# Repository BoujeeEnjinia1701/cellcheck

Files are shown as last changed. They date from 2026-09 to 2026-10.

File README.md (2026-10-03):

# CellCheck

     

**Area:** Circular Materials · **TRL:** 3 of 9 (proof of concept on paper) · **Value-engineering target:** about $175 USD (a hypothetical control target, not a limit) · **Difficulty:** 3 of 5

A second-life battery cell grader: it measures capacity, internal resistance and self-discharge of salvaged lithium cells and sorts them into matched groups for rebuilt packs such as SwapCell.

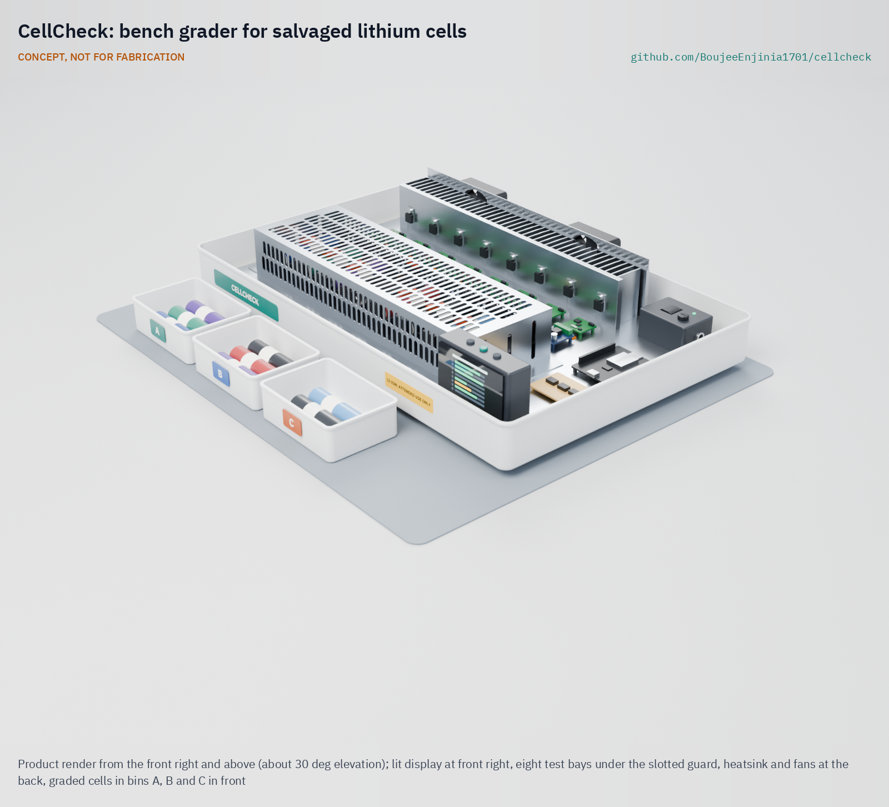
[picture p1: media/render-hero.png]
CellCheck: bench grader for salvaged lithium cells, product render


[Exploded render](media/render-exploded.png) · [Detail render](media/render-detail.png) · [Interactive 3D model](media/viewer.html) · [Concept blueprint (PDF)](media/concept-blueprint.pdf) · [General arrangement CCK-DWG-001 (PDF)](cad/drawings/CCK-DWG-001.pdf) · [Sizing note CCK-CAL-001](docs/04-calcs/01-sizing.md) · [Prototype build plan](docs/05-build-plan.md) · [Design decisions](docs/06-design-decisions.md) · [Review note](docs/REVIEW.md)

## Concept rationale

Most cells in a discarded laptop, power tool or e-bike pack still work, but nobody knows which ones. CellCheck measures the three things that decide whether a cell is worth reusing: how much charge it holds, how much its voltage sags under load (internal resistance) and whether it leaks charge at rest (self-discharge). It then groups good cells so that each parallel group in a rebuilt pack has nearly the same capacity. Eight independent channels, four-wire contacts and a passive 14-day rest rack keep the tool cheap while grading 12 typical cells in an attended 10 h working day (CCK-CAL-001, a paper estimate with no margin).

It is open and garage-buildable because the people who reuse cells are repair shops, makerspaces and small off-grid installers, not laboratories. It uses off-the-shelf charger and current-monitor modules, runs from a certified 12 V adapter so no one wires mains, and writes its thresholds and results to plain files that anyone can check. A published grading method also lets different workshops compare cells on the same terms.

## Burning platform

The world produced 62 million tonnes of e-waste in 2022, and only 22.3 % was documented as collected and recycled; in Africa the figure was below 1 % ([UNITAR, Global E-waste Monitor 2024](https://unitar.org/about/news-stories/press/global-e-waste-monitor-2024-electronic-waste-rising-five-times-faster-documented-e-waste-recycling)). Much of what is thrown away still has value: IBM Research India found that discarded 85 Wh laptop packs kept a median of 73 % of their design capacity ([Chandan et al., ACM DEV 2014](https://www.dgp.toronto.edu/~mjain/UrJar-DEV-2014.pdf)).

Discarded lithium batteries are also a fire hazard. The US EPA found 245 fires at 64 waste facilities from 2013 to 2020 caused, or likely caused, by lithium-ion batteries ([US EPA, 2021](https://www.epa.gov/system/files/documents/2021-08/lithium-ion-battery-report-update-7.01_508.pdf)), and the UK counted more than 1,200 battery fires in bin lorries and waste sites in the year to May 2024 ([National Fire Chiefs Council and Material Focus](https://nfcc.org.uk/over-1200-battery-fires-in-bin-lorries-and-waste-sites-across-the-uk-in-last-year/)). People who rebuild packs from untested cells face the same hazard on their own benches. Grading keeps usable cells in service and sends the rest to proper recycling instead of the bin.

## Where it could be used

### By industry

| Industry | Use |
| --- | --- |
| Electronics and e-bike repair | Sort cells from dead packs, reject bad ones and rebuild matched packs with a record per cell |
| Battery collection and recycling | Separate reusable cells from those that go to recycling at collection points and micro-factories (ReflowEconomy) |
| Off-grid energy | Low-cost graded cells for lights, small storage packs and solar home kits |
| Education and makerspaces | Teach battery health, safety and measurement with a documented, supervised tool |
| Research | Build data sets of second-life cell capacity and resistance with a published method |

### By country or region

| Country or region | Why it matters there |
| --- | --- |
| United Kingdom | More than 1,200 battery fires in bin lorries and waste sites in the year to May 2024, up from about 700 in 2022 ([NFCC and Material Focus](https://nfcc.org.uk/over-1200-battery-fires-in-bin-lorries-and-waste-sites-across-the-uk-in-last-year/)) |
| United States | 245 lithium-ion battery fires at 64 waste facilities from 2013 to 2020 ([US EPA](https://www.epa.gov/system/files/documents/2021-08/lithium-ion-battery-report-update-7.01_508.pdf)); many repair shops and makers already rebuild packs |
| European Union | Collection targets for portable batteries rise to 63 % by the end of 2027 and 73 % by the end of 2030 under the Batteries Regulation ([EPBA summary](https://www.epba.eu/policy/eu-directive/eu-batteries-regulation)), so more cells will reach sorting points |
| India | The Battery Waste Management Rules, 2022 require all waste batteries to be collected and sent for recycling or refurbishment ([Press Information Bureau](https://www.pib.gov.in/PressReleasePage.aspx?PRID=1854433)); refurbishers need a documented way to test cells |
| Kenya and East Africa | Second-life lithium storage lowered the cost of electricity in 97.2 % of modeled scenarios for Kenyan primary schools ([Hirmer et al., Scientific Reports, 2023](https://www.nature.com/articles/s41598-023-28377-7)); Africa formally recycles less than 1 % of its e-waste ([UNITAR](https://unitar.org/about/news-stories/press/global-e-waste-monitor-2024-electronic-waste-rising-five-times-faster-documented-e-waste-recycling)) |
| Colombia and Latin America | Researchers in Colombia measured cells from laptop packs ranging from 0.04 to 2.50 Ah and showed that grouping by measured values builds better packs ([Olivero-Ortiz et al., PLOS One, 2026](https://journals.plos.org/plosone/article?id=10.1371%2Fjournal.pone.0353394)) |

## What sparked the idea

The starting point was UrJar, a 2014 IBM Research India project in Bangalore that rebuilt cells from 32 discarded ThinkPad laptop packs into lighting units for street vendors ([Chandan et al., ACM DEV 2014](https://www.dgp.toronto.edu/~mjain/UrJar-DEV-2014.pdf)). The study showed that most of the packs still held useful capacity, yet after reading each pack's capacity through the laptop, the researchers selected individual cells by checking that their terminal voltage was above 3.7 V. A voltage check says little about a cell's capacity, internal resistance or self-discharge, which decide how long a rebuilt pack lasts and how safely it ages. CellCheck turns that hand check into a repeatable, multi-channel grading step that any repair bench could run.

## Problem

Salvaged lithium cells are cheap but unknown; building packs from untested cells causes early failure and fires. Cells from one pack can differ widely in capacity and resistance, and in a series string the weakest cell limits the pack and is stressed hardest. Single-cell hobby testers are too slow for pack-scale sorting, and closed multi-slot analyzers do not track self-discharge, build matched groups or keep open records.

Full problem statement: [docs/01-problem.md](docs/01-problem.md)

## Concept

A second-life battery cell grader: it measures capacity, internal resistance and self-discharge of salvaged lithium cells and sorts them into matched groups for rebuilt packs such as SwapCell.

Eight channels each charge a cell at 1 A, measure DC internal resistance with a 0.5 A then 2.0 A pulse in the IEC 61960 pattern, discharge at 1 A to measure capacity and recharge until the cell reads 4.10 V under current. Cells then rest 14 days in a printed rack and come back for a voltage check. Software grades each cell (A, B, C or reject) and builds groups for any series and parallel count, with each parallel group within ±1 % of the mean capacity. A hardware watchdog, per-channel undervoltage comparators and 3 A cell fuses cover single faults. The sizing note CCK-CAL-001 finds 6.33 h of channel time per typical cell, 12.0 cells per attended 10 h day, 33.6 W of peak heat with MOSFET cases at about 59 °C, 460 x 300 x 85 mm and 4.91 kg, and $172.40 in parts, $2.60 under the $175 budget.

SwapCell stays in the pitch. Its reference pack uses new high-current cells, which graded laptop cells cannot match, so a second-life variant is planned: the TRL 3 study finds a low-current storage pack for PowerBox (about 334 Wh, 165 W) feasible, and e-bike use is ruled out. Amish decided on 2026-09-25 to go with this recommendation, and on 2026-10-02 to send the study to the SwapCell and PowerBox projects as a proposal; it needs their agreement (see the decision records [CCK-DDR-001](docs/decisions/0001-trl2-review-decisions.md) and [CCK-DDR-002](docs/decisions/0002-recommendations-accepted.md)).

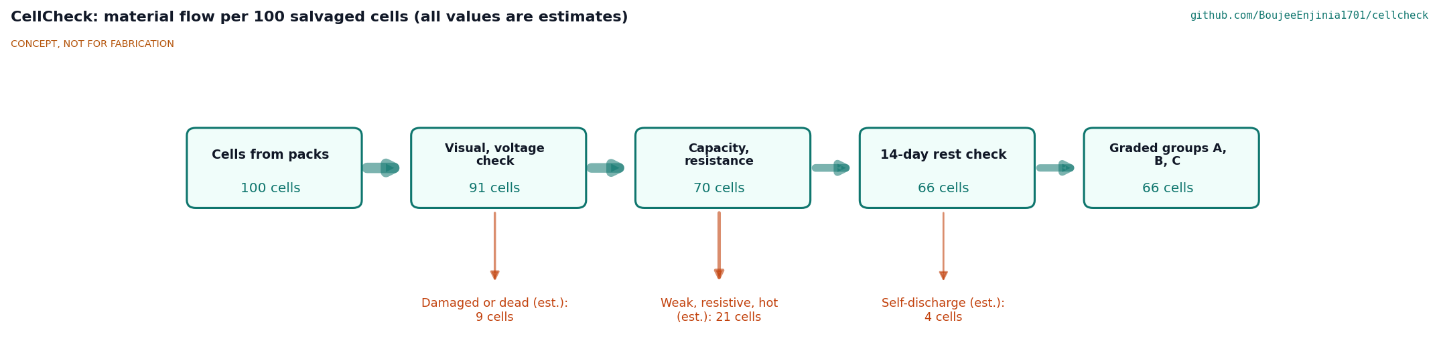
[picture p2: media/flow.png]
Material flow per 100 salvaged cells


Full design precis: [docs/02-concept.md](docs/02-concept.md) · Requirements: [docs/03-requirements.md](docs/03-requirements.md) · Calculations: [docs/04-calcs/01-sizing.md](docs/04-calcs/01-sizing.md)

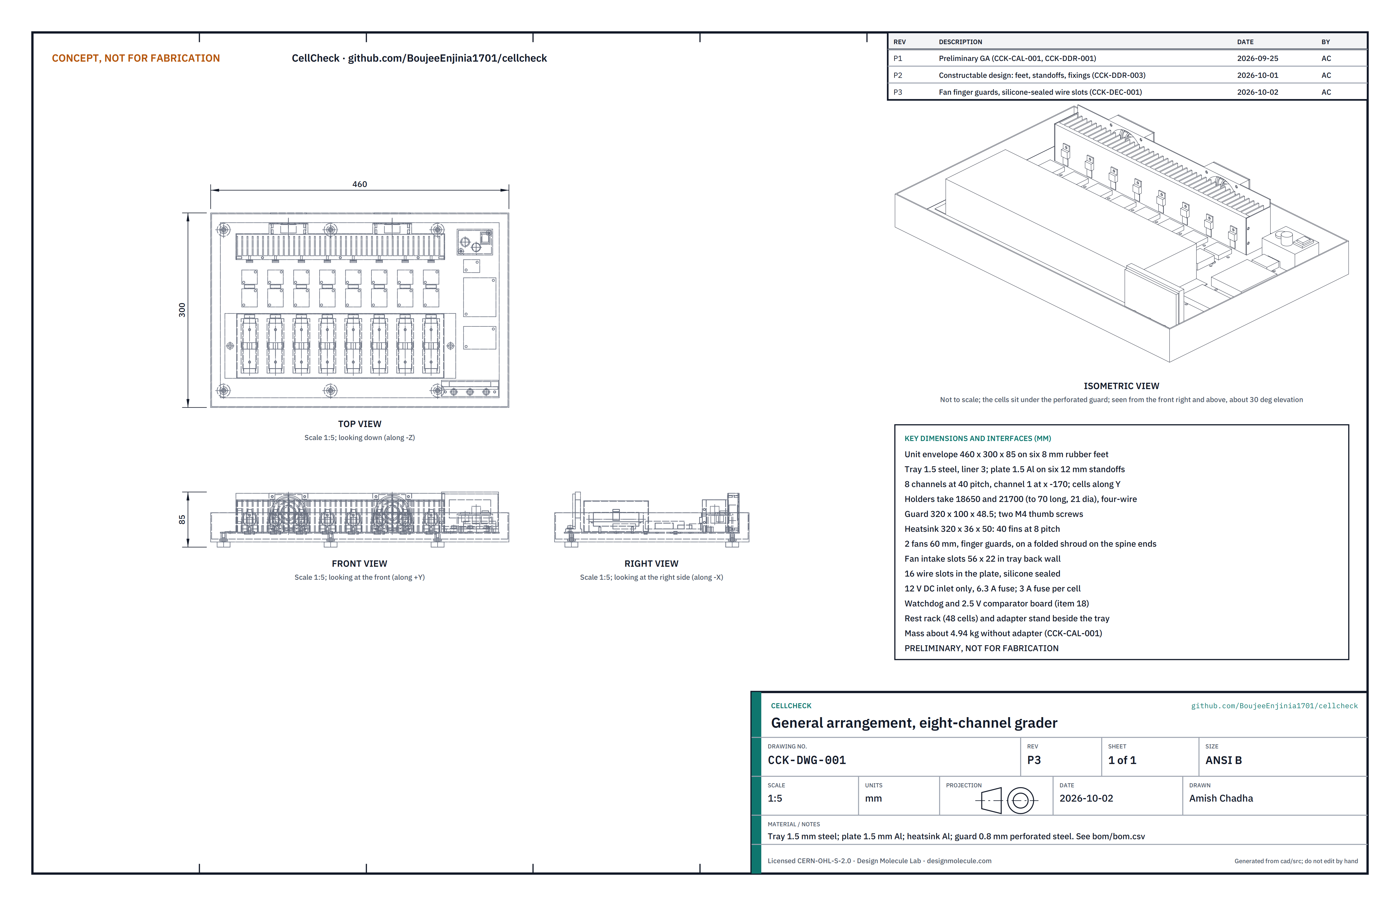
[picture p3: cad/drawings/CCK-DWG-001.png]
General arrangement CCK-DWG-001


On paper CellCheck meets 12 of its 17 requirements, is $2.60 over its value-engineering target (R12) and fails none outright. R5 (throughput), R6 (self-discharge reading) and R11 (mass, 4.94 kg against 5 kg) are at risk; R10 (containment of a venting cell) cannot be verified at TRL 3.

## Key components

- Eight cell holders for 18650 and 21700 cells with four-wire contacts
- Eight 1 A CC-CV charger modules (TP5100 class)
- Eight INA226-class current and voltage monitors with series charge switches
- Eight constant-current MOSFET loads on a fan-cooled heatsink with vertical fins
- Hardware watchdog and per-channel undervoltage comparators
- Temperature sensing per cell (NTC thermistors)
- ESP32-S3 class controller with display, microSD log and local web page, and grading software
- Steel tray with ceramic fibre liner and a perforated steel cell guard
- Certified 12 V 5 A adapter and a printed 48-cell rest rack

The priced bill of materials is in [bom/bom.csv](bom/bom.csv): Value-engineering target: USD 175. Estimated cost of the constructable design: USD 177.60 (USD 2.60 over the target). The fan finger guards and the silicone for the wire slots, both decided on 2026-10-02, account for the $5.20 added since the last estimate.

## Building the prototype

The [prototype build plan](docs/05-build-plan.md) (CCK-BLD-001) shows how to make and fit every component, in pictures generated from the model, in 12 assembly steps with safety stops before any cell or power goes near the unit. The grader is built in a bought steel tray on six rubber feet; an aluminium base plate on six standoffs carries the holders, modules, heatsink and fans, and a folded perforated guard lifts off after two thumb screws to change cells. The work is cutting, drilling, tapping and folding sheet metal, 3D printing four parts and wiring bought modules; no mains wiring and no custom circuit board are needed. The design was made buildable under decision record [CCK-DDR-003](docs/decisions/0003-design-for-construction.md); every design decision, made or open, is in the [design decisions register](docs/06-design-decisions.md).

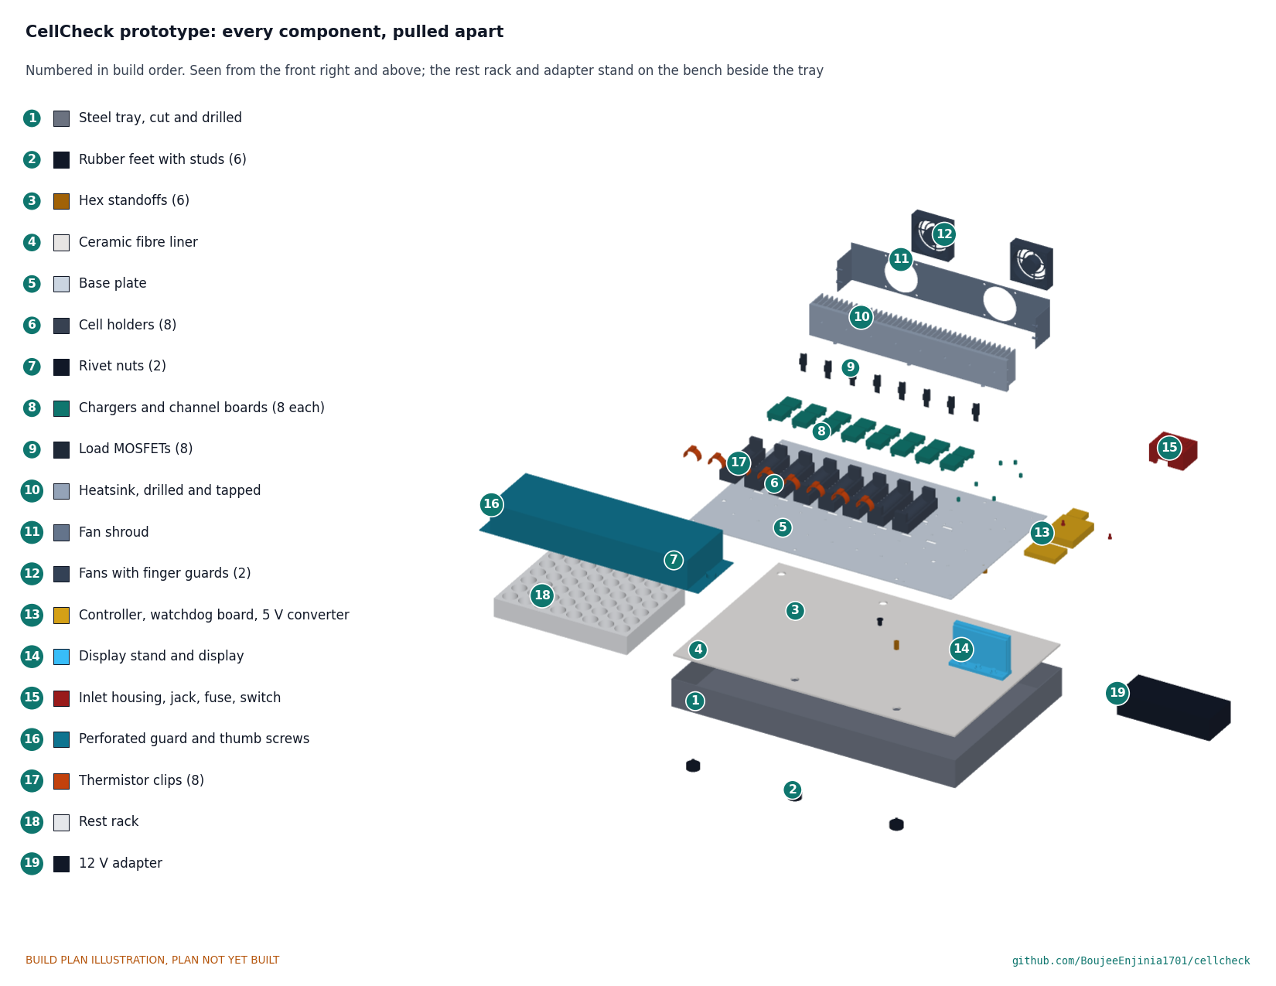
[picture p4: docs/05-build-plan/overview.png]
Every component of the prototype, pulled apart and numbered in build order


## Safety

> Lithium cells can overheat, vent and burn, and salvaged cells can hide damage. Reject damaged cells and any cell below 2.0 V. Grade on a non-flammable surface inside the steel tray, with a smoke alarm and an extinguisher or sand bucket within reach, and stay with the grader whenever a cell is charging or discharging; only cells resting with no current flowing may be left. Isolate any cell that heats or swells in a metal container of sand. Use only a certified 12 V adapter. CellCheck is a research and prototype tool; its grades do not certify any cell or pack as safe.

## Repository layout

| Folder | Contents |
| --- | --- |
| `docs/` | Problem, concept, requirements, calculations and design decisions |
| `cad/src/` | build123d Python source, the source of truth for all geometry |
| `cad/step/`, `cad/stl/` | Exported models for FreeCAD, other CAD tools and printing |
| `cad/drawings/` | General arrangement CCK-DWG-001 (Rev P2) and making sketches CCK-DWG-101 to 110 |
| `bom/` | Bill of materials |
| `electronics/` | KiCad schematics and PCB layouts |
| `firmware/` | Microcontroller code |
| `media/` | Renders, perspectives and photos |
| `build-log/` | Dated prototyping notes |

## Documentation

Controlled documents follow the portfolio [documentation standard](.kit/STANDARDS.md). Each carries a document ID (CCK-PRC-001 for the precis), a version and a revision history. Branded PDFs are built with `python .kit/render.py` and attached to GitHub Releases when a document is tagged, for example `CCK-PRC-001/v1.0`.

## Credits

Designed by Amish Chadha. See [CONTRIBUTORS.md](CONTRIBUTORS.md) for roles. To cite this design, use [CITATION.cff](CITATION.cff) (GitHub shows it as "Cite this repository").

AI assistance (Claude) was used to accelerate concept renders, prototype documentation and first-pass sizing calculations. Design direction and all decisions are Amish Chadha's, recorded in this repository's decision records (`docs/decisions/`).

## Licenses

- **Hardware** (CAD, drawings, BOM, electronics): [CERN-OHL-S v2](LICENSE)
- **Software** (firmware, scripts, notebooks): [MIT](LICENSE-SOFTWARE)

A project of the [Design Molecule](https://designmolecule.com) lab.

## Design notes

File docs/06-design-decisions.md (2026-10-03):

---
doc_id: CCK-DEC-001
title: CellCheck design decisions register
project: CellCheck
doc_type: Design decisions register
version: "0.6"
status: Draft
date: '2026-10-03'
author: Amish Chadha
license: CERN-OHL-S-2.0
revisions:
  - version: "0.1"
    date: '2026-10-01'
    author: Amish Chadha
    change: Register opened with the open decisions from the review note and decision records, the build plan work and every decision made so far
  - version: "0.2"
    date: '2026-10-01'
    author: Amish Chadha
    change: Budget treated as a value-engineering target
  - version: "0.3"
    date: '2026-10-02'
    author: Amish Chadha
    change: Amish approved the recommendations of open items 1 to 11 on 2026-10-02; all moved to decisions made; value-engineering savings line updated
  - version: "0.4"
    date: '2026-10-02'
    author: Amish Chadha
    change: "Design for construction (CCK-DDR-003, P1 to P12) accepted by Amish on 2026-10-02; the 2026-10-01 row no longer says open for review"
  - version: "0.5"
    date: '2026-10-02'
    author: Amish Chadha
    change: "Estimated cost updated to $177.60 ($2.60 over the target) after the fan finger guards and silicone were priced; open decision 1 added for the overshoot"
  - version: "0.6"
    date: '2026-10-03'
    author: Amish Chadha
    change: "Amish accepted the cost overrun against the value-engineering target on 2026-10-03; row added to decisions made; value engineering section updated"
---

# CellCheck design decisions register

Every design decision still to be made, and every decision made, in one place. Each decision is argued in full in its decision record under `docs/decisions/`; this register is the index Amish works from. The build plan (`docs/05-build-plan.md`) describes the design as it stands and does not list open decisions.

## Open decisions

None. Open decision 1 (the USD 2.60 overshoot) was decided on 2026-10-03.

## To confirm when parts are bought

*Table 2. Items to check against the parts before building.*

| # | What to confirm | Why it matters | Source |
| --- | --- | --- | --- |
| 1 | The steel tray is plain steel, about 460 x 300 x 45 mm with 1.5 mm walls, and its flat floor is at least 457 x 297 mm inside | The liner, plate and containment estimate assume it | CCK-DDR-003, P1 |
| 2 | The rubber feet have M4 studs about 8 mm long | The stud must pass the 1.5 mm floor and engage the standoff | CCK-DDR-003, P1 |
| 3 | The M4 rivet nuts grip 1.5 mm sheet and their heads are under 1 mm thick | The guard flange sits round the head | CCK-DDR-003, P4 |
| 4 | The cell holders have two M3 fixing holes in their base and take 18650 and 21700 cells up to 70 mm | Holder screws and the 84 mm holder length | CCK-DDR-003, P3 |
| 5 | The charger modules, current monitor breakouts, controller and converter have M3 mounting holes (or are fixed to a small perfboard that has them) | Each board stands on two nylon standoffs | CCK-DDR-003, P5 |
| 6 | The 2.8 in display module is about 86 x 50 mm with four corner holes | Display stand size | CCK-DDR-003, P6 |
| 7 | The heatsink spine is 6 mm thick, 50 mm tall, and has a fin gap at 20 mm from the left end and every 40 mm after it | MOSFET screws go between fins; plate and shroud screws are tapped into the spine | CCK-DDR-003, P7 |
| 8 | The fans have a 50 mm square screw pattern | Shroud holes | CCK-DDR-003, P8 |
| 9 | The DC jack, fuse holder and rocker switch cut-out sizes against the inlet housing (11.2 mm, 12 mm, 12 x 16 mm) | Inlet housing holes | CCK-DDR-003, P10 |
| 10 | A sourced figure for the heat released by one 21700 cell in thermal runaway, to replace the assumed 100 kJ | Containment estimate before any TRL 4 work | CCK-CAL-001 section 7 |

## Value engineering

Value-engineering target: USD 175.00 (a hypothetical control target, not a limit). Estimated cost of the constructable design: USD 177.60 (USD 2.60 over the target).

Amish accepted this overrun on 2026-10-03: the estimated cost of USD 177.60 against the USD 175 target (USD 2.60 over; open decision 1, option a). Amish: "Cost over target - i accept all the cost variations and overruns". It stays reported against the target as an accepted overrun, and the savings below remain worth trying.

Main cost drivers (CCK-CAL-001, section 11): the per-channel parts, which are bought eight times (cell holder with four-wire contacts, charger module, channel board, load MOSFET and op-amp loop, thermistor: about $66 for the eight channels), the mains adapter ($15), the steel tray with liner ($12) and the controller board ($10). The parts added for construction (lines 19 to 21) cost $8.40.

Savings worth trying, should indicative prices rise above the target:

- Leave the matched-group bins out of the BOM until TRL 4 purchasing (decided 2026-10-02). The fan finger guards (line 10, $1.20 for two) and the silicone for the wire slots (line 16, $4.00) decided on 2026-10-02 are now in the estimate; they are the reason it is over the target (accepted by Amish on 2026-10-03).
- Look for a cheaper cell holder or charger module, since each saving is multiplied by eight.

## Decisions made

*Table 3. Decisions made, with dates and records.*

| Date | Decision | Decided by | Record |
| --- | --- | --- | --- |
| 2026-09-25 | Keep SwapCell in the pitch and plan a second-life variant; charge and discharge attended only (rest stage may be left); hardware watchdog and undervoltage comparators; grading thresholds, 14-day rest and ±1 % group tolerance as starting values; TP5100, INA226 and ESP32-S3 class modules; eight channels with a linear load; LFP profile later; per-cell CSV mapped to the ReflowEconomy passport (items 1 to 3 and 5 to 9) | Amish: "i accept all your recommendations, go with them across all repos." | CCK-DDR-001, CCK-DDR-002 |
| 2026-09-25 | Budget raised from $160 to $175 (item 4) | Amish, same instruction | CCK-DDR-001, CCK-DDR-002 |
| 2026-09-25 | DC four-wire resistance and a 14-day rest (item 11); firmware and build rules: same-channel cohort self-discharge reading, temperature-gated resistance pulse, per-channel calibration, fan-fault stop, detached-thermistor check (item 13); raise the passport gaps with ReflowEconomy (item 15) | Amish, same instruction | CCK-DDR-001, CCK-DDR-002 |
| 2026-10-01 | Design for construction: feet and standoffs, 1.5 mm plate on six standoffs, holder fixings and wire slots, folded guard with thumb screws, board standoffs, larger display stand, heatsink and shroud fixings, thermistor C-clips, inlet housing, 5 V converter and channel boards (P1 to P12) | Made under Amish's 2026-09-30 instruction: "If you are realising that the design cannot be built as per concept - fix the design assumptions to match and be physically feasible as you draw the illustrations." The changes themselves were accepted on 2026-10-02 (below) | CCK-DDR-003 |
| 2026-10-02 | Open item 1: the guard is held down by the two knurled M4 thumb screws for the first prototype, and the TRL 4 containment test is run with the guard held exactly that way; latches are revisited only if the test or users show the screws being left loose | Amish: "i approve your recommendations for all 555 open decisions." | CCK-DDR-003, A1 |
| 2026-10-02 | Open item 2: each wire slot under the guard is filled round its leads with high-temperature silicone after wiring, closing the guard space again | Amish: "i approve your recommendations for all 555 open decisions." | CCK-DDR-003, A2 |
| 2026-10-02 | Open item 3: first trial partner, the first candidate to approach (not yet agreed), is a local Repair Café group that already passes laptop batteries to an e-waste or battery collection point, with that collection point as the source of trial cells | Amish: "i approve your recommendations for all 555 open decisions." | CCK-DDR-001, item 10 |
| 2026-10-02 | Open item 4: scheduling rule for the attended day: a charge or discharge starts only if it will finish the same day (12.0 cells per day); no overnight pause | Amish: "i approve your recommendations for all 555 open decisions." | CCK-DDR-001, item 12 |
| 2026-10-02 | Open item 5: R11, the 4.91 kg mass is accepted with the 1.5 mm tray kept, and the prototype is weighed at TRL 4; R5, throughput rests on the same-day rule of item 4, and more channels are left for a later version | Amish: "i approve your recommendations for all 555 open decisions." | CCK-DDR-001, item 14; CCK-CAL-001 section 8 |
| 2026-10-02 | Open item 6: 60 mΩ stays the grade A default; per-model limits are added only for the few cell models most common in the partner's intake, set from DC resistance measured on known-good cells of each model, not from data sheet impedance | Amish: "i approve your recommendations for all 555 open decisions." | CCK-DDR-001, item 16 |
| 2026-10-02 | Open item 7: 18650 cells accepted in the product renders; the model keeps the 21700 envelope for clearance checks | Amish: "i approve your recommendations for all 555 open decisions." | `docs/REVIEW.md`, 2026-09-26 |
| 2026-10-02 | Open item 8: the matched-group bins are render context only for now; a BOM line is decided at TRL 4 purchasing | Amish: "i approve your recommendations for all 555 open decisions." | `docs/REVIEW.md`, 2026-09-26 |
| 2026-10-02 | Open item 9: fan finger guards are added to BOM line 10 now, with an estimated price, rather than at TRL 4 | Amish: "i approve your recommendations for all 555 open decisions." | `docs/REVIEW.md`, 2026-09-26 |
| 2026-10-02 | Open item 10: the guard's slotted perforation and 1.0 mm sheet in the renders are accepted as appearance only; the BOM keeps round holes in 0.8 mm sheet | Amish: "i approve your recommendations for all 555 open decisions." | `docs/REVIEW.md`, 2026-09-26 |
| 2026-10-02 | Open item 11: the second-life pack study (about 334 Wh, 165 W) is sent to the SwapCell and PowerBox projects as a proposal; no further CellCheck action | Amish: "i approve your recommendations for all 555 open decisions." | CCK-DDR-001, item 1; CCK-CAL-001 section 10 |
| 2026-10-02 | Design for construction accepted: the changes P1 to P12 and their knock-on changes, as made | Amish: "APPROVED: Design-for-construction changes in 10 repos (CityTwin, CoolShade, PalletPilot, Heliolite, PotholeLog, EarthPress, ReadyKit, CellCheck, CargoMule and ThermaCart)" | [CCK-DDR-003](decisions/0003-design-for-construction.md), Tables 1 and 2 |
| 2026-10-03 | Cost overrun accepted: the estimated cost of USD 177.60 against the USD 175 target (USD 2.60 over; open decision 1, option a) | Amish: "Cost over target - i accept all the cost variations and overruns" | [REVIEW.md](REVIEW.md), session 2026-10-03 |

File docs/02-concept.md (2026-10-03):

---
doc_id: CCK-PRC-001
title: CellCheck design precis
project: CellCheck
doc_type: Design precis
version: "0.8"
status: Draft
date: '2026-10-02'
author: Amish Chadha
license: CERN-OHL-S-2.0
revisions:
- version: "0.1"
  date: '2026-09-25'
  author: Amish Chadha
  change: Initial scaffold
- version: "0.2"
  date: '2026-09-25'
  author: Amish Chadha
  change: Populate to TRL 2 (architecture, grading method, first-order numbers, safety, media)
- version: "0.3"
  date: '2026-09-25'
  author: Amish Chadha
  change: Apply CCK-DDR-001 (design choices adopted for TRL 3, open for Amish's review); numbers replaced by CCK-CAL-001; watchdog and undervoltage board added; heatsink fins turned in line with the airflow; general arrangement CCK-DWG-001
- version: "0.4"
  date: '2026-09-25'
  author: Amish Chadha
  change: Recommendations accepted by Amish (DDR-002). Budget $175; firmware rules for the resistance pulse, self-discharge reading, fan fault and thermistor plausibility; numbers from CCK-CAL-001 v0.2
- version: "0.5"
  date: '2026-10-01'
  author: Amish Chadha
  change: Design made constructable (CCK-DDR-003); component table, size, mass and cost from CCK-CAL-001 v0.3; build plan CCK-BLD-001
- version: "0.6"
  date: '2026-10-01'
  author: Amish Chadha
  change: Budget treated as a value-engineering target; cost wording only, no number changed
- version: "0.7"
  date: '2026-10-02'
  author: Amish Chadha
  change: 'Decisions of 2026-10-02 carried in (CCK-DEC-001 items 1, 2, 4 to 6, 9 and 11): scheduling rule, grade A limit, containment hold-down and slot sealing, fan finger guards, pack study; open questions closed'
- version: "0.8"
  date: '2026-10-02'
  author: Amish Chadha
  change: "Size, mass and cost figures updated for the fan finger guards and silicone (4.94 kg; $177.60, $2.60 over the value-engineering target; CCK-CAL-001 v0.6)"
---

# CellCheck design precis

## Summary

CellCheck is an eight-channel bench grader for salvaged 18650 and 21700 lithium-ion cells. Each channel charges one cell, measures its DC internal resistance with a two-step current pulse, discharges it at a constant 1 A to measure capacity, and recharges it for a 14-day self-discharge rest. Software then sorts the passing cells into grades and builds matched groups for a pack of a chosen series and parallel count, with a record for every cell. The calculation note CCK-CAL-001 finds 6.33 h of channel time per typical cell, 12.0 cells per attended 10 h day, MOSFET cases at 58.7 °C at full load and $172.40 in parts, $2.60 under the $175 value-engineering target that Amish accepted on 2026-09-25 to cover the single-fault protection added for TRL 3. Every figure is a paper estimate; nothing has been built or measured.

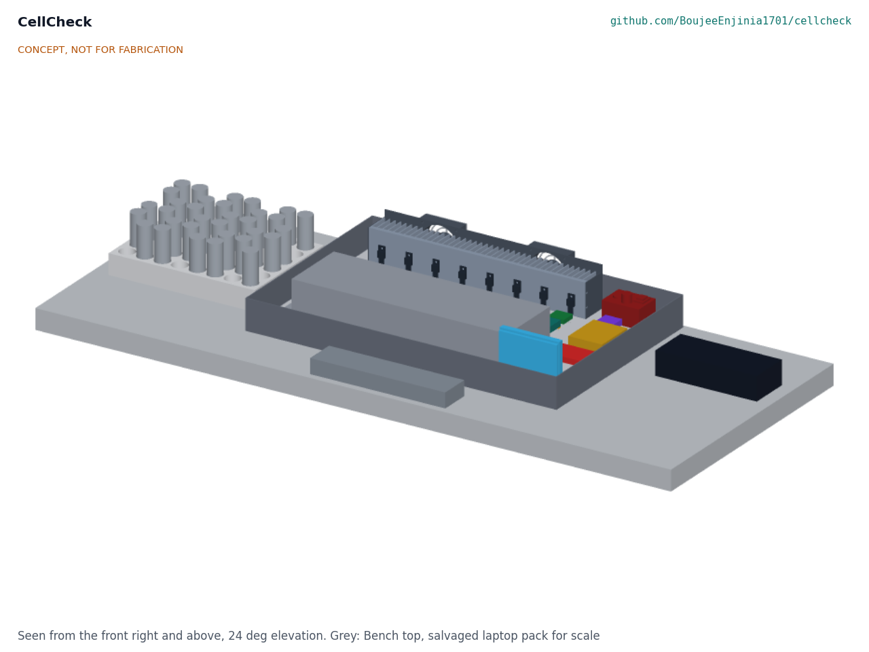
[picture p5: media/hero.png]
CellCheck on a bench with its rest rack and a salvaged laptop pack


*Figure 1. Massing model on a bench: steel tray with eight cell channels (center), rest rack for the self-discharge check (left), 12 V adapter (right) and a salvaged laptop pack (front) for scale.*

## How it works

1. **Intake (by hand).** The operator removes cells from a pack, rejects any with dents, torn wraps, leaks or corrosion, measures open-circuit voltage and rejects cells below 2.0 V. Each cell gets an ID label. Cells below 2.0 V are not revived: deep discharge can grow copper dendrites that cause internal shorts when the cell is charged again.
2. **Charge.** The cell goes into a channel. A 1 A CC-CV charger module brings it to 4.20 V and stops at 0.1 A (about 1.8 h for a 1.8 Ah cell). A thermistor clipped to the cell stops the channel if the cell passes 45 °C or rises more than 8 K above the bench. If a cell's reading does not rise at all during charge or discharge, the firmware treats the clip as detached and stops the channel.
3. **Rest and resistance.** After a 30 min rest, and only once the cell is within 1 K of the bench reading (a firmware rule, CCK-DDR-001 item 13), the channel runs a DC resistance test in the pattern of IEC 61960: 0.5 A for 10 s, then 2.0 A for 1 s, with resistance taken as the change in voltage over the change in current ([test pattern summarized by Arbin Instruments](https://www.arbin.com/how-to-perform-internal-resistance-measurement-accroding-to-iec-61960-with-arbin.html)). IEC 61960 uses 0.2C and 1C; CellCheck uses fixed currents so results are comparable within a batch, not with data sheet values.
4. **Capacity.** A linear constant-current load discharges the cell at 1.0 A to 2.80 V while a current monitor integrates ampere-hours and watt-hours. Cell temperature is logged throughout; a cell that heats abnormally is flagged.
5. **Recharge for rest.** The charger runs at 1 A until the cell's terminal voltage reads 4.10 V under current, at about 80 % state of charge, and the firmware then opens the charge switch. The operator moves the cell to the printed rest rack, which holds 48 cells.
6. **Self-discharge check.** After 14 days the operator puts the cell back into a channel for a 10 s open-circuit reading. Each cell goes back into the channel it was graded in, which keeps the reading within ±2.3 mV (CCK-CAL-001 v0.2), and its drop is compared with the median drop of the cells charged the same day. A drop of more than 50 mV beyond that median marks the cell as rejected (CCK-DDR-001 item 13, decided by Amish, 2026-09-25).
7. **Grade and match.** Software assigns a grade from capacity, resistance, heating and self-discharge (Table 2), then builds groups for the pack the user wants (for example 4S6P): it picks the cells of one grade with the narrowest capacity window, distributes them with a serpentine sort and swaps cells between groups until each parallel group's total capacity is within ±1 % of the mean. On synthetic data the groups come out within 0.006 % (CCK-CAL-001 section 9). Serpentine sorting of retired 18650 cells has been studied as a grouping method ([Xi et al., Batteries, 2026](https://www.mdpi.com/2313-0105/12/9/368)), and clustering by measured capacity and resistance produced a markedly better second-life pack than random selection in a recent study ([Olivero-Ortiz et al., PLOS One, 2026](https://journals.plos.org/plosone/article?id=10.1371%2Fjournal.pone.0353394)).
8. **Record.** Every cell gets a CSV row: ID, source pack, cell model if known, arrival voltage, capacity, resistance, temperature rise, self-discharge, grade, group and dates. Each matched group and each lot of rejected cells also gets a ReflowEconomy material passport record (CCK-CAL-001 section 13). Rejected cells go to a battery collection point for recycling.

Material flow per 100 salvaged cells

*Figure 2. Material flow per 100 cells taken from salvaged packs (all values are estimates). The first loss draws on the 4.3 % of cells with surface damage found by [Salinas et al. (2019)](https://www.sciencedirect.com/science/article/abs/pii/S2352152X18308399) plus an assumed 5 % below 2.0 V; the other losses are assumptions to be checked with real cells.*

## Main components

Table 1. Main components, numbered as in the exploded view (Figure 3), `bom/bom.csv` and the general arrangement CCK-DWG-001.

| # | Component | Choice | Notes |
| --- | --- | --- | --- |
| 1 | Steel tray with liner | 460 x 300 x 45 mm steel tray, 1.5 mm, 3 mm ceramic fibre sheet on the floor, two fan intake slots in the back wall | Contains ejecta from a venting cell; the whole unit sits in it |
| 2 | Base plate | 1.5 mm aluminium, 430 x 270 mm, on six standoffs screwed to the tray through rubber feet (line 19) | Carries all modules |
| 3 | Cell holders | Eight holders for 18650 and 21700 at a 40 mm pitch with spring contacts, separate force and sense contacts at each end (four-wire) | Kelvin sensing keeps contact resistance out of the reading |
| 4 | Temperature sensing | 10 kΩ NTC thermistor in a printed C-clip on each cell | Read by the controller's ADC, ±1.0 K at 45 °C |
| 5 | Cell guard | Folded perforated steel cover over the cells, held by two thumb screws | Stops loose ejecta; cells stay visible; lifts off to change cells |
| 6 | Chargers | 1 A CC-CV buck charger module per channel, 4.20 V, fed from 12 V (TP5100 class) | Module sets its own voltage limit, independent of firmware |
| 7 | Channel boards | INA226-class current and voltage monitor with a 25 mΩ shunt on a perfboard with the series charge switch, the op-amp of the load loop and the 3 A channel fuse, per channel | 16-bit readings over I2C at addresses 0x40 to 0x47; calibrated per channel at build |
| 8 | Load MOSFETs | Logic-level MOSFET in TO-220 with an op-amp loop per channel, constant current 0.5 to 2.0 A | Linear load; energy ends up as heat |
| 9 | Heatsink | Aluminium spine 320 x 6 x 50 mm with 40 vertical fins 30 mm deep at 8 mm pitch | 0.58 K/W with the fans (CCK-CAL-001) |
| 10 | Fans | Two 60 mm 12 V fans with tachometers on a shroud behind the fins, pushing air forward into the fin channels | Air leaves through the open fin tops |
| 11 | Controller | ESP32-S3 class board | Runs the test sequence, logs to microSD, serves a local web page |
| 12 | Display and buttons | 2.8 in display with three buttons on a printed stand | Channel status without a laptop |
| 13 | Power inlet | DC jack, 6.3 A main fuse, switch in a printed housing | Only 12 V DC enters the unit |
| 14 | Power supply | Certified 12 V 5 A mains adapter | No mains wiring inside CellCheck |
| 15 | Rest rack | 3D-printed rack for 48 cells, numbered slots | Holds cells for the 14-day check |
| 18 | Watchdog and undervoltage board | Hardware watchdog gating all charge and load enables; eight 2.5 V comparators removing load gate drive | Added for R9 (CCK-DDR-001 item 3) |
| 21 | 5 V converter | 12 V to 5 V 3 A buck converter | Feeds the controller, display and channel boards (CCK-DDR-003) |

Lines 16 (wiring and 3 A channel fuses) and 17 (labels and insulator rings) are in the BOM but not modelled; line 19 (rubber feet) is drawn with the tray and line 20 (fixings) with the parts they hold. The general arrangement drawing is CCK-DWG-001 Rev P2 (`cad/drawings/CCK-DWG-001.pdf`), generated from `cad/src/model.py`.

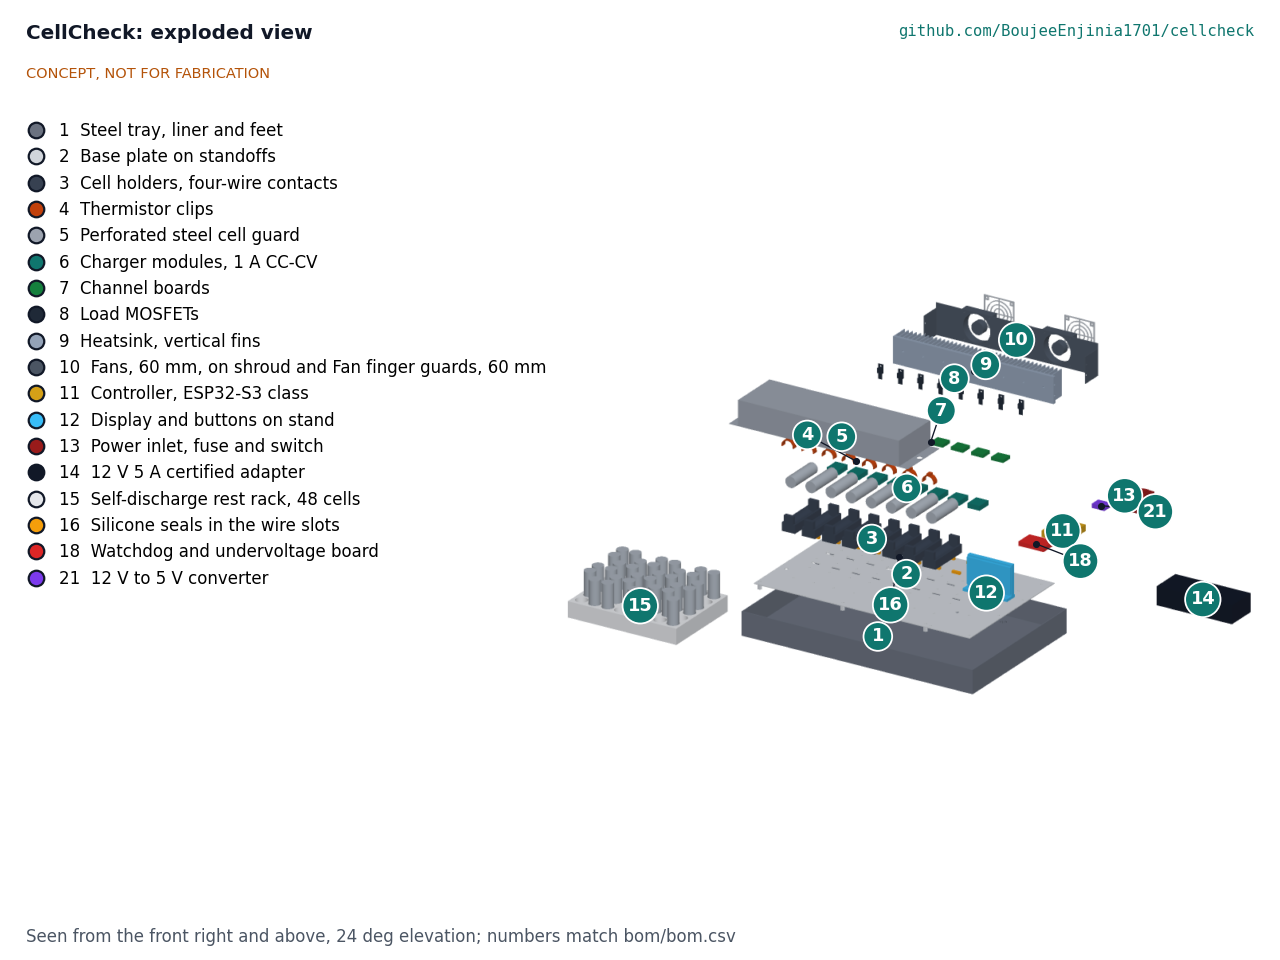
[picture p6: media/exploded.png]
Exploded view with BOM numbers


*Figure 3. Exploded view. Numbers match Table 1 and `bom/bom.csv`. Grey cells are not supplied.*

## Grading rules

Table 2. Grades. The thresholds are starting values decided by Amish on 2026-09-25 (CCK-DDR-001 item 5), to be tuned with the first 100 real cells at TRL 4, which is on hold. All live in a plain configuration file.

| Grade | Capacity, share of rated | DC resistance (18650 default) | Other conditions | Suggested use |
| --- | --- | --- | --- | --- |
| A | 80 % or more | 60 mΩ or less | Temperature rise 8 K or less at 1 A; self-discharge 50 mV or less in 14 days | Storage packs at 0.5C or less |
| B | 65 % or more | 100 mΩ or less | As A | Storage and lighting packs at 0.3C or less |
| C | 50 % or more | 150 mΩ or less | As A | Low-drain uses only: lights, small sensor nodes |
| Reject | Below 50 % | Above 150 mΩ | Or any failed condition, arrival voltage below 2.0 V, or visible damage | Battery recycling |

Rated capacity comes from the cell model printed on the wrap, looked up in a cell table; if the model is unknown, the grade uses measured capacity only and the record says so. The 60 mΩ default for grade A is an assumption for a typical laptop 18650 in good health; Amish decided on 2026-10-02 (CCK-DEC-001, item 6) to keep it as the default and to add per-model limits only for the few cell models most common in the trial partner's intake, set from DC resistance measured on known-good cells of each model. Data sheet impedance is not used, because it is normally a 1 kHz AC value and reads lower than CellCheck's DC pulse. At 1 A a 60 mΩ cell warms by about 1.4 K and the worst 418 mΩ cell reported by Olivero-Ortiz et al. by about 10 K, so the 8 K limit separates them.

## Key numbers

All values come from CCK-CAL-001 and are paper estimates.

Table 3. Key numbers.

| Quantity | Value | Requirement |
| --- | --- | --- |
| Channel time per cell | 6.33 h for 1.8 Ah; 8.30 h for 2.5 Ah; 13.93 h for a 4.5 Ah 21700 | |
| Throughput | 12.0 cells per attended 10 h day: a current stage starts only if it finishes the same day (decided 2026-10-02; the overnight pause, 12.8, is not used) | R5 at risk |
| Cells for one 4S6P pack | about 36 candidates, about 3 attended days plus the 14-day rest | |
| Capacity error | ±1.1 % without calibration, ±0.4 % with | R2 met |
| Voltage error | ±12.4 mV without calibration, ±4.8 mV after per-channel calibration | R3 met with calibration |
| Resistance | 0.83 mΩ per count; repeatability ±2.09 mΩ worst case at 60 mΩ with the pulse gated within 1 K | R4 met |
| Self-discharge reading | ±2.3 mV in the same channel, against the same-day cohort median; relaxation spread not bounded | R6 at risk |
| Heat at full discharge load | 29.2 W average, 33.6 W peak | |
| Heatsink | 0.58 K/W with fans (1.07 K/W needed); MOSFET cases 58.7 °C at 35 °C room; about 99 °C if the fans stop | R8 met |
| Adapter load, all channels charging | 42.5 W of 60 W; 3.54 A at 12 V | R13 met |
| Energy per cell from the mains | 16.8 Wh, well under $0.01 at $0.15/kWh | |
| Size and mass | 460 x 300 x 85 mm; 4.94 kg without adapter | R11 at risk |
| Parts cost | $177.60 estimated against the $175 value-engineering target | R12 over the value-engineering target ($2.60 over) |

## Key design choices

These were decided by Amish on 2026-09-25 (CCK-DDR-001 and CCK-DDR-002: go with recommendation).

- **Linear load, eight channels (item 7).** Discharge energy (6.6 Wh per typical cell) is burned in MOSFETs on one heatsink. A bidirectional converter per channel would recover it but costs more than the value-engineering target allows. Sixteen channels and regenerative discharge are later variants.
- **Modules (item 6).** TP5100-class charger, INA226-class monitor with a 25 mΩ shunt, ESP32-S3 class controller.
- **Single-fault protection (item 3).** A hardware watchdog removes all charge enables and load gate drive when the controller stops; a per-channel comparator removes load gate drive below 2.5 V; each cell has a 3 A fuse and a series charge switch.
- **Attended operation (item 2).** Charge, pulse and discharge run only with a person present; the rest stage may be left.
- **Four-wire DC resistance and a 14-day rest (item 11).** DC pulses (no signal generator; closer to behaviour under load) and 14 days (7 days catches only the worst cells).
- **Firmware and build rules (item 13).** The resistance pulse starts only within 1 K of the bench; self-discharge is read in the same channel and against the same-day cohort median; each channel gets a two-point voltage calibration at build; discharges stop on a fan or heatsink fault; a thermistor that shows no rise during current flow is treated as detached. These are rules for the firmware sketch; writing, calibrating and testing them is TRL 4 work and on hold.
- **Value-engineering target (item 4).** $175 in parts, a hypothetical control target, not a limit, raised from $160 to cover the single-fault protection with margin.
- **12 V DC input only.** A certified adapter keeps mains out of the unit, so builders never wire mains.
- **Local-first data (item 9).** Records stay on the microSD card and the local web page; no cloud account is needed. Groups and reject lots map to ReflowEconomy's material passport v0.2.
- **Lithium-ion first, LFP later (item 8).** The first release covers LCO, NMC and NCA cells at 4.20 V. An LFP profile (3.65 V charge, 2.5 V discharge limit) follows once the lithium-ion profile is proven.
- **Heatsink orientation.** The TRL 2 model had fins across the fan airflow. The fins are now vertical plates normal to the heatsink length, so the fans push air along the channels and out of the top.

## Relation to other lab projects

- **SwapCell.** The pitch keeps SwapCell (CCK-DDR-001 item 1, decided by Amish, 2026-09-25). SwapCell's reference pack uses new 5 Ah 21700 cells carrying 10 A continuous each, which graded laptop cells cannot match. The TRL 3 study (CCK-CAL-001 section 10) finds a 13S4P second-life pack of grade A cells feasible as a low-current storage pack for PowerBox, about 334 Wh and 165 W, with PowerBox's AC output limited to about 150 W; e-bike use is ruled out. The variant needs the SwapCell project's agreement and its own pack design. Decided by Amish, 2026-10-02 (CCK-DEC-001, item 11): the study is sent to the SwapCell and PowerBox projects as a proposal, and CellCheck takes no further action on it.
- **CellGuard.** Packs rebuilt from graded LFP cells would use CellGuard; lithium-ion packs depend on CellGuard's NMC profile, which was decided for CellGuard on 2026-09-25 (hardware for both, LFP firmware first).
- **ReflowEconomy.** CellCheck is the grading step for the battery stream in ReflowEconomy's micro-factory, where cells that cannot be reused are exported for industrial recycling. Two passport schema gaps are raised with that project (CCK-DDR-001 item 15).

## Safety

> **Safety:** Salvaged lithium-ion cells can have hidden damage and can overheat, vent flammable and toxic gas, and burn. Work on a non-flammable surface, with a smoke alarm and a Class D or large dry-powder extinguisher or a sand bucket within reach. Stay with the grader whenever a cell is charging or discharging; only cells resting with no current flowing may be left.

- **Pack disassembly.** Removing spot-welded nickel strip can short cells or tear wraps. Use insulated tools, cut one strip at a time, wear eye protection and gloves, and tape exposed terminals.
- **Damaged and deeply discharged cells.** Reject cells with any visible damage and cells below 2.0 V. Do not try to revive them.
- **Charging.** Each charger module limits voltage to 4.20 V by itself; the firmware adds voltage, current, temperature and time limits and opens the series charge switch. A cell that passes 45 °C or rises 8 K above the bench is disconnected and flagged; the operator moves it to a metal container of sand once it is cool.
- **Single faults.** The watchdog, undervoltage comparators and 3 A channel fuses cover the faults in R9 on paper (CCK-CAL-001 Table 3). A thermistor clip that falls off is caught only by the plausibility check, which is untested, so it remains a residual risk. None of this is tested.
- **Heat.** MOSFET cases reach about 59 °C with the fans running and could approach 99 °C if both fans stopped, so the firmware stops discharges on a fan or heatsink fault. Keep hands off the heatsink during discharge.
- **Containment.** The steel tray, ceramic fibre liner and steel guard are meant to hold ejecta from one venting cell. This cannot be verified on paper and must not be relied on. The fan intake slots are an opening in the tray wall. The guard is held by two thumb screws, and the TRL 4 containment test is to be run with it held that way; the wire slots under the guard are sealed round their leads with high-temperature silicone after wiring (CCK-DEC-001, items 1 and 2, decided 2026-10-02).
- **Fans.** The two fans carry finger guards (CCK-DEC-001, item 9).
- **Transport and storage.** Store graded cells at about 3.7 V in a non-flammable container with terminals covered. Rejected cells go to a battery collection point, never to household waste.
- **Scope.** CellCheck is a research and prototype tool. Its grades do not certify any cell or pack as safe.

## Open questions

- [x] First trial partner (item 10). Decided 2026-10-02: a local Repair Café group that passes laptop batteries to a collection point is the first candidate to approach, with that collection point as the source of trial cells.
- [x] Scheduling rule for the attended day (item 12). Decided 2026-10-02: a current stage starts only if it finishes the same day.
- [x] Responses to R11 and R5 (item 14). Decided 2026-10-02: accept the mass (4.91 kg then, 4.94 kg with the finger guards and silicone) with the 1.5 mm tray and weigh at TRL 4; throughput by the same-day rule, more channels later.
- [x] Grade A resistance limit per cell model (item 16). Decided 2026-10-02: 60 mΩ default; per-model limits from measured DC resistance for the commonest models only.
- [ ] ReflowEconomy passport gaps: decided to raise with that project (item 15); cross-repo action.

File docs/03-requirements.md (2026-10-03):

---
doc_id: CCK-REQ-001
title: CellCheck requirements
project: CellCheck
doc_type: Requirements
version: "0.8"
status: Draft
date: '2026-10-02'
author: Amish Chadha
license: CERN-OHL-S-2.0
revisions:
- version: "0.1"
  date: '2026-09-25'
  author: Amish Chadha
  change: Initial scaffold
- version: "0.2"
  date: '2026-09-25'
  author: Amish Chadha
  change: First measurable requirements for TRL 2
- version: "0.3"
  date: '2026-09-25'
  author: Amish Chadha
  change: Apply CCK-DDR-001 (R14 redefined, R9 protection adopted, R3 calibration, R12 against both budgets); status table from CCK-CAL-001
- version: "0.4"
  date: '2026-09-25'
  author: Amish Chadha
  change: Recommendations accepted by Amish (DDR-002). R12 target $175 and met; R4 met with the temperature-gated pulse; R6 read in the same channel; status table from CCK-CAL-001 v0.2
- version: "0.5"
  date: '2026-10-01'
  author: Amish Chadha
  change: R11 and R12 values for the constructable design (CCK-DDR-003, CCK-CAL-001 v0.3); no status changed
- version: "0.6"
  date: '2026-10-01'
  author: Amish Chadha
  change: Budget treated as a value-engineering target; cost wording only, no number changed
- version: "0.7"
  date: '2026-10-02'
  author: Amish Chadha
  change: R5 and R11 status notes record the 2026-10-02 decisions (CCK-DEC-001, items 4 and 5); no status changed
- version: "0.8"
  date: '2026-10-02'
  author: Amish Chadha
  change: "R12 status changed from within to over the value-engineering target ($177.60, $2.60 over $175) and R11 mass 4.94 kg, after the fan finger guards and silicone were added to the BOM (CCK-CAL-001 v0.6)"
---

# CellCheck requirements

These are first-pass requirements for the concept. Targets are proposals for review, not user-validated needs, and will be revised with the first trial partner. Status in Table 2 comes from the calculation note CCK-CAL-001 v0.3. No requirement is failed outright; three are at risk (R5, R6 and R11), and R10 cannot be verified at TRL 3. R14 was redefined in v0.3 under CCK-DDR-001 item 2, and R12 was restated in v0.4 for the $175 value-engineering target; both follow decisions Amish accepted on 2026-09-25 (CCK-DDR-002).

Table 1. Requirements.

| ID | Requirement | Target | Verification (TRL 3 or later) |
| --- | --- | --- | --- |
| R1 | Test the common salvaged cell sizes | 18650 and 21700 cylindrical lithium-ion cells (LCO, NMC, NCA), one cell per channel, 8 channels or more | Design review of holders and profiles |
| R2 | Measure capacity accurately | ±2 % of reading at a constant 1.0 A discharge from 4.20 V to 2.80 V | Error budget; later comparison with a calibrated reference |
| R3 | Measure cell voltage accurately | ±10 mV from 2.0 to 4.3 V, after a one-time per-channel calibration at build | Data sheet error budget; later comparison with a calibrated meter |
| R4 | Measure DC internal resistance repeatably | Resolution 1 mΩ or better; repeatability ±3 mΩ or ±5 % of reading, whichever is larger, over 5 reinsertions of one cell | Error budget; later repeat test |
| R5 | Grade enough cells | 12 cells or more per attended 10 h day on typical 1.8 Ah cells | Cycle-time calculation |
| R6 | Detect self-discharge | Open-circuit voltage change over a 14-day rest measured to ±3 mV, with both readings in the same channel; cells dropping more than 50 mV (default) beyond the median of the same-day cohort flagged | Calculation; later repeat readings |
| R7 | Monitor cell temperature | Each cell measured at least once per second to ±2 K; channel stops above 45 °C or at a rise of more than 8 K above the bench | Design review; later bench test |
| R8 | Keep the unit cool at full load | Load MOSFET cases at 75 °C or less with all channels discharging at 1 A in a 35 °C room | Thermal calculation |
| R9 | Stay safe after a single fault | No single failure (controller crash, stuck-on load MOSFET, open thermistor, failed charger) lets a cell be charged above 4.25 V, heated past 60 °C, or discharged below 2.5 V | Failure mode and effects analysis |
| R10 | Contain a single cell failure | Tray, liner and guard hold ejecta and flame from one venting 21700 cell without spread beyond the tray | Analysis at TRL 3; physical test only at TRL 4 or later |
| R11 | Fit on a bench | 500 x 320 x 120 mm or smaller, 5 kg or less without the adapter | Massing model; later weighing |
| R12 | Stay within the value-engineering target | $175 or less in parts at quantity one, excluding cells (`project.yaml`, a hypothetical control target, not a limit). Restated in v0.4 from $160 (CCK-DDR-001 item 4, decided by Amish, 2026-09-25) | Priced BOM |
| R13 | Run from a safe supply | Certified 12 V DC adapter; nothing inside the unit above 13 V; no user mains wiring | Design review |
| R14 | Limit unattended operation to safe stages | The self-discharge rest (no current flowing) can run without a person present; charge, resistance pulse and discharge run only with a person present. Redefined in v0.3 from "grading can run overnight without a person present" (CCK-DDR-001 item 2) | Design review; safety review by Amish |
| R15 | Grade and match automatically | Grades per a configurable rule table; groups for any SxP pack with each parallel group's capacity within ±1 % of the mean | Run on sample data |
| R16 | Keep a record for every cell | CSV row per cell with ID, source, measurements, grade, group and dates; export over USB or local Wi-Fi with no cloud account | Design review of the file format |
| R17 | Be buildable and open | Off-the-shelf modules, no fine-pitch assembly; hardware CERN-OHL-S-2.0, software MIT | Design review of the parts list |

Table 2. Status at TRL 3 (CCK-CAL-001 v0.3, paper estimates; at risk first, no requirement failed outright).

| ID | Status | Basis |
| --- | --- | --- |
| R5 | **At risk** | 12.0 cells per attended day under the same-day rule decided on 2026-10-02 (CCK-DEC-001, item 4; the overnight pause, 12.8, is not used); 8.0 for 2.5 Ah cells; more channels left for a later version |
| R6 | **At risk** | ±2.3 mV in the same channel (±10.6 mV across channels, no longer allowed); cohort median cancels common relaxation, but the spread between cells is not bounded |
| R11 | **At risk** | 460 x 300 x 85 mm; 4.94 kg against 5 kg (constructable design, CCK-DDR-003, with the fan finger guards and silicone of 2026-10-02). Accepted for the prototype on 2026-10-02 with the 1.5 mm tray kept; weighed at TRL 4 (CCK-DEC-001, item 5) |
| R10 | Not verifiable at TRL 3 | Containment cannot be analysed credibly on paper; mean tray rise about 84 K for an assumed 100 kJ event |
| R1 | Met (design review) | Eight holders for 18650 and 21700 cells |
| R2 | Met | ±1.1 % without calibration, ±0.4 % with |
| R3 | Met (with per-channel calibration) | ±12.4 mV without calibration; ±4.8 mV after it |
| R4 | Met | 0.83 mΩ per count; repeatability ±2.09 mΩ worst case against ±3.0 mΩ at 60 mΩ, with the pulse started only within 1 K of the bench (was ±2.99 mΩ, at risk) |
| R7 | Met (accuracy) | ±1.0 K at 45 °C, 1 Hz sampling; clip response time not verifiable at TRL 3 |
| R8 | Met | MOSFET cases 58.7 °C with fans; about 99 °C if the fans stop, so the firmware stops discharges on a fan fault |
| R9 | Met (analysis) | Watchdog, undervoltage comparators, 3 A channel fuses and a series charge switch (CCK-CAL-001 Table 3); a detached thermistor is narrowed by a plausibility check but remains a residual risk |
| R12 | **Over the value-engineering target** | $177.60 estimated in parts, $2.60 over $175 (lines 19 to 21 added for construction, CCK-DDR-003; fan finger guards on line 10 and silicone on line 16 added on 2026-10-02, CCK-DEC-001 items 9 and 2) |
| R13 | Met (design review) | Certified 12 V adapter; 12.6 V highest inside; 42.5 W of 60 W |
| R14 | Met (design review) | As redefined in v0.3 |
| R15 | Met (synthetic data) | 0.006 % group deviation for a 4S6P pack from synthetic cells |
| R16 | Met (design review) | CSV per cell; lots map to the ReflowEconomy passport v0.2 with two schema gaps |
| R17 | Met (design review) | Module-based build; open licences |

## Assumptions

- A typical salvaged 18650 holds about 1.8 Ah as found and arrives at about 30 % charge.
- A 14-day rest after a recharge that stops at 4.10 V under current separates cells with a harmful self-discharge from healthy ones; the 50 mV threshold is a starting value to be tuned with real cells.
- Operators remove cells from packs by hand before grading; disassembly is outside the scope of this design.

> **Safety:** CellCheck charges and discharges salvaged lithium-ion cells, which can overheat, vent and burn. Charge and discharge run only with a person present. Meeting these requirements on paper does not make a unit safe, and grades do not certify any cell or pack.

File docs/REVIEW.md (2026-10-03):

# Review note: CellCheck

## Session 2026-09-25: /populate to a strong TRL 2

### What was done

- `docs/01-problem.md` (CCK-PRB-001 v0.2): problem with cited reuse potential, cell spread, e-waste and fire figures; prior work (single-cell open testers, closed analyzers, lab cyclers); users and context; constraints; out of scope; open questions.
- `docs/03-requirements.md` (CCK-REQ-001 v0.2): 17 measurable requirements (R1 to R17), a status table and assumptions.
- `docs/02-concept.md` (CCK-PRC-001 v0.2): eight-step test sequence, 15 numbered components, grading rules, first-order numbers with assumptions, design choices, relation to SwapCell, CellGuard and ReflowEconomy, safety, open questions.
- `cad/src/concept_media.py`: massing model of the eight-channel grader in its steel tray, with a 48-cell rest rack and a 12 V adapter, and a bench top and salvaged laptop pack as grey context for scale.
- `media/`: `hero.png`, `concept-blueprint.png`, `.pdf` and `.svg`, `exploded.png` with callouts 1 to 15, `flow.png` (material flow per 100 salvaged cells, estimates), `model.glb` and `viewer.html`. No cutaway: the unit is open-topped, so the hero and exploded views already show every internal part.
- `bom/bom.csv`: 17 lines with indicative prices, lines 1 to 15 matching the exploded view; `bom/bom-notes.md` updated.
- `README.md`: hero image and links line; concept rationale, burning platform, industry and region tables and origin expanded with cited sources; problem, concept, key components and safety brought in line with the precis.
- `docs/pdf/`: branded PDFs of the three controlled documents.

### Key results (estimates, to be checked at TRL 3)

| Quantity | Estimate | Requirement |
| --- | --- | --- |
| Channels and cells | 8 channels, 18650 and 21700 lithium-ion | R1 met |
| Time per cell | about 6.5 h (6 to 8 h) | |
| Throughput | about 12 cells per attended 10 h day; about 28 per 24 h if run overnight | R5 met, thin margin |
| Capacity accuracy | about ±1 % calibrated, ±2 % uncalibrated | R2 met on estimate |
| Resistance resolution | about 0.8 mΩ per count, ±3 mΩ repeatability expected | R4 met on estimate |
| Heat at full discharge load | about 29 W average, 34 W peak | R8 met on estimate |
| Yield of graded cells | about 66 per 100 salvaged cells (assumption) | |
| Size and mass | 460 x 300 x 90 mm, about 3.5 kg without adapter | R11 met |
| Parts cost | about $159 against $160 | R12 met, about $1 margin |

Requirements not met or at risk:

- **R9 (single-fault safety) not met:** charger modules limit voltage on their own, but a stuck-on load MOSFET can drain a cell below 2.5 V, and temperature cutoffs rely on firmware.
- **R14 (unattended operation) not met:** the concept requires a person present while cells charge or discharge.
- **R3 at risk:** voltage accuracy before calibration is about ±10 mV from typical data sheet figures, unchecked.
- **R10 at risk:** tray, liner and guard containment of a venting cell is a concept only.
- **R13 at risk:** depends on the builder using a certified adapter.

### Proposed, awaiting Amish

Status update: items 1 to 9 are Decided by Amish, 2026-09-25: go with recommendation (CCK-DDR-002); item 10 has no recommendation and stays Proposed, awaiting Amish.

1. **SwapCell link (affects the pitch).** SwapCell's precis and BOM specify new, matched 5 Ah 21700 cells at 10 A each, which typical laptop cells cannot meet. Options: (a) keep the pitch and plan a second-life SwapCell variant (graded power tool cells, or a low-current storage pack for PowerBox), agreed with the SwapCell project; (b) reword the pitch to "rebuilt packs for lights and small storage" and drop the SwapCell example; (c) leave both unchanged. Recommendation: (a), with the variant studied at TRL 3. The README notes that SwapCell use is not yet settled; `project.yaml` pitch and problem were not changed.
2. **Unattended overnight operation (safety trade-off).** Options: never; allowed only inside a fire-rated metal cabinet with a remote smoke alarm; allowed only for the rest-rack stage (no current flowing). Recommendation: attended only for charge and discharge; rest rack may be left.
3. **Single-fault protection.** Add a hardware watchdog that removes load gate drive when the controller stops, plus a per-channel undervoltage comparator, about $5 in total, to meet R9. This would take the BOM to about $164. Recommendation: add, with a budget change to $175 (see item 4).
4. **Budget.** `budget_usd` is unchanged at $160 and the BOM is at about $159. Options: (a) raise to $175 for the watchdog and margin; (b) keep $160 and add the watchdog by dropping the display (web page only). Recommendation: (a).
5. **Grading thresholds** (Table 2 of the precis), the 14-day rest at 4.10 V with a 50 mV limit, and the ±1 % group tolerance. Recommendation: adopt as starting values and tune with the first 100 real cells.
6. **Module choices:** TP5100-class charger, INA226-class monitor with a 25 mΩ shunt, ESP32-S3 class controller. Recommendation: as listed.
7. **Eight channels with a linear load** rather than 16 channels or regenerative discharge. Recommendation: eight, linear.
8. **LFP profile** in the first release or later. Recommendation: later, after the lithium-ion profile is proven.
9. **Record format:** map the CSV to ReflowEconomy's material passport at TRL 3. Recommendation: yes.
10. **First trial partner:** a repair café, an e-bike repair shop or a battery collection point.

### Safety concerns

- Salvaged cells can hide internal damage; charging them can lead to venting and fire. The documents require rejection of damaged and deeply discharged cells, per-cell temperature cutoffs, a steel tray and guard, and attended operation.
- Pack disassembly (cutting nickel strip) can short cells; covered as a safety note, not designed here.
- No independent second layer against load faults yet (R9).
- Heatsink surfaces up to about 70 °C.
- Grades must not be presented as a safety certification of any cell or pack.

### Recommended next step

Review this note and the media, and decide items 1 to 4. If approved, run `/advance-trl3` to check the thermal budget, measurement error budgets and cycle time by calculation, write the failure mode analysis for R9, and produce the parametric model and drawing sheet.

## Session 2026-09-25: TRL 3

Amish asked for this batch to be taken through the usual process with the instruction "you know the drill, nothing gets past TRL 3". He has not reviewed the CellCheck TRL 2 items one by one, so each item with a recommendation is adopted as recommended for TRL 3 under Amish's 2026-09-25 instruction, open for his review. TRL 4 is on hold by Amish's instruction.

### What was done

- `docs/decisions/0001-trl2-review-decisions.md` (CCK-DDR-001 v0.1, status proposed): items 1 to 3 and 5 to 9 adopted for TRL 3 pending Amish's review; items 4 and 10 to 16 stay open.
- `docs/04-calcs/01-sizing.md` (CCK-CAL-001 v0.1) with `docs/04-calcs/sizing.py` and `results.csv`: cycle time and a day-by-day throughput simulation, power and energy, heatsink and MOSFET temperatures, error budgets for capacity, voltage, resistance, self-discharge and temperature, the R9 failure mode analysis, a containment estimate, size and mass, grading and matching on synthetic cells, a second-life SwapCell study, cost, and the mapping to ReflowEconomy's material passport.
- `cad/src/model.py`: parametric build123d model (tray with intake slots, base plate, eight four-wire holders, guard, module rows, heatsink with 40 vertical fins, fan shroud, controller, watchdog board, display, inlet, adapter, rest rack). Exports `cad/step/` and `cad/stl/` for the assembly, tray, heatsink, holders and rest rack; prints volumes and a clash check (no clashes).
- `cad/src/sheets.py` and `cad/drawings/CCK-DWG-001.svg`, `.pdf` and `.png`: general arrangement at Rev P1, "PRELIMINARY, NOT FOR FABRICATION". The concept sheet keeps CCK-DWG-010, so DWG-001 was the first free number.
- `bom/bom.csv`: 18 lines, all priced with supplier types; new line 18 (watchdog and undervoltage board, $5.00). `bom/bom-notes.md` updated.
- `cad/src/concept_media.py` now builds from `model.py`; `media/` refreshed (hero, blueprint, exploded with callout 18, flow, GLB and viewer). No cutaway, as at TRL 2: the unit is open-topped, so the kit's cutaway is not used. The flow diagram losses now sit under the stage that removes them. Temporary `media/_views*` folders deleted.
- Docs bumped to v0.3 with revision rows: CCK-PRB-001, CCK-PRC-001 (numbers from CAL-001, adopted choices, heatsink orientation, component 18), CCK-REQ-001 (R14 redefined, R3 calibration, R12 against both budgets, status table from CAL-001).
- `README.md`: TRL 3 badge, links to the drawing and CAL-001, numbers from CAL-001, SwapCell wording aligned with DDR item 1; the required sections are unchanged in order.
- `project.yaml`: `trl: 3`, `trl_target: 3`, evidence list. Pitch, problem and `budget_usd` unchanged.

### Requirements (CCK-CAL-001)

Met on paper: 11 of 17. Not met and at risk first:

| ID | Status | Value |
| --- | --- | --- |
| R12 | **Not met** | $164.00 against $160; $11.00 under the recommended $175 |
| R4 | At risk | ±2.99 mΩ worst case against ±3.0 mΩ; cell temperature dominates |
| R5 | At risk | 12.0 cells per attended day on the stage-boundary rule; 12.8 with an overnight pause; 8.0 for 2.5 Ah cells |
| R6 | At risk | ±10.6 mV across channels, ±2.3 mV in the same channel; relaxation after charge not bounded |
| R11 | At risk | 4.97 kg against 5 kg; 460 x 300 x 75 mm |
| R10 | Not verifiable at TRL 3 | Containment of a venting cell cannot be analysed credibly on paper |
| R1, R2, R3, R7, R8, R9, R13 to R17 | Met (R3 with per-channel calibration; R9 on analysis; R15 on synthetic data) | See CCK-CAL-001 Table 4 |

Key numbers: 6.33 h per 1.8 Ah cell; 42.5 W adapter load; 16.8 Wh per cell from the mains; 33.6 W peak heat, 0.58 K/W heatsink, MOSFET cases 58.7 °C (about 99 °C if both fans stop); capacity ±1.1 % uncalibrated; voltage ±12.4 mV uncalibrated and ±4.8 mV calibrated.

Corrections to TRL 2 figures: time per cell 6.5 to 6.33 h; voltage error ±10 to ±12.4 mV before calibration; capacity error ±2 to ±1.1 %; height 90 to 75 mm; mass 3.5 to 4.97 kg (the tray alone is 2.43 kg); cost $159 to $164. The TRL 2 massing model had heatsink fins across the fan airflow; they are now in line with it.

### Decisions recorded (CCK-DDR-001)

Status update: all of these are now Decided by Amish, 2026-09-25: go with recommendation (CCK-DDR-002). Originally adopted as recommended for TRL 3 under Amish's 2026-09-25 instruction, open for his review: (1) keep the pitch and plan a second-life SwapCell variant, studied in CAL-001 section 10 (low-current PowerBox storage pack, about 334 Wh and 165 W; e-bike use ruled out); (2) charge and discharge attended only, rest stage may be left, so R14 is redefined; (3) hardware watchdog and per-channel undervoltage comparators; (5) grading thresholds, 14-day rest with 50 mV limit and ±1 % group tolerance as starting values; (6) TP5100, INA226 and ESP32-S3 class modules; (7) eight channels with a linear load; (8) LFP profile later; (9) record mapped to ReflowEconomy's passport v0.2. No pitch or problem rewording was recommended, so both are unchanged.

### Items still awaiting Amish

- Budget: $175 recommended (item 4). Now Decided by Amish, 2026-09-25: go with recommendation; `budget_usd` is $175.
- First trial partner: repair café, e-bike repair shop or collection point; no preference stated (item 10).
- DC four-wire resistance and the 14-day rest (in the precis, not separate TRL 2 review items) (item 11). Now Decided by Amish, 2026-09-25: go with recommendation.
- Scheduling rule for the attended day: finish current stages the same day, or pause overnight with the unit off (item 12).
- Engineering proposals from CAL-001: same-channel and same-day cohort self-discharge reading, temperature-gated resistance pulse, per-channel calibration, fan-fault stop, detached-thermistor plausibility check (item 13). Now Decided by Amish, 2026-09-25: go with recommendation.
- Responses to R12, R11 (a 1.2 mm tray saves 0.49 kg but thins the containment) and R5 (item 14). R12 is resolved by item 4; R11 and R5 stay open.
- Grade A resistance limits per cell model need named data sheets (item 16).

### Cross-repo notes (not edited in the other repos)

- **ReflowEconomy:** the material passport v0.2 has no `product_form` for graded cells and no electrical test in `identification.method`. Raised here for the ReflowEconomy project (item 15).
- **SwapCell and PowerBox:** a second-life pack would limit discharge to about 3.5 A and charge to 0.5C, below PowerBox's 5.0 A charge and 300 W inverter; PowerBox would need a lower host charge limit and AC limit for that pack. Needs the SwapCell project's agreement.
- **CellGuard:** consistent. CellCheck assumes CellGuard's NMC-capable hardware with LFP firmware first, as adopted in CGD-DDR-001 item 7. No other shared component (FieldNode, MotionCore, ThermaCart, TwinKit, CalRig) is used.

### Safety concerns

- Salvaged cells can hide damage; charge and discharge now require a person present. The failure mode analysis covers the R9 faults on paper, but a detached thermistor clip goes undetected.
- If both fans stop, the MOSFET cases could approach 99 °C; the firmware must stop discharges on a fan or heatsink fault.
- Containment is unverified, and the new fan intake slots are an opening in the tray wall. The 100 kJ runaway figure in CAL-001 section 7 is an assumption with no source yet and must be replaced by a cited value.
- Grades must not be presented as a safety certification of any cell or pack.

### Citations and other checks

- No unchecked citations were listed in this note, so no WebFetch was needed. The INA226-class and ESP32-class figures in CAL-001 are typical data sheet values used as assumptions, not verified against a data sheet in this session.
- No TRL 4 material exists in the repo (`build-log/` holds only its README and `.gitkeep`; `firmware/` and `electronics/` are empty).

### Recommended next step

Amish to review CCK-DDR-001, decide the budget (item 4) and the trial partner (item 10), and confirm or change the adopted items and engineering proposals. TRL 4 is on hold by Amish's instruction. For reference only, TRL 4 would need: a built unit; bench test reports (TST, `environment: lab`) for capacity, voltage, resistance repeatability and self-discharge against a calibrated reference; a fault-injection test of the watchdog, comparators and fuses; a fan-failure thermal test; a containment test with a sourced cell failure method in a suitable facility; and dated build-log entries.

## Session 2026-09-25: recommendations accepted

On 2026-09-25 Amish wrote: "i accept all your recommendations, go with them across all repos." Every item above with a recommendation is now **Decided by Amish, 2026-09-25: go with recommendation**; where several options were offered, the recommended option is the decision. Items without a recommendation stay Proposed, awaiting Amish. The record is `docs/decisions/0002-recommendations-accepted.md` (CCK-DDR-002 v0.1); CCK-DDR-001 is updated to v0.2.

### Decisions applied and what changed

| DDR-001 item | Decision | Change (before to after) |
| --- | --- | --- |
| 4 | Budget raised (option a) | `budget_usd` $160 to $175; R12 target $160 to $175; R12 Not met ($4.00 over) to Met ($11.00 under) |
| 13 | Firmware and build rules from CCK-CAL-001 | Resistance pulse starts only within 1 K of the bench: R4 worst case ±2.99 to ±2.09 mΩ (RSS ±2.02 to ±1.28 mΩ), At risk to Met. Self-discharge read in the same channel against the same-day cohort median: R6 reading ±10.6 to ±2.3 mV, still at risk (relaxation spread not bounded). Fan-fault stop, per-channel calibration and a detached-thermistor plausibility check written into the precis |
| 11 | DC four-wire resistance and 14-day rest | Proposed to decided; no numbers change |
| 1 | Keep SwapCell in the pitch; plan a second-life variant (option a) | Wording only; pitch and problem unchanged; cross-repo action below |
| 2, 3, 5, 6, 7, 8, 9 | Attended charge and discharge; watchdog and comparators; grading thresholds; modules; eight linear channels; LFP later; passport mapping | Wording only; already implemented at TRL 3 |
| 15 | Raise passport gaps with ReflowEconomy | Listed under cross-repo actions |

Documents bumped with a revision row "Recommendations accepted by Amish (DDR-002)": CCK-PRB-001 v0.4, CCK-PRC-001 v0.4, CCK-REQ-001 v0.4, CCK-CAL-001 v0.2 (with `sizing.py` and `results.csv`), CCK-DDR-001 v0.2. `project.yaml` (budget, evidence list), `README.md` and `bom/bom-notes.md` updated. No part was added or resized, so `model.py`, STEP, STL and CCK-DWG-001 (Rev P1) are unchanged in geometry and notes; they, the concept media and all PDFs were regenerated. The README "What sparked the idea" section now traces the idea to IBM Research India's 2014 UrJar project.

### Requirement status (CCK-CAL-001 v0.2)

Met on paper: 13 of 17 (was 11). None is failed outright.

| ID | Status | Value |
| --- | --- | --- |
| R5 | At risk | 12.0 cells per attended day (stage-boundary rule); 12.8 with an overnight pause; 8.0 for 2.5 Ah cells |
| R6 | At risk | ±2.3 mV in the same channel against ±3 mV; spread of relaxation between cells not bounded |
| R11 | At risk | 4.97 kg against 5 kg; 460 x 300 x 75 mm |
| R10 | Not verifiable at TRL 3 | Containment of a venting cell cannot be analysed credibly on paper |
| R4 | Met | ±2.09 mΩ worst case against ±3.0 mΩ (was at risk) |
| R12 | Met | $164.00 against $175 (was not met against $160) |
| R1, R2, R3, R7, R8, R9, R13 to R17 | Met | Unchanged; see CCK-CAL-001 Table 4 |

### Items still awaiting Amish (no recommendation was made)

- First trial partner: repair café, e-bike repair shop or collection point (item 10).
- Scheduling rule for the attended day (item 12).
- Responses to R11 and R5 (item 14).
- Grade A resistance limit per cell model; needs named data sheets (item 16).

### Cross-repo actions (no other repo edited)

- **SwapCell and PowerBox:** agree the second-life low-current storage pack (about 334 Wh, 3.5 A discharge, 0.5C charge); PowerBox would need a lower host charge limit and an AC limit of about 150 W for that pack (item 1).
- **ReflowEconomy:** add a `product_form` for graded cells and an electrical test in `identification.method` to the material passport schema (item 15).
- **CellGuard:** none; consistent with CGD-DDR-001 item 7.

### Decided but on hold (TRL 4)

Tuning the grading thresholds on the first 100 real cells (item 5), buying modules (item 6), writing and testing the firmware rules and doing the per-channel calibration (item 13), and every test listed in the previous session. TRL 4 remains on hold by Amish's instruction; `trl` and `trl_target` stay at 3.

### Safety concerns

Unchanged from the TRL 3 session. The detached-thermistor plausibility check narrows but does not remove that residual risk, and the 100 kJ runaway figure in CCK-CAL-001 section 7 still needs a sourced value before any TRL 4 work.

## Session 2026-09-26: product appearance model and photoreal renders

Amish chose this repo for the first batch of product renders on 2026-09-26. This session added an appearance model for photoreal product shots; it changes no design parameter.

### What was done

- `cad/src/product_model.py` (new): `product_parts()` returns 91 coloured, material-tagged parts (shell 16, internal 46, accessory 14, context 15) with BOM numbers and explode offsets, plus `TITLE` and `RENDER_VIEWS` (hero, exploded, detail). All dimensions come from `PARAMS`, `channel_x()` and `heatsink_extent()` in `cad/src/model.py`, which is unchanged.
- `README.md`: the hero image now points to `media/render-hero.png`, and the links line starts with the exploded render. Both files are produced later by the render pipeline.

What the appearance model adds:

- Steel tray with rounded corners, a rolled rim, rounded intake slots, a teal nameplate and a lithium warning label; ceramic fibre liner shown separately.
- Aluminium base plate with hex standoffs, fixing screws and printed channel numbers 1 to 8.
- Filleted cell holders with two nickel contacts at each end (force and sense) and solder tabs; 18650 cells with ID labels and insulator rings in six of the eight bays; saddle-shaped thermistor clips, with the two spare clips parked on the empty holders.
- Slotted perforated guard with foot flanges and screws.
- Populated charger modules, sense boards with lit status LEDs, TO-220 MOSFETs with clamp screws, the finned heatsink, fan shroud and two fans with blades, hubs and finger guards.
- Controller board, watchdog perfboard with DIP packages, a charcoal display stand with dark glass, lit channel rows and three buttons, and a power inlet with rocker switch, fuse holder, DC jack and power LED.
- Accessories: the rest rack with column numbers and resting cells, and the 12 V adapter with its rating label and cable to the inlet.
- Context: a silicone bench mat and three bins labelled A, B and C holding matched cells.

### Differences from model.py (Proposed, awaiting Amish)

- **18650 cells in the bays.** `model.py` draws 21700 cells (the largest accepted) in all eight bays; the render shows 18650 cells, the common salvaged size, in six bays with two bays empty so the contacts are visible. The thermistor clips sit lower to match. Recommendation: accept for the renders; the model keeps the 21700 envelope for clearance checks.
- **Matched group bins A, B and C.** These are not in `bom/bom.csv`. They show where graded cells go after matching. Options: (a) keep them as render context only, (b) add a BOM line for three printed or bought bins, costed against the $175 budget. Recommendation: (a) for now, and decide (b) with the rest of the TRL 4 purchasing.
- **Fan finger guards.** Not in the BOM; they sit 1 mm behind the fans and change no clearance. Recommendation: add them to BOM line 10 at TRL 4 and cost them then.
- **Perforation pattern.** The guard is drawn with slots at about 50 % open area instead of round holes, and the sheet is shown 1.0 mm thick instead of 0.8 mm. Recommendation: accept as an appearance choice; the BOM specification stays as written.
- **Channel status LEDs, labels and screws** are appearance details placed on existing BOM items (lines 2, 5, 7, 8 and 17).

### Status

This is an appearance model only: no tolerances, PCB layouts or fabrication detail. `trl` and `trl_target` stay at 3, and TRL 4 remains on hold.

## Session 2026-09-27: kit 1.5.0 and image quality

- Kit 1.5.0 synced: STANDARDS v1.5 (sections 12 to 15: product renders, storefront images and image quality, public release, authorship and signing), `.kit/cards.py`, `.kit/image_qc.py`, `.kit/release_gate.py`, issue templates, and the `/render-product` and `/release` commands. `CLAUDE.md` now matches `.kit/CLAUDE.md`.
- Every `media/render-*.png` recaptioned from its original render with the new layout: the title, concept label and repository sit in a band above the render and the view note in a band below it, each line wrapped to the image width, so no text overlaps other text or the render or runs off the image. `media/card.png` and `media/social-preview.png` regenerated with the same rules.
- `python .kit/image_qc.py` and `python .kit/release_gate.py` pass. trl stays 3.

## Session 2026-10-01: design made constructable and prototype build plan (kit 1.7.0)

Amish approved the build plan format on 2026-09-30 and asked for it across all repos, with outstanding decisions kept out of the build plan in a separate design decisions register. Kit 1.7.0 is installed (`.kit/`, `.claude/commands/`, root `CLAUDE.md`).

### What was done

- Constructability review with build123d of every part: what touches what, what holds it, and whether it can be made as described. `cad/src/model.py` now builds every component with its fixings and runs 129 constructability checks (`python cad/src/model.py --check`); all pass.
- `docs/decisions/0003-design-for-construction.md` (CCK-DDR-003 v0.1, Draft): every change, with the reason, made under Amish's 2026-09-30 instruction to make the design physically buildable; open for his review.
- `docs/05-build-plan.md` (CCK-BLD-001 v0.1): the illustrated build plan, with no open decisions in it.
- `docs/06-design-decisions.md` (CCK-DEC-001 v0.1): 11 open decisions, 10 items to confirm when parts are bought, and the decisions made.
- `cad/src/build_plan_media.py`: overview, 10 making sketches (`cad/drawings/CCK-DWG-101` to `110`), a plate hole layout, 7 joint close-ups, 11 step pictures and the block wiring diagram (the picture for step 9), all in `docs/05-build-plan/`.
- `bom/bom.csv`: lines 19 (rubber feet), 20 (fixings) and 21 (5 V converter) added; lines 1 to 5, 7 to 10, 12, 13 and 16 respecified. $172.40 estimated, $2.60 under the $175 value-engineering target.
- Recalculated: CCK-CAL-001 v0.3 (size, mass, cost), with `sizing.py` and `results.csv`; CCK-PRC-001 v0.5 and CCK-REQ-001 v0.5 updated to match.
- Regenerated: STEP and STL, the general arrangement CCK-DWG-001 at Rev P2, and the concept media (`hero.png`, `exploded.png`, `flow.png`, `concept-blueprint`, `model.glb`, `viewer.html`).
- `project.yaml`: `design_state: constructable`; the build plan, register and CCK-DDR-003 added to `trl_evidence`. `README.md`: links line and a "Building the prototype" section with the overview picture.

### Design changes made for construction (CCK-DDR-003)

1. Six rubber feet with M4 studs through the tray floor into six 12 mm hex standoffs on the bare steel; the plate screws onto them (the concept's four standoffs rested loose on the liner).
2. Base plate 1.5 mm on six standoffs instead of 2 mm on four; every screw reachable from above (two concept screws sat under the display and the inlet).
3. Two M3 screws per cell holder; two 16 x 5 mm wire slots per channel through the plate, leads run underneath.
4. Guard folded from one perforated steel blank with end flanges, held by two M4 thumb screws into rivet nuts in the plate; lifts off to change cells.
5. Every board on two 5 mm nylon standoffs; controller and watchdog board moved 10 mm right to clear the thumb screw.
6. Display stand enlarged to 88 x 62 mm to take a 2.8 in display module (the concept's 60 mm stand was too small); buttons in its foot.
7. Heatsink screwed to the plate from below; each MOSFET clamped with an insulated M3 screw.
8. Fan shroud folded with side flanges screwed to the spine ends; fans screwed from inside; the unfoldable top lip dropped.
9. Thermistor clip made a printed C-clip, in 21700 and 18650 sizes.
10. Inlet housing printed open-bottomed with the jack, fuse holder and switch on top (the concept's jack faced the tray wall 23 mm away).
11. Added the 5 V converter; the channel board now carries the charge switch, the load loop's op-amp and the 3 A fuse clips.
12. Cells rest in their holder grooves and touch both contacts.

### Key results

- Size 460 x 300 x 85 mm (was 75 mm high); mass 4.91 kg (was 4.97 kg); parts $172.40 (was $164.00).
- No requirement changed status: none not met; R5, R6 and R11 at risk (R11 margin now 0.09 kg); R10 not verifiable at TRL 3; 13 met on paper.

### Proposed, awaiting Amish

- Guard hold-down (thumb screws as modelled, toggle latches or a hinge); it is part of the containment arrangement (CCK-DDR-003 A1). Recommendation: thumb screws for the prototype.
- Seal the wire slots under the guard with high-temperature silicone after wiring (CCK-DDR-003 A2). Recommendation: seal.
- The earlier open items stay open and are listed in CCK-DEC-001.

### Stale media (made on Amish's Mac; not regenerated here)

The design changed visibly (feet, guard, display stand, inlet, shroud), so `cad/src/product_model.py`, `media/render-hero.png`, `media/render-exploded.png`, `media/render-detail.png`, `media/card.png` and `media/social-preview.png` are stale and should be regenerated on the Mac.

### Safety concerns

Unchanged in substance. The guard now lifts off by hand, which is what a cell change needs but makes its hold-down part of the containment question (A1). The wire slots open the guard space to the underside of the plate inside the tray (A2). The build plan sets safety stops S1 to S7 before cells, power, first charge, first discharge and any unattended period.

### Recommended next step

Amish to review CCK-DDR-003 and decide A1 and A2 in the register. TRL 4 (building to this plan) remains on hold by Amish's instruction.

## Session 2026-10-02: open decisions decided

On 2026-10-02 Amish approved every recommendation written for the open decisions: "i approve your recommendations for all 555 open decisions." trl stays 3; nothing was built or tested.

### Decisions recorded

11 decisions recorded in the design decisions register (CCK-DEC-001 v0.3, Decisions made, dated 2026-10-02): guard hold-down (1), wire slot sealing (2), first trial partner (3), scheduling rule (4), responses to R11 and R5 (5), grade A limit per cell model (6), 18650 cells in the renders (7), bins as render context (8), fan finger guards in BOM line 10 (9), guard perforation as appearance (10) and the second-life pack study sent to SwapCell and PowerBox (11). The partner in item 3 is the first candidate to approach, not an agreed partner.

### Documents changed

- `docs/06-design-decisions.md` (CCK-DEC-001 v0.3): all 11 open items moved to Decisions made; Open decisions now reads "None"; the value-engineering savings line updated for items 8 and 9.
- `docs/decisions/0003-design-for-construction.md` (CCK-DDR-003 v0.3): status line and Table 3 record A1 and A2 as accepted; consequence added; status stays Draft; Tables 1 and 2 still open for Amish's review at that point (see Points found in the review).
- `docs/decisions/0001-trl2-review-decisions.md` (CCK-DDR-001 v0.3): items 10, 12, 14 and 16 recorded as decided.
- `docs/decisions/0002-recommendations-accepted.md` (CCK-DDR-002 v0.2): the same four items recorded as decided in Table 3.
- `docs/01-problem.md` (CCK-PRB-001 v0.6): first trial partner named as the first candidate to approach.
- `docs/02-concept.md` (CCK-PRC-001 v0.7): throughput rule, grade A limit, containment hold-down and slot sealing, fan finger guards, pack study; open questions closed.
- `docs/03-requirements.md` (CCK-REQ-001 v0.7): R5 and R11 status notes; no status changed.
- `docs/04-calcs/01-sizing.md` (CCK-CAL-001 v0.5): R5 row of Table 4 names the decided rule, and section 8 the tray decision; no number changed.
- `docs/05-build-plan.md` (CCK-BLD-001 v0.2): step 9 seals the wire slots with high-temperature silicone; silicone and fan finger guards in the bought components.
- `bom/bom-notes.md`: the decided part and material choices noted; the line 10 and 16 changes are follow-ups.
- `README.md`: the register sentence and the SwapCell paragraph.
- PDFs re-rendered with `python .kit/render.py`; superseded versions removed.

No CAD model, BOM quantity or price, or picture was changed. Requirement status is unchanged: R5, R6 and R11 at risk, R10 not verifiable at TRL 3, 13 met on paper.

### Follow-up actions to carry approved decisions into the design

1. Decision 2 (bom): Add high-temperature silicone sealant to the specification of BOM line 16 (price unchanged or re-estimated).
2. Decision 2 (pictures): Show the sealed wire slots in the step 9 picture and the plate figures of the build plan (`cad/src/build_plan_media.py`).
3. Decision 9 (bom): Add two 60 mm fan finger guards to BOM line 10 with an estimated price.
4. Decision 9 (calcs): Update the cost in CCK-CAL-001 section 11 (`sizing.py`, `results.csv`), R12 in CCK-REQ-001 and the value-engineering figure in CCK-DEC-001, README and `bom/bom-notes.md` once lines 10 and 16 are repriced.
5. Decision 9 (model): Add the finger guards to the fans in `cad/src/model.py` and the exploded view so the model matches BOM line 10.
6. Decision 11 (docs): Send the second-life pack study (CCK-CAL-001 section 10) to the SwapCell and PowerBox repositories as a proposal.
7. Decision 7 (pictures): Regenerate the appearance model and photoreal renders on Amish's Mac to the constructable design (guard, display stand, inlet, feet), keeping 18650 cells and the slotted guard as accepted appearance.

### Points found in the review

- The register had no open row asking Amish to accept CCK-DDR-003 (P1 to P12), although the decisions-made table said it was open for his review; the recommendation was "accept". Amish accepted it later on 2026-10-02 (see the next session).
- Items 4 and 5 overlap: the throughput half of item 5 is the scheduling rule of item 4.
- The 60 mΩ grade A default should not be replaced with data sheet impedance figures, which are normally 1 kHz AC values and not comparable with the DC pulse measurement.
- The appearance model and renders still show the concept guard, display, inlet and no feet.

### Safety

The guard's two thumb screws and the silicone-sealed wire slots are now part of the containment arrangement, which is still not verifiable on paper. The TRL 4 containment test must be run with the guard held by the thumb screws exactly as in the build plan. The fan finger guards are decided but not yet in the BOM.

### Recommended next step

Carry out the follow-up actions above (Amish accepted CCK-DDR-003 Tables 1 and 2 later on 2026-10-02; see the next session). TRL 4 remains on hold by Amish's instruction.

## Session 2026-10-02: design-for-construction changes accepted

Amish, 2026-10-02: "APPROVED: Design-for-construction changes in 10 repos (CityTwin, CoolShade, PalletPilot, Heliolite, PotholeLog, EarthPress, ReadyKit, CellCheck, CargoMule and ThermaCart)". This accepts the design-for-construction changes P1 to P12 in Table 1 of CCK-DDR-003, with their knock-on changes in Table 2, which were left open for his review when the open decisions were decided earlier the same day. No other item is decided by it. trl stays 3; no build or test work was done, and the model, BOM, calculations and pictures are unchanged.

### Documents changed

- `docs/decisions/0003-design-for-construction.md` (CCK-DDR-003 v0.4, status Draft): status line now "accepted" with Amish's words.
- `docs/06-design-decisions.md` (CCK-DEC-001 v0.4): Decisions made row added, dated 2026-10-02; the 2026-10-01 row no longer calls the changes open for review.
- `docs/05-build-plan.md` (CCK-BLD-001 v0.3): section 2 says CCK-DDR-003 is accepted.
- PDFs regenerated.

### Recommended next step

No change: the follow-up actions of the previous session stand. TRL 4 remains on hold by Amish's instruction.

## Session 2026-10-02: approved follow-ups carried out

Amish approved on 2026-10-02 that every follow-up action from the open-decision sign-off be carried out. trl stays 3; nothing was built or tested.

### Follow-ups

1. Decision 2, BOM: done. High-temperature silicone sealant added to line 16 ($8.00 to $12.00; a 30 g tube, estimated at $4.00 for a small tube rated to about 260 C).
2. Decision 2, pictures: done. New step 9 picture (`docs/05-build-plan/step-09.png`) showing the 16 sealed slots; plate hole figure shades the slots as sealed; joint 6 shows a seal; the seals are in the model (16 plugs, BOM 16).
3. Decision 9, BOM: done. Line 10 now "Fan with shroud and finger guard", $2.60 each for two (guard $0.60, a typical marketplace price for a 60 mm wire grill); line 20 counts eight small screws for the guards at no price change.
4. Decision 9, calculations: done. `sizing.py` and `results.csv` rerun; CCK-CAL-001 sections 8 and 11, CCK-REQ-001, CCK-PRC-001, CCK-DEC-001, README and BOM notes brought into line. Mass 4.94 kg (4.91 kg before); cost $177.60.
5. Decision 9, model: done. Finger guards (and their screws) and silicone seals added to `cad/src/model.py`, the exploded view and the build plan pictures; 139 constructability checks pass (129 before); STEP and STL regenerated.
6. Decision 11, send the second-life pack study to SwapCell and PowerBox: not done here, it lives in other repos (see Cross-repo actions).
7. Decision 7, appearance and renders: appearance model updated and render scenes exported (hero, exploded, detail); photoreal renders, `media/card.png` and `media/social-preview.png` are made on Amish's Mac.

### Requirement status changes

- R12: from "within the value-engineering target" to "over the value-engineering target". Value-engineering target: USD 175.00. Estimated cost of the constructable design: USD 177.60 (USD 2.60 over the target). `budget_usd` is unchanged.
- R11: still at risk; 4.94 kg against 5 kg (0.06 kg of margin, was 0.09 kg).
- On paper 12 of 17 are met (was 13); none is failed outright.

### Proposed, awaiting Amish

- The $2.60 overshoot of the value-engineering target: accept it as a control target, not a limit (recommended for the paper design), look for $2.60 of savings, or raise the target. Recorded as open decision 1 in CCK-DEC-001.
- Appearance deviations in the appearance model: guard drawn slotted and 1.0 mm (accepted 2026-10-02), 18650 cells shown, rubber feet drawn as plain cylinders.

### Pictures regenerated

General arrangement CCK-DWG-001 Rev P3; making sketches CCK-DWG-101 to 110 (101 to 110 re-issued, notes added to 103 and 105); concept media (`media/hero.png`, exploded, flow, blueprint, viewer); build plan overview, plate hole figure, joints 1 to 7 (joint 4 redrawn from behind to show the guard), steps 1 to 12 (new step 9), wiring.

### Appearance model and render scenes

`cad/src/product_model.py` now has six feet and six standoffs, plate slots with silicone seals, the end-flanged guard with two thumb screws, boards lifted 5 mm, finger guards, and the unit lifted onto its feet, all dimensions from `cad/src/model.py`. Scenes exported to `/home/claude/renders/cellcheck`: hero, exploded and detail (one .npz and .json each, plus `cellcheck__jobs.json`).

### Cross-repo actions

- SwapCell and PowerBox: send the second-life pack study (CCK-CAL-001 section 10: 13S4P of grade A laptop cells, about 334 Wh, 165 W, low-current storage variant) as a proposal.

### Documents changed

CCK-CAL-001 v0.6, CCK-REQ-001 v0.8, CCK-PRC-001 v0.8, CCK-DEC-001 v0.5, CCK-DDR-003 v0.5, CCK-BLD-001 v0.4, CCK-DWG-001 Rev P3, `bom/bom.csv`, `bom/bom-notes.md`, README. PDFs re-rendered.

### Recommended next step

Decide the cost overshoot, render the photoreal images on the Mac, then ask Amish before any TRL 4 work.

## 2026-10-02: photoreal renders redone on the constructable design

Rendered with Blender Cycles on Amish's Mac from the updated appearance model; captioned with `.kit/photo_caption.py`; `media/card.png` and `media/social-preview.png` regenerated with `.kit/cards.py`. Views: hero, exploded, detail. image_qc passes. Appearance deviations are those logged above as proposed, awaiting Amish.

## 2026-10-03: decisions recorded

Amish decided on 2026-10-03: "Cost over target - i accept all the cost variations and overruns". Recorded for this repo: the estimated cost of USD 177.60 against the USD 175 target (USD 2.60 over; open decision 1, option a).

- `docs/06-design-decisions.md`: row added to decisions made; value engineering section says the overrun was accepted by Amish on 2026-10-03.

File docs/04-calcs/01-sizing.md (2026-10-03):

---
doc_id: CCK-CAL-001
title: CellCheck sizing calculations
project: CellCheck
doc_type: Calculation note
version: "0.6"
status: Draft
date: '2026-10-02'
author: Amish Chadha
license: CERN-OHL-S-2.0
revisions:
- version: "0.1"
  date: '2026-09-25'
  author: Amish Chadha
  change: First TRL 3 sizing note (cycle time and throughput, power, heatsink, measurement error budgets, single-fault analysis, containment, mass, grading on synthetic data, second-life SwapCell study, cost)
- version: "0.2"
  date: '2026-09-25'
  author: Amish Chadha
  change: Recommendations accepted by Amish (DDR-002). Budget $175 (R12 met); temperature-gated resistance pulse (R4 met); same-channel, cohort-median self-discharge reading (R6)
- version: "0.3"
  date: '2026-10-01'
  author: Amish Chadha
  change: Design made constructable (CCK-DDR-003). Size and mass (section 8) and cost (section 11) rerun for the 1.5 mm base plate on six standoffs, rubber feet, folded guard and shroud, fixings and the 5 V converter
- version: "0.4"
  date: '2026-10-01'
  author: Amish Chadha
  change: Budget treated as a value-engineering target; cost wording only, no number changed
- version: "0.5"
  date: '2026-10-02'
  author: Amish Chadha
  change: R5 row of Table 4 names the same-day scheduling rule and section 8 the tray decision of 2026-10-02 (CCK-DEC-001, items 4 and 5); no number changed
- version: "0.6"
  date: '2026-10-02'
  author: Amish Chadha
  change: "Fan finger guards (line 10) and silicone sealant (line 16) added to the mass and cost: 4.94 kg (R11 still at risk) and $177.60, $2.60 over the value-engineering target (R12 status changed from within to over); sizing.py and results.csv rerun; CCK-DEC-001 items 9 and 2"
---

# CellCheck sizing calculations

On paper, CellCheck meets 12 of its 17 requirements, is over its value-engineering target on one (R12, by $2.60) and fails none outright. Version 0.2 applies the decisions Amish accepted on 2026-09-25 (CCK-DDR-002): the value-engineering target in `project.yaml` is now $175 (a hypothetical control target, not a limit), so the estimated parts cost is within the target for **R12** (it was $4 over the former $160 target), and the resistance pulse now starts only within 1 K of the bench reading, so **R4** is met at ±2.09 mΩ against ±3.0 mΩ (it was ±2.99 mΩ, at risk). Three requirements remain **at risk**: R5 (throughput is exactly 12 cells per attended day), R6 (self-discharge reading) and R11 (mass is 4.91 kg against 5 kg). R10 (containment) cannot be verified at TRL 3. The TRL 2 figures change in several places: time per cell falls from about 6.5 to 6.33 h, capacity error without calibration is ±1.1 % rather than ±2 %, voltage error without calibration is ±12.4 mV rather than ±10 mV, and the unit is 85 mm high and 4.91 kg rather than 90 mm and 3.5 kg. The heatsink fins in the TRL 2 massing model ran across the fan airflow; they are now vertical plates in line with it. Version 0.3 reruns size, mass and cost for the constructable design of CCK-DDR-003 (feet, a thinner base plate on six standoffs, fixings and a 5 V converter): 85 mm high, 4.91 kg and $172.40, so R11 stays at risk and R12 stays met with $2.60 of margin. Version 0.6 adds the fan finger guards and the silicone for the wire slots that Amish decided on 2026-10-02 (CCK-DEC-001, items 9 and 2): 4.94 kg and $177.60, so R11 stays at risk with 0.06 kg of margin and R12 is now $2.60 over the $175 value-engineering target. No other result changes.

Every number here is printed by `docs/04-calcs/sizing.py` (run from the repo root: `python docs/04-calcs/sizing.py`), which also writes `docs/04-calcs/results.csv`. The script reads the geometry from `cad/src/model.py` and the costs from `bom/bom.csv`. All values are first-principles estimates; nothing is measured.

## 1. Assumptions

*Table 1. Inputs. All are assumptions for a paper design.*

| Input | Value | Basis |
| --- | --- | --- |
| Typical cell | 18650, 1.8 Ah as found, arriving at 30 % state of charge; also 2.5 Ah (healthy laptop cell) and 4.5 Ah (salvaged 21700) | Near the 1.62 Ah mean in Olivero-Ortiz et al. (2026), cited in CCK-PRB-001 |
| Charge | 1.0 A CC to 80 % state of charge, then CV at 4.20 V with an exponential decay to 0.1 A | Typical at about 0.5C |
| Recharge for the rest | 1.0 A CC until the terminal reads 4.10 V under current, about 80 % state of charge | Charger modules are fixed at 4.20 V, so the firmware stops them |
| Discharge | 1.0 A to 2.80 V; delivered capacity equals the as-found capacity | |
| Rests, pulse, handling | 0.5 h and 0.25 h rests; 11 s resistance pulse; 0.5 h channel idle per cell for handling and 0.02 h for the day-14 reading | Handling allowance is conservative |
| Attended day | 10 h; charge, pulse, discharge and handling need a person present; rests do not | CCK-DDR-001 item 2 |
| Mean cell voltage | 3.90 V on charge, 3.65 V on discharge, 4.20 V worst case at the start of discharge | |
| Efficiencies | Charger module 85 %; adapter 88 %; controller, display and fans 3 W | |
| Monitor (INA226 class) | Shunt offset 10 µV; gain error 0.1 %; bus offset 7.5 mV; bus gain error 0.1 %; bus resolution 1.25 mV | Typical data sheet maximums; to be confirmed against the chosen part |
| Shunt | 25 mΩ, 0.5 %, 100 ppm/K over a 20 K swing | |
| Calibration | Two-point voltage calibration per channel against a meter of 0.05 % + 2 counts (1 mV); current gain calibrated to 0.1 % | One-time, at build |
| Cell behaviour | Near the 2.80 V cut-off, 1 % of capacity per 50 mV; resistance changes 1.5 %/K; open-circuit voltage changes 0.2 mV/K | Assumptions for a generic lithium-ion cell |
| Resistance pulse start | Only when the cell reads within 1 K of the bench thermistor, so reinsertions differ by 1 K at most | Firmware rule, CCK-DDR-002 item 13 |
| Temperature sensing | 10 kΩ NTC, B 3950, 1 %, 10 kΩ divider from 3.3 V; ADC error 20 mV after factory calibration; 0.3 K for part tolerance | ESP32-class ADC; assumption |
| Heatsink | 40 aluminium fins, 1.6 x 30 x 50 mm at 8 mm pitch on a 320 x 6 x 50 mm spine; case to sink 1.0 K/W through an insulating pad; junction to case 1.0 K/W | `cad/src/model.py` |
| Fans | 60 mm, 8 L/s free air each, half of that through the fins; Nusselt number 10 in the fin channels; 5 W/(m² K) effective with the fans stopped | Assumptions |
| Materials | Steel 7,850 kg/m³; aluminium 2,700 kg/m³; ceramic fibre sheet 128 kg/m³ | |
| Bought parts | Masses in `sizing.py` section 8 (holders 35 g each, modules 8 to 12 g, wiring 200 g) | Assumptions |

## 2. Cycle time and throughput (R5)

A typical 1.8 Ah cell occupies a channel for **6.33 h**: charge 0.90 h CC plus 0.92 h CV, rest 0.5 h, pulse, discharge 1.80 h, rest 0.25 h, recharge 1.44 h and 0.52 h of handling. A 2.5 Ah cell takes 8.30 h and a 4.5 Ah 21700 takes 13.93 h. The TRL 2 figure of about 6.5 h underestimated the CV phase and overestimated the recharge.

Because charge and discharge must be attended (CCK-DDR-001 item 2), throughput depends on the scheduling rule. A day-by-day simulation of the eight channels gives:

*Table 2. Cells finished per day, steady state, eight channels.*

| Rule | 1.8 Ah | 2.5 Ah | 4.5 Ah |
| --- | --- | --- | --- |
| A stage with current starts only if it finishes within the 10 h day | 12.0 | 8.0 | 4.8 |
| Current stages pause overnight with the unit switched off, and resume | 12.8 | 9.6 | 5.6 |
| Reference only: running 24 h, handling in attended hours (not allowed) | 16.0 | 16.0 | 8.0 |

On the first rule the grader finishes exactly 12 typical cells a day, so **R5 is at risk** with no margin, and it is not met on healthier 2.5 Ah cells. The pause rule gains 0.8 cells a day, but a discharge interrupted overnight lets the cell recover and adds a small capacity error that is not quantified here. One 4S6P pack needs about 36.4 candidates at the 66 % yield assumed in the flow diagram, so about 3.0 attended days plus the 14-day rest.

## 3. Power and energy (R13)

With all eight channels charging at 4.2 V and 1 A, the adapter supplies **42.5 W** (71 % of 60 W), or 3.54 A at 12 V; the 6.3 A main fuse is 1.78 times that. With the adapter at +5 % the highest voltage inside the unit is **12.6 V**, under the 13 V of R13.

Each typical cell takes 4.91 Wh on its first charge and 5.62 Wh on its recharge, plus 2.38 Wh of overhead, for **16.8 Wh** from the mains (about $0.0025 at $0.15/kWh). The load burns 6.57 Wh per cell as heat.

## 4. Heatsink and MOSFET temperature (R8)

At full discharge load the eight MOSFETs dissipate **29.2 W** on average and **33.6 W** at the start (4.2 V x 1 A x 8). To keep the MOSFET cases at 75 °C in a 35 °C room, the heatsink must reach **1.07 K/W** or better.

The fans push air into the back of the fin channels through a shroud, and the air leaves through the open tops. With 8.0 L/s through 39 channels the air speed is 0.64 m/s, the heat transfer coefficient is 20.3 W/(m² K) on 0.120 m² of fin area, and the fin efficiency is 0.964. Adding half of the 3.6 K air temperature rise and 0.10 K/W of spreading in the spine gives **0.58 K/W**. The MOSFET cases then reach **58.7 °C** and the junctions 62.9 °C, so **R8 is met**. If both fans stop, the heatsink falls to about 1.78 K/W and the cases would settle near **99 °C**, so the firmware must stop all discharges when the fan tachometer or a heatsink thermistor reports a fault. The 2.0 A resistance pulse adds 8.4 W to one MOSFET for 1 s, which is small against its thermal mass.

Cell heating at 1 A is small: 0.06 W and about 1.4 K for a 60 mΩ cell, 3.6 K at the 150 mΩ grade C limit and 10.0 K for the worst 418 mΩ cell reported by Olivero-Ortiz et al. (2026). The 8 K rise limit therefore flags high-resistance cells without tripping on healthy ones.

## 5. Measurement error budgets (R2, R3, R4, R6, R7)

**Capacity (R2).** Without calibration the worst case is the sum of the shunt tolerance (0.5 %), monitor gain (0.1 %), current offset (0.04 % at 1 A), shunt temperature drift (0.2 %) and the cut-off voltage error (12.4 mV, worth 0.25 % of capacity): **±1.09 %**. After calibration it is **±0.44 %**. R2 (±2 %) is met.

**Voltage (R3).** Without calibration the worst case is 7.5 mV offset, 4.3 mV gain error at 4.3 V and half a count: **±12.4 mV**, which does not meet ±10 mV. After a two-point calibration of each channel against a 0.05 % meter it is **±4.8 mV**. R3 is met only with the per-channel calibration, which is now part of the design.

**DC resistance (R4).** A 1.25 mV count over the 1.5 A current step gives **0.83 mΩ per count**. For a 60 mΩ cell, the repeatability over reinsertions sums to **±2.09 mΩ** worst case (0.83 mΩ quantization, 0.36 mΩ gain, 0.90 mΩ from a 1 K cell temperature difference) and ±1.28 mΩ RSS, against a limit of ±3.0 mΩ. Offsets cancel in the difference, and the four-wire contacts keep contact resistance out. The firmware starts the pulse only when the cell is within 1 K of the bench reading (CCK-DDR-002 item 13); version 0.1 allowed 2 K and found ±2.99 mΩ, at risk. **R4 is met** on the error budget. The 30 min rest before the pulse is normally enough for a cell that warmed by about 1.4 K on charge; a warmer cell waits longer, which this note does not add to the cycle time.

**Self-discharge (R6).** If the day-14 reading is taken in a different channel from the day-0 reading, the two calibrated readings and a 5 K room change give **±10.6 mV** worst case (±6.8 mV RSS) against ±3 mV. In the same channel, offset and gain cancel and the error falls to **±2.3 mV**. In addition, a cell whose charge stops under current relaxes by an amount this note cannot bound. Under CCK-DDR-002 item 13 each cell now returns to the channel it was graded in, so the reading error is **±2.3 mV**, inside ±3 mV, and its drop is judged against the median drop of the cells charged on the same day, which cancels the common part of relaxation and room temperature. The spread of relaxation between cells is still not bounded on paper, so **R6 remains at risk**.

**Temperature (R7).** The divider gives 27.2 mV/K at 45 °C; a 20 mV ADC error plus 0.3 K of part tolerance is **±1.04 K**, inside ±2 K. Sampling at 1 Hz is a firmware setting. The thermal lag of the clip is not analysed and is not verifiable at TRL 3.

## 6. Single-fault analysis (R9)

This is the failure mode and effects analysis called for at TRL 2, with the hardware watchdog and undervoltage comparators adopted in CCK-DDR-001 item 3. The watchdog removes every charge enable and every load gate drive when the controller stops refreshing it. Each channel's comparator removes that channel's load gate drive below 2.5 V. Each cell has a 3 A fast fuse in its positive lead, and the charge switch is in series between the charger and the cell.

*Table 3. Single faults against the R9 limits (above 4.25 V, above 60 °C, below 2.5 V).*

| Single fault | Effect without protection | What stops it | Result |
| --- | --- | --- | --- |
| Controller crash or firmware hang | Charger and load stay as last set; temperature limits lost | Watchdog opens all charge switches and removes all load gate drive | Safe |
| Load MOSFET fails short | Cell discharges through the channel | Short current is 31.3 A for a 60 mΩ cell and at least 5.9 A for a 418 mΩ cell at 2.8 V, 2.0 times the 3 A fuse or more; the fuse opens | Safe; cell rejected |
| Op-amp or gate drive stuck on | Load runs past the cut-off | Undervoltage comparator removes the gate drive at 2.5 V | Safe |
| Charger output regulates high (failed feedback) | Cell charged above 4.20 V | Firmware reads the monitor and opens the series charge switch at 4.25 V; current above 1.2 A also opens it | Safe |
| Charge switch fails short | Charger stays connected | Charger module limits the cell to 4.242 V (4.20 V + 1 %) | Safe |
| Thermistor open or shorted | Temperature reads out of range | Firmware treats a reading outside -20 to 80 °C as a fault and stops the channel | Safe |
| Thermistor clip detached | Reads the air, not the cell | Not detected; charger voltage limit still holds | **Residual risk** |
| Fan stops | MOSFETs could reach about 99 °C | Firmware stops discharges on a tachometer or heatsink fault | Safe (firmware) |
| Adapter output high | Bus voltage rises | Certified adapter; charger modules regulate their own output | Safe for R9; R13 depends on the adapter |

**R9 is met on analysis** for the faults it lists. The detached thermistor is a residual risk that R9 does not name; a plausibility check (cell temperature must rise slightly during discharge) narrows it and is now part of the firmware rules (CCK-DDR-002 item 13), but it is not verified at TRL 3. The fuses and comparators are not verified by test at TRL 3.

## 7. Containment (R10)

The 1.5 mm steel tray has 0.206 m² of sheet and weighs **2.43 kg**. If a 21700 cell in thermal runaway released 100 kJ in total, including burning vent gas (an assumption that must be replaced by a sourced figure before TRL 4), the mean tray temperature would rise about **84 K** if the tray absorbed all of it. Mean temperature says little about jets, hot spots on the bench under the tray, or flame through the perforated guard, and none of these can be analysed credibly on paper. **R10 is not verifiable at TRL 3.** The fan intake slots in the back wall (56 x 22 mm each) are a new path out of the tray and are noted for the containment review.

## 8. Size and mass (R11)

The model envelope is **460 x 300 x 85 mm** (the display stand and the 8 mm rubber feet set the height), inside 500 x 320 x 120 mm. The mass without the adapter is **4.94 kg**: tray 2.43 kg, base plate 0.47 kg, heatsink 0.52 kg, guard 0.24 kg, shroud 0.06 kg, liner 0.05 kg, and 1.17 kg of bought parts, fixings and wiring, which now include two fan finger guards (about 12 g) and the silicone used on the wire slots (about 10 g). **R11 is at risk** with 0.06 kg of margin (0.09 kg in version 0.5, before those two additions). In version 0.2 the unit was 75 mm and 4.97 kg; the constructable design (CCK-DDR-003) adds feet, fixings, guard flanges and a 5 V converter (about 0.12 kg) and takes 0.16 kg off by making the base plate 1.5 mm thick on six standoffs instead of 2 mm on four. With six supports the plate spans at most 165 mm between standoffs, so it stays stiff. A 1.2 mm tray would save about 0.49 kg, but the tray is also the containment, so Amish decided on 2026-10-02 to keep the 1.5 mm tray and accept the mass (4.91 kg when decided, 4.94 kg with the finger guards and silicone), with the prototype weighed at TRL 4 (CCK-DEC-001, item 5).

## 9. Grading and matching on synthetic data (R15)

The grading rules (CCK-PRC-001 Table 2) and the matching method were run on 150 synthetic cells drawn from a seeded random generator: capacity normal with mean 1.62 Ah and standard deviation 0.53 Ah (clipped to 0.04 to 2.50 Ah, the figures reported by Olivero-Ortiz et al., 2026), resistance log-normal with a 75 mΩ median (an assumption), and 2.2 Ah rated capacity. They produce 15 grade A, 47 grade B, 55 grade C and 33 rejected cells. For a 4S6P pack from grade B, the method picks the 24 cells with the narrowest capacity window, distributes them with a serpentine sort and then swaps cells between groups while that reduces the spread. The four parallel groups come out at 9.677 to 9.678 Ah, a **0.006 %** maximum deviation from the mean. R15 is met on synthetic data; real cells will be less tidy.

## 10. Second-life SwapCell variant (study)

CCK-DDR-001 item 1 keeps SwapCell in the pitch and asks for a second-life variant to be studied. A 13S4P pack of grade A laptop cells at 80 % of 2.2 Ah holds **7.04 Ah and about 334 Wh**, and at the 0.5C limit for grade A it can deliver **3.52 A**, about **165 W**. That covers PowerBox's reference evening of 224.8 Wh from the pack 1.34 times (PBX-CAL-001), but not its 300 W inverter, which draws about 8.7 A at 39 V. An assumed 330 x 84 x 74 mm cell space inside the SwapCell body holds up to 80 cells of 18650 size, so 52 cells fit before the BMS and wiring are placed. The study therefore supports a low-current storage variant for PowerBox with the AC output limited to about 150 W, or a DC-only PowerBox, and rules out e-bike use. Any variant needs the SwapCell project's agreement and its own pack design; it is not a CellCheck deliverable.

## 11. Cost (R12)

Value-engineering target: USD 175.00. Estimated cost of the constructable design: USD 177.60 (USD 2.60 over the target). The target is in `project.yaml`, a hypothetical control target, not a limit; `budget_usd` is unchanged. Amish accepted the $175 target on 2026-09-25 (CCK-DDR-002 item 4). The 21 BOM lines total **$177.60**, so **R12 is over the value-engineering target by $2.60**. The increase over TRL 2 is line 18 (watchdog and comparators, $5.00); the increase over version 0.2 ($164.00) is lines 19 to 21, added for construction (rubber feet $2.40, fixings $4.00, 5 V converter $2.00); the increase over version 0.5 ($172.40) is $5.20, the two fan finger guards on line 10 ($0.60 each, $1.20 for two, a typical online marketplace price for a 60 mm wire fan grill) and a small tube of high-temperature silicone on line 16 ($4.00, a 30 g tube rated to about 260 °C). All prices are estimates, not quotes.
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

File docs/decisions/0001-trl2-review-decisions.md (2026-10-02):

---
doc_id: CCK-DDR-001
title: CellCheck TRL 2 review decisions
project: CellCheck
doc_type: Design decision record
version: "0.3"
status: Draft
date: '2026-10-02'
author: Amish Chadha
license: CERN-OHL-S-2.0
revisions:
- version: "0.1"
  date: '2026-09-25'
  author: Amish Chadha
  change: Record the TRL 2 review items adopted for TRL 3 under Amish's 2026-09-25 instruction, open for his review, and the items that stay open
- version: "0.2"
  date: '2026-09-25'
  author: Amish Chadha
  change: Recommendations accepted by Amish (DDR-002)
- version: "0.3"
  date: '2026-10-02'
  author: Amish Chadha
  change: Items 10, 12, 14 and 16 decided by Amish on 2026-10-02 as recommended in CCK-DEC-001
---

# 0001: TRL 2 review decisions

- **Date:** 2026-09-25
- **Status:** decided for items with a recommendation. On 2026-09-25 Amish accepted all recommendations (CCK-DDR-002): items 1 to 9, 11, 13 and 15 are Decided by Amish, 2026-09-25: go with recommendation. Items 10, 12, 14 and 16, which had no recommendation here, were given recommendations in the design decisions register (CCK-DEC-001, open items 3 to 6) and accepted by Amish on 2026-10-02: "i approve your recommendations for all 555 open decisions."
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

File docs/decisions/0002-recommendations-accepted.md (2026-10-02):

---
doc_id: CCK-DDR-002
title: CellCheck recommendations accepted
project: CellCheck
doc_type: Design decision record
version: "0.2"
status: Draft
date: '2026-10-02'
author: Amish Chadha
license: CERN-OHL-S-2.0
revisions:
- version: "0.1"
  date: '2026-09-25'
  author: Amish Chadha
  change: Record Amish's acceptance of all recommendations and what changed in the repo
- version: "0.2"
  date: '2026-10-02'
  author: Amish Chadha
  change: Items 10, 12, 14 and 16 decided by Amish on 2026-10-02 as recommended in CCK-DEC-001
---
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

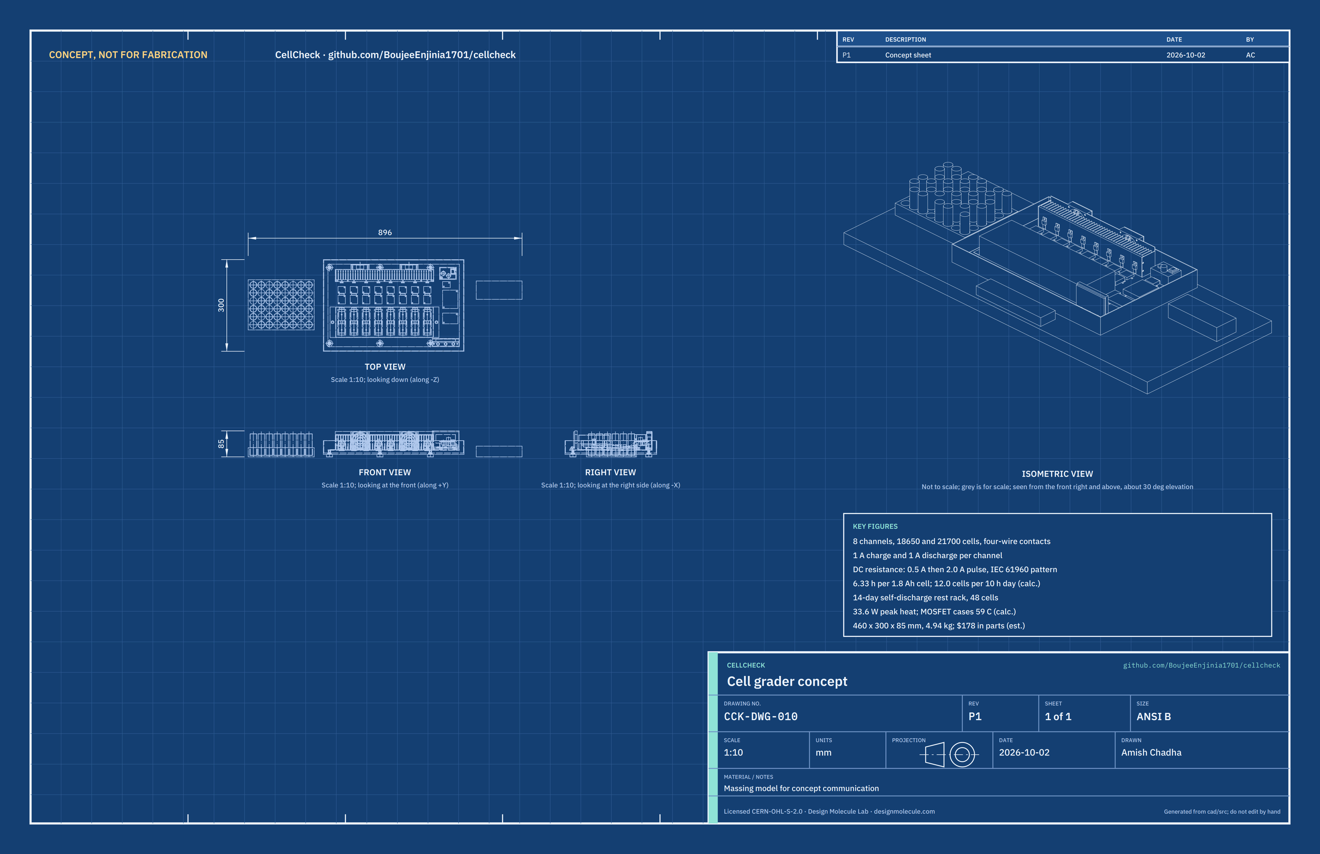
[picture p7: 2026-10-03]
media/concept-blueprint.png

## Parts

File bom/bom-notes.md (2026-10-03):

# BOM notes

- Prices are indicative US dollar prices for single units from general electronics distributors, online marketplaces and hardware stores in 2026. They are estimates, not quotes.
- Line numbers 1 to 15, 18 and 21 match the callouts in `media/exploded.png`, the parts in `cad/src/model.py` and the general arrangement CCK-DWG-001. Line 19 (rubber feet) is drawn with the tray and line 20 (fixings) with the parts it holds. The finger guards of line 10 and the silicone seals of line 16 are modelled; the wiring, fuses and labels of lines 16 and 17 are not.
- Total at quantity one: **$177.60** (checked by `docs/04-calcs/sizing.py`, CCK-CAL-001 section 11). Cells are not included.
- Against the `project.yaml` value-engineering target of $175 (a hypothetical control target, not a limit) the estimated cost is $2.60 over, so R12 is over the target. The target is not a limit and `budget_usd` is unchanged; the overshoot is raised as an open decision in CCK-DEC-001. Amish raised the target from $160 to $175 on 2026-09-25 (CCK-DDR-001 item 4, CCK-DDR-002); against $160 the BOM was $4.00 over.
- Line 18 (hardware watchdog and undervoltage comparators, $5.00) is new at TRL 3 and closes R9 on paper (CCK-DDR-001 item 3). Line 16 includes the 3 A per-cell fuses that the single-fault analysis relies on.
- Module choices (charger, current monitor, controller) were decided by Amish on 2026-09-25 (CCK-DDR-001 item 6). Purchasing is TRL 4 work and on hold.
- Buy only a certified mains adapter (line 14). CellCheck has no mains wiring of its own.
- Lines 19 (rubber feet with M4 studs), 20 (fixings) and 21 (12 V to 5 V converter) and the respecified lines 1 to 5, 7 to 10, 12, 13 and 16 come from the design for construction (CCK-DDR-003, 2026-10-01); the making sketches are CCK-DWG-101 to 110 and the build plan is CCK-BLD-001.
- Decided by Amish on 2026-10-02 (CCK-DEC-001): fan finger guards go into line 10 with an estimated price (item 9); high-temperature silicone for sealing the wire slots goes into line 16 (item 2); the matched-group bins stay out of the BOM until TRL 4 purchasing (item 8); the guard stays round-hole perforated 0.8 mm steel (item 10); the tray stays 1.5 mm steel (item 5). Both changes are now in the lines and the total: line 10 is $2.60 each for two (fan $2.00, steel wire finger guard $0.60, a typical online marketplace price for a 60 mm wire fan grill), and line 16 is $12.00 (wiring and fuses $8.00 plus a 30 g tube of 260 °C rated silicone sealant, $4.00, of which about 10 g is used). Line 20 now also counts eight small self-tapping screws for the guards, at no change in price. All three are estimates, not quotes.

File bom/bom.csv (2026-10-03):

item | qty | spec | supplier | unit_cost_usd | make_buy | notes
1 Steel tray with ceramic fibre liner | 1 | Steel tray 460 x 300 x 45 mm, 1.5 mm wall; two 56 x 22 mm fan intake slots in the back wall and six 4.5 mm stud holes in the floor; 3 mm ceramic fibre sheet on the floor, cut round the standoffs | Hardware or kitchen supply store; ceramic fibre from a kiln or stove supplier | 12.00 | buy | Indicative price; slots and holes cut by the builder (CCK-DWG-101, 102)
2 Base plate on standoffs | 1 | 1.5 mm aluminium sheet 430 x 270 mm, drilled and slotted; six M4 x 12 mm hex standoffs | Local sheet metal supplier | 8.00 | make | Indicative price; was 2 mm on four 10 mm standoffs (CCK-DDR-003, CCK-DWG-103)
3 Cell holder with four-wire contacts | 8 | Adjustable 18650 and 21700 holder, spring contacts with separate force and sense leads, two M3 fixing holes in the base | Electronics distributor or online marketplace | 2.50 | buy | Indicative price
4 NTC thermistor in a printed clip | 8 | 10 kOhm 1 % NTC, B 3950, in a printed PETG C-clip; one set of clips for 18650 and one for 21700 | Electronics distributor | 0.50 | buy | Indicative price; clips printed by the builder (CCK-DWG-109)
5 Perforated steel cell guard | 1 | 0.8 mm perforated steel, about 50 % open, folded to 320 x 100 x 49 mm with two 18 mm end flanges | Hardware store | 6.00 | make | Material cost only (CCK-DWG-108)
6 Charger module | 8 | 1 A CC-CV lithium-ion buck charger, 4.20 V +/-1 %, 12 V input (TP5100 class) | Online marketplace or electronics distributor | 1.50 | buy | Indicative price; adopted for TRL 3 (CCK-DDR-001 item 6)
7 Channel board | 8 | INA226-class current and voltage monitor breakout, 25 mOhm 0.5 % shunt, on a perfboard carrier with the series charge switch MOSFET, the op-amp of the load loop and fuse clips for the 3 A channel fuse | Electronics distributor | 2.75 | buy | Indicative price; stock breakouts need the shunt changed
8 Load MOSFET and op-amp loop | 8 | Logic-level MOSFET in TO-220, 0.5 to 2.0 A constant current set by the op-amp on the channel board; insulating pad and shoulder washer | Electronics distributor | 1.00 | buy | Indicative price
9 Heatsink | 1 | Aluminium spine 320 x 6 x 50 mm with 40 vertical fins 1.6 x 30 x 50 mm at 8 mm pitch (extrusion or bonded fins); drilled and tapped M3 for the MOSFETs, plate screws and shroud screws | Electronics distributor or aluminium extrusion stockist | 8.00 | buy | Indicative price; see CCK-CAL-001 section 4 and CCK-DWG-104
10 Fan with shroud and finger guard | 2 | 60 mm 12 V DC fan with tachometer and a 60 mm steel wire finger guard fixed with four small self-tapping screws; folded 1 mm aluminium shroud with two side flanges, screwed to the heatsink ends (shared) | Electronics distributor | 2.60 | buy | Indicative price: fan 2.00 and finger guard 0.60 (typical online marketplace price for a 60 mm wire fan grill; CCK-DEC-001 item 9); shroud from 1 mm sheet (CCK-DWG-105)
11 Controller board | 1 | ESP32-S3 class with microSD slot and Wi-Fi | Electronics distributor | 10.00 | buy | Indicative price; adopted for TRL 3 (CCK-DDR-001 item 6)
12 Display and buttons | 1 | 2.8 in SPI display module (about 86 x 50 mm board), three push buttons, printed stand | Electronics distributor or online marketplace | 8.00 | buy | Indicative price; stand printed by the builder (CCK-DWG-106)
13 Power inlet with fuse and switch | 1 | Panel-mount DC jack, 6.3 A fuse and panel fuse holder, rocker switch, in a printed housing | Electronics distributor | 5.00 | buy | Indicative price; housing printed by the builder (CCK-DWG-107)
14 Mains adapter | 1 | Certified 12 V 5 A (60 W) DC adapter with safety marks for the country of use | Electronics distributor | 15.00 | buy | Indicative price; certified unit only
15 Self-discharge rest rack | 1 | 3D-printed rack for 48 cells in numbered slots, 216 x 164 x 30 mm | Self (3D printer) | 6.00 | make | Material cost only (CCK-DWG-110)
16 Wiring and channel fuses | 1 | Silicone wire, per-channel 3 A fast fuses (in clips on the channel boards), connectors, heat-shrink, edge grommet strip for the plate slots, one 30 g tube of high-temperature silicone sealant (about 10 g used to seal the 16 wire slots) | Electronics distributor | 12.00 | buy | Indicative price: wiring and fuses 8.00 plus sealant 4.00 (small tube of 260 C rated RTV silicone; CCK-DEC-001 item 2); seals modelled, wiring not
17 Cell ID labels and insulator rings | 1 | Printed labels, replacement insulator rings and wraps | Online retailer | 3.00 | buy | Indicative price; not modelled
18 Watchdog and undervoltage board | 1 | Hardware watchdog timer gating all charge and load enables, eight 2.5 V undervoltage comparators, small perfboard | Electronics distributor | 5.00 | buy | Indicative price; adopted for TRL 3 (CCK-DDR-001 item 3)
19 Rubber feet with M4 stud | 6 | Rubber bumper foot about 20 mm diameter x 8 mm with M4 x 8 mm steel stud | Hardware store or online marketplace | 0.40 | buy | Indicative price; added for construction (CCK-DDR-003)
20 Fixings | 1 | Stainless M3 and M4 screws and nuts, 5 mm nylon standoffs, two M4 blind rivet nuts for 0.5 to 3 mm sheet, two M4 knurled thumb screws with 14 mm heads, eight small self-tapping screws for the fan finger guards | Hardware store or electronics distributor | 4.00 | buy | Indicative price; added for construction (CCK-DDR-003)
21 12 V to 5 V converter | 1 | Buck converter module, 12 V in, 5 V 3 A out, two mounting holes | Electronics distributor or online marketplace | 2.00 | buy | Indicative price; feeds the controller, display and channel boards (CCK-DDR-003)

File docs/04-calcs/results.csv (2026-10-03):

id | value | target | status
R12 | $177.60; $2.60 over the $175 target | $175 or less (project.yaml) | Over the value-engineering target
R5 | 12.0 cells/day if current stages finish the same day; 12.8 with an overnight pause; 8.0 for 2.5 Ah cells | 12 cells/day on 1.8 Ah cells | At risk
R6 | +/-2.3 mV in the same channel (+/-10.6 across channels, not allowed); judged against the same-day cohort median; spread of relaxation between cells not bounded | +/-3 mV; flag above 50 mV | At risk
R11 | 460 x 300 x 85 mm; 4.94 kg | 500 x 320 x 120 mm; 5 kg | At risk
R10 | Mean tray rise 84 K for an assumed 100 kJ event; jets, hot spots and flame not analysable on paper | Hold one venting 21700 within the tray | Not verifiable at TRL 3
R1 | 8 channels; holders for 18650 and 21700 (cell to 70 mm long, 21.0 mm diameter) | 18650 and 21700, 8 channels or more | Met (design review)
R2 | +/-1.1 % uncalibrated, +/-0.4 % calibrated (worst case) | +/-2 % | Met
R3 | +/-12.4 mV uncalibrated; +/-4.8 mV after per-channel calibration | +/-10 mV | Met (with per-channel calibration)
R4 | 0.83 mOhm per count; +/-2.09 mOhm worst case, +/-1.28 RSS at 60 mOhm | 1 mOhm; +/-3 mOhm or 5 % | Met
R7 | +/-1.0 K at 45 C, 1 Hz sampling; clip response time not analysed | 1 Hz, +/-2 K; stop at 45 C or +8 K | Met (accuracy); response not verifiable at TRL 3
R8 | 59 C case (0.58 K/W with fans); 99 C if the fans stop | 75 C or less at 35 C room | Met
R9 | Met on FMEA with watchdog, UV comparators and 3 A channel fuses (short gives at least 5.9 A); detached thermistor is a residual risk | No single fault: >4.25 V, >60 C or <2.5 V | Met (analysis)
R13 | 12 V certified adapter, bus at most 12.6 V, 43 W of 60 W | Certified 12 V; 13 V or less inside; no mains wiring | Met (design review)
R14 | Rest stage unattended (no current); charge and discharge attended (DDR item 2) | Rest stage unattended; current stages attended (redefined v0.3) | Met (design review)
R15 | 4S6P from 47 grade B synthetic cells: max group deviation 0.01 % | Configurable grades; groups within +/-1 % | Met (synthetic data)
R16 | CSV per cell; group and reject lots map to the ReflowEconomy passport v0.2 (two schema gaps) | CSV per cell; local export; no cloud | Met (design review)
R17 | Modules and through-hole parts; CERN-OHL-S-2.0 and MIT | Off-the-shelf; open licences | Met (design review)

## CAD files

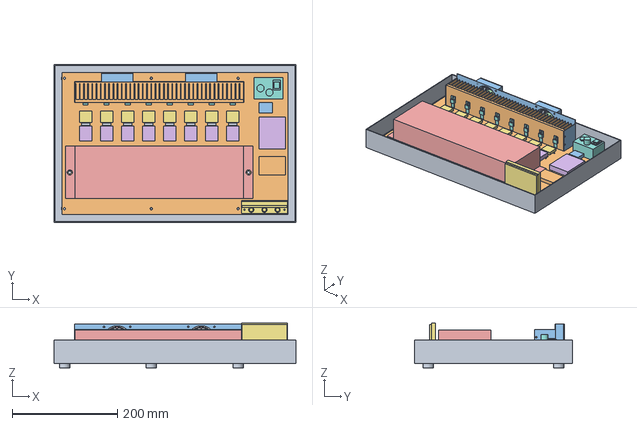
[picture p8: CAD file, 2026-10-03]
cad/step/cellcheck-assembly.step
460.0 x 300.0 x 85.0 mm

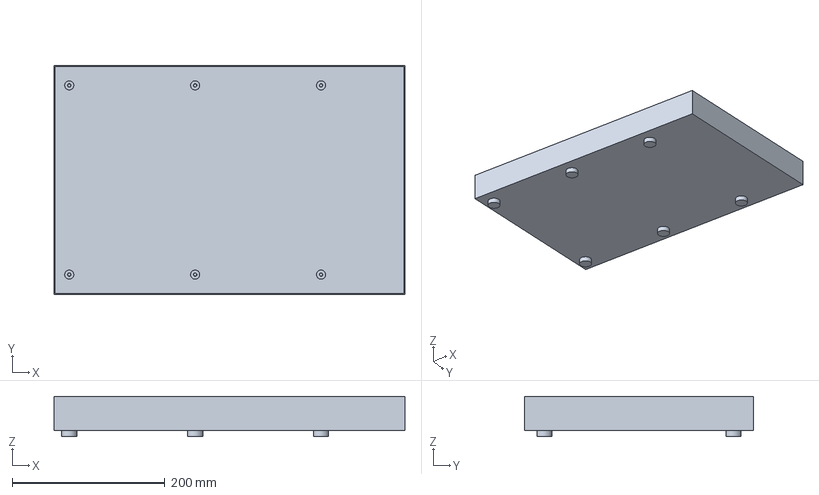
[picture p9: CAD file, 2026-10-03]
cad/step/cellcheck-tray.step
460.0 x 300.0 x 53.0 mm

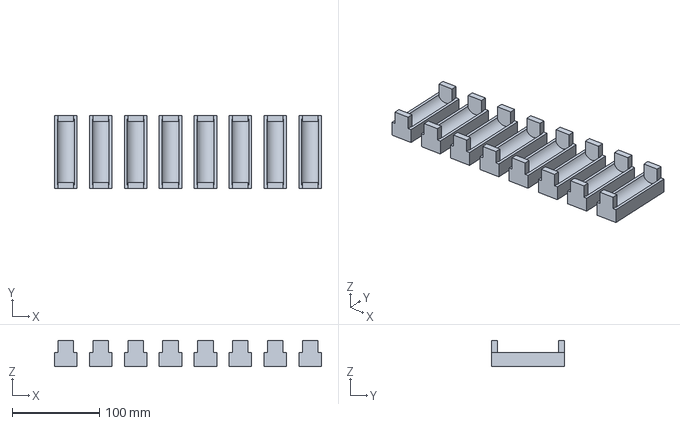
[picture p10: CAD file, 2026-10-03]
cad/step/cellcheck-cell-holders.step
306.0 x 84.0 x 30.0 mm

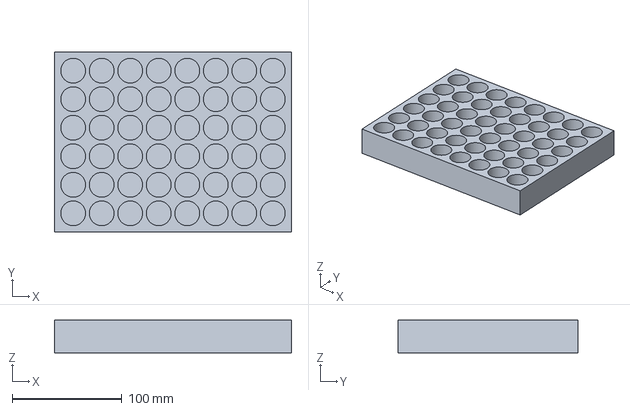
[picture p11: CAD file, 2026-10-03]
cad/step/cellcheck-rest-rack.step
216.0 x 164.0 x 30.0 mm

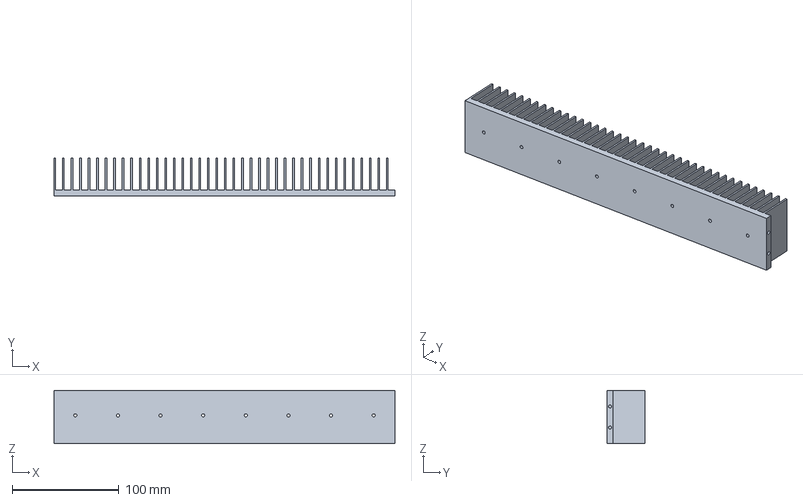
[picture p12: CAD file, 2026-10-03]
cad/step/cellcheck-heatsink.step
320.0 x 36.0 x 50.0 mm

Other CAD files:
cad/stl/cellcheck-assembly.stl
cad/stl/cellcheck-cell-holders.stl
cad/stl/cellcheck-heatsink.stl
cad/stl/cellcheck-rest-rack.stl
cad/stl/cellcheck-tray.stl

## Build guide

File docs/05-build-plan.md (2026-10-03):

---
doc_id: CCK-BLD-001
title: CellCheck prototype build plan
project: CellCheck
doc_type: Build plan
version: "0.4"
status: Draft
date: '2026-10-02'
author: Amish Chadha
license: CERN-OHL-S-2.0
revisions:
  - version: "0.1"
    date: '2026-10-01'
    author: Amish Chadha
    change: First build plan, with pictures by component and step; design made constructable (CCK-DDR-003)
  - version: "0.2"
    date: '2026-10-02'
    author: Amish Chadha
    change: 'Decided items of 2026-10-02 carried in: wire slots sealed with high-temperature silicone after wiring (step 9), fan finger guards (CCK-DEC-001, items 2 and 9)'
  - version: "0.3"
    date: '2026-10-02'
    author: Amish Chadha
    change: "Section 2: the changes recorded in CCK-DDR-003 accepted by Amish on 2026-10-02"
  - version: "0.4"
    date: '2026-10-02'
    author: Amish Chadha
    change: "Pictures and text updated for the fan finger guards and the silicone-sealed wire slots: new step 9 picture, plate hole figure, joint 4 and joint 6, fan shroud sketch; figures of mass and cost; model checks 139; general arrangement Rev P3"
---

# CellCheck prototype build plan

**Plan, not yet built.** How to build the first proof-of-concept prototype, component by component. Building and testing to it is TRL 4 work. Decisions still to be made are kept in the design decisions register ([docs/06-design-decisions.md](06-design-decisions.md)), not here.

## 1. What you are building

Figure 1. Every component, pulled apart and numbered in build order

*Figure 1. Every component pulled apart and numbered in build order. The rest rack (18) and the adapter (19) stand on the bench beside the tray.*

The prototype is an eight-channel cell grader built into a steel tray that stands on six rubber feet. Inside the tray a ceramic fibre liner covers the floor, and an aluminium base plate on six standoffs carries everything else: eight cell holders under a lift-off perforated steel guard, a charger module and a channel board for each channel, eight load transistors on a finned heatsink with two fans behind it, and a controller, watchdog board, 5 V converter, display and power inlet on the right. A printed rack beside the tray holds 48 cells during their 14-day rest, and a certified 12 V adapter powers the unit. Figure 1 shows the 19 components in the order you make or fit them. Ten are made or worked in a small workshop: the tray (cut and drilled), the liner, the base plate, the heatsink (drilled and tapped), the fan shroud, the guard, and four printed parts (display stand, inlet housing, thermistor clips and rest rack). Everything else is bought and fitted. The work is cutting, drilling, tapping and folding aluminium and steel sheet, cutting ceramic fibre, 3D printing, and wiring bought modules with soldered and crimped joints. The parts cost about $178 from the bill of materials.

> **Safety:** CellCheck charges and discharges salvaged lithium-ion cells, which can overheat, vent flammable and toxic gas, and burn. Keep every cell out of the workshop until stop S1 in section 6, out of the holders until stop S5, and never leave a cell charging or discharging unattended. Ceramic fibre dust irritates the lungs and skin: cut it with a dust mask, gloves and long sleeves. Cut steel and aluminium edges are sharp: deburr everything and wear cut-resistant gloves for sheet work. The unit uses only 12 V from a certified adapter; never wire mains into it.

## 2. What changed to make it buildable

The concept showed what the grader does; most of its parts had no fixing, two had no room for what goes in them, and three parts the electronics need were missing. Each change below keeps what the grader does, and all of them are recorded in decision record CCK-DDR-003, accepted by Amish on 2026-10-02.

*Table 1. Changes from the concept.*

| Component | The concept had | The buildable design has | Why |
| --- | --- | --- | --- |
| Tray, standoffs and feet | Four standoffs resting loose on the soft liner | Six rubber feet whose studs pass up through the tray floor into six standoffs on the bare steel (Figure 3) | The plate is fixed to the tray, and the standoffs bear on steel |
| Base plate | 2 mm sheet on four standoffs, two screws hidden under the display and inlet | 1.5 mm sheet on six standoffs, every screw reachable from above (Figure 6) | Keeps the unit under its 5 kg limit after the added fixings |
| Cell holders and leads | No fixing; no way for the leads out of the guard | Two screws from below per holder; two wire slots per channel through the plate, leads run underneath (Figures 6 and 18) | The guard stays closed on every side |
| Guard | A frame of bars with no fixing | A folded perforated steel box with end flanges, held by two thumb screws into rivet nuts (Figure 16) | It lifts off for a cell change without tools |
| Boards | Sitting on the aluminium plate | Each on two 5 mm nylon standoffs (Figure 7) | Solder joints cannot short to the plate |
| Display stand | 60 mm wide, too small for a 2.8 in display module | 88 mm wide printed stand with the buttons in its foot (Figure 12) | The bought display fits |
| Heatsink and shroud | No fixings; the shroud's top lip could not be folded | Screws into the spine from below and at each end; MOSFETs clamped with insulated screws; shroud folded with side flanges (Figures 9 and 11) | Every part is fixed and can be made from one sheet |
| Thermistor clip | A block resting on the cell | A printed C-clip that springs over the cell (Figure 18) | It holds itself and the thermistor touches the cell |
| Power inlet | Jack facing the tray wall 23 mm away | Jack, fuse holder and switch on top of a printed housing (Figure 14) | Room for the plug; no new hole in the tray |
| Electronics | No 5 V supply; no home for the load loop's op-amp, the charge switch or the channel fuse | A 5 V converter; each channel's current monitor on a small perfboard with the charge switch, op-amp and fuse clips (Figure 20) | Everything the protection relies on exists and the fuses can be reached |

## 3. Making the components

Make and check each component before the assembly step that needs it. Sizes are in millimetres. "Left" and "right" are as seen standing in front of the grader, where the cells are; "front" is the side nearest you. Workshop tolerance is 0.5 mm unless a step says otherwise; drawings do not carry tolerances before TRL 4.

### 3.1 Steel tray

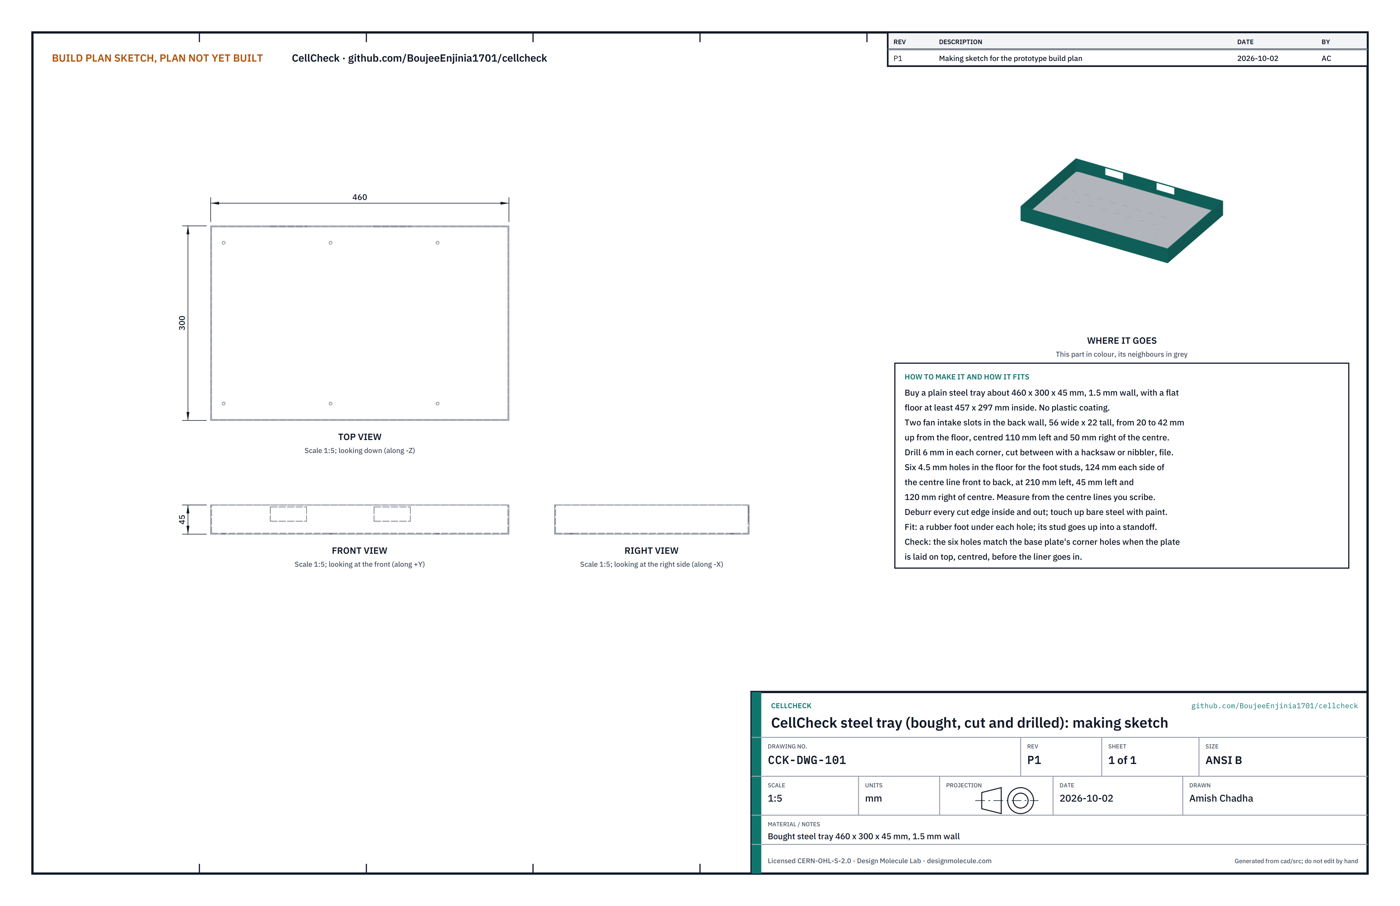
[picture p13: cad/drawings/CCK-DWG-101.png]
Figure 2. Making sketch of the steel tray


*Figure 2. Steel tray making sketch (CCK-DWG-101).*

**What it is and what it is made from.** The open steel tray that everything sits in, and the first line of containment if a cell vents. A bought plain steel tray, about 460 x 300 x 45 mm with 1.5 mm walls and a flat floor at least 457 x 297 mm inside, with no plastic coating.

**How to make it.**

1. Scribe a centre line across the floor from left to right and another from front to back, inside and outside.
2. Mark two fan intake slots on the back wall, each 56 wide and 22 tall, running from 20 to 42 up from the floor, centred 110 left and 50 right of the centre line.
3. Drill a 6 mm hole in each corner of each slot, cut between the holes with a hacksaw or nibbler, and file the edges straight.
4. Mark six stud holes in the floor, 124 each side of the left-to-right centre line, at 210 left, 45 left and 120 right of the front-to-back centre line. Centre punch and drill 4.5 mm.
5. Deburr every cut inside and out and touch up bare steel with paint so it does not rust.

**How it fits the parts next to it.**

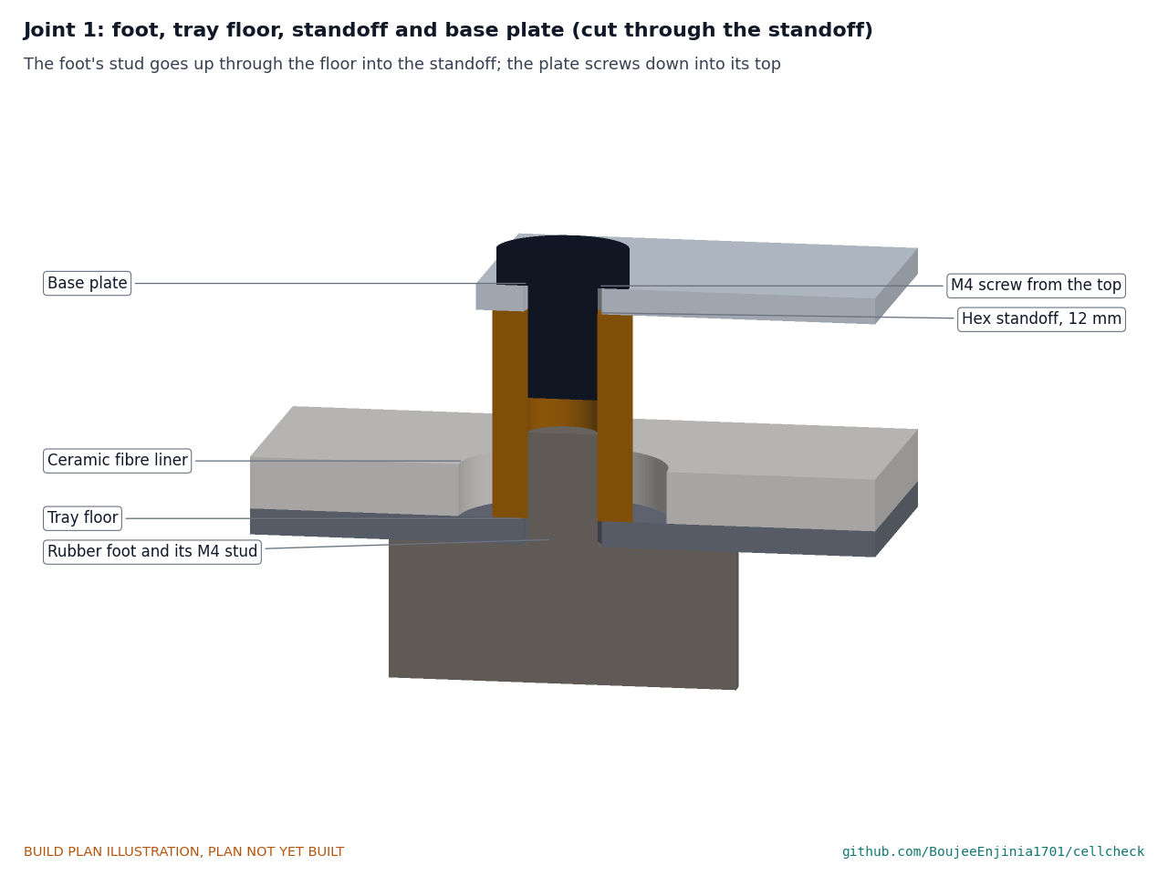
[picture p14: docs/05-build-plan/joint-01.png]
Figure 3. Joint 1: foot, tray floor, standoff and base plate


*Figure 3. A rubber foot under the floor; its stud goes up through the floor into a hex standoff, and the base plate screws down onto the standoff's top.*

Each rubber foot sits under a stud hole; its M4 stud passes through the 1.5 mm floor and screws into the bottom of a 12 mm hex standoff, which stands on the bare steel through a hole in the liner. The tray stands 8 mm off the bench on the six feet.

**Check before moving on.** Lay the base plate on top of the tray, centred, and look down through its six standoff holes: each must line up with a stud hole in the floor.

### 3.2 Ceramic fibre liner

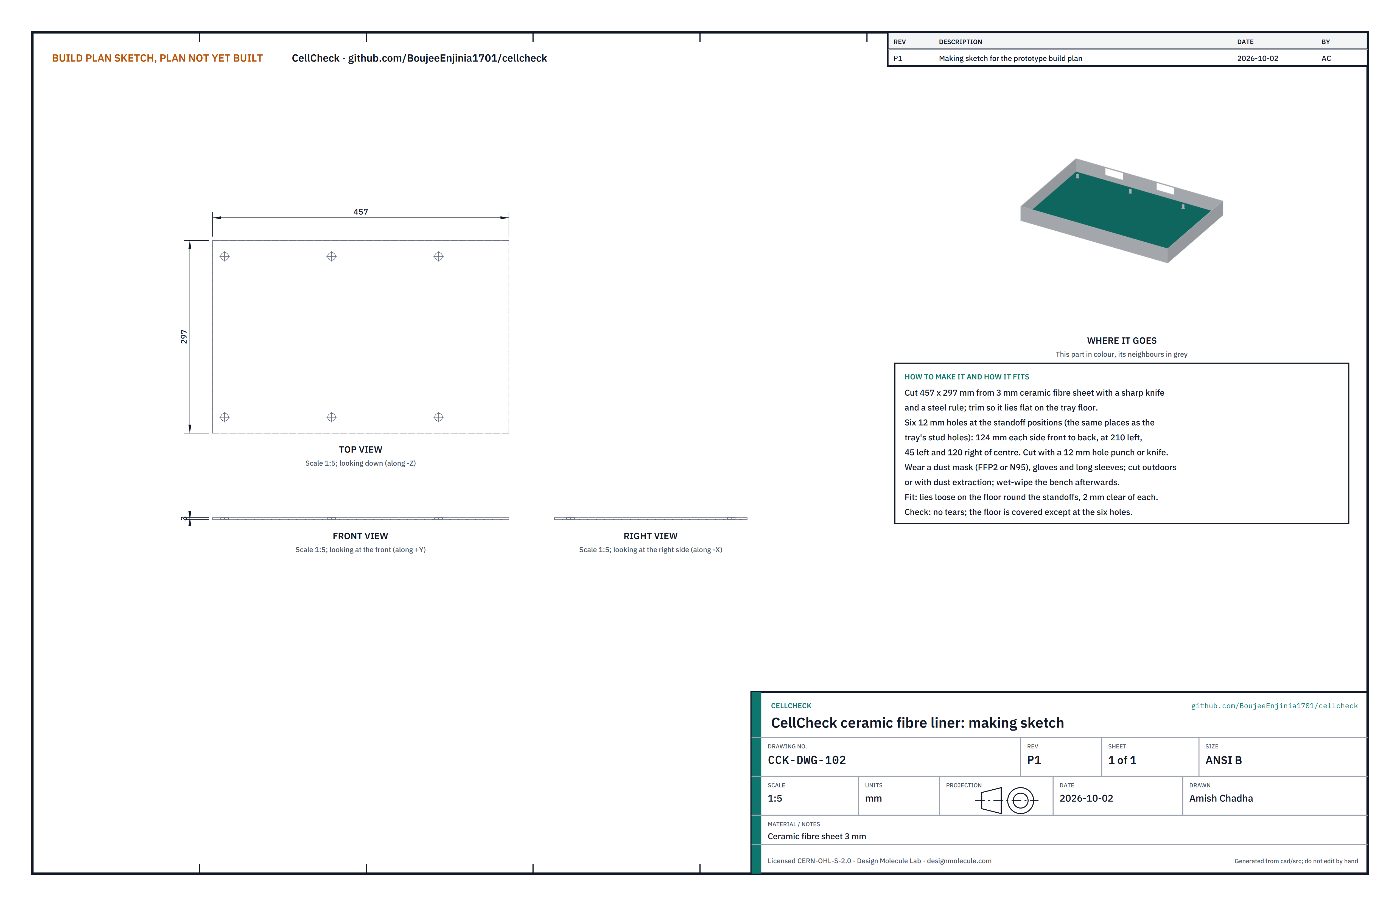
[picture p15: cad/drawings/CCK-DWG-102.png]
Figure 4. Making sketch of the liner


*Figure 4. Ceramic fibre liner making sketch (CCK-DWG-102).*

**What it is and what it is made from.** A heat-resisting sheet on the tray floor under everything. Ceramic fibre sheet 3 mm thick.

**How to make it.**

1. Work outdoors or with dust extraction, wearing a dust mask (FFP2 or N95), gloves and long sleeves.
2. Cut a piece 457 x 297 with a sharp knife against a steel rule, and trim it so it lies flat on the tray floor.
3. Mark the six standoff positions through the stud holes from below, and cut a 12 mm hole at each with a hole punch or knife.
4. Wet-wipe the bench and bag the offcuts.

**How it fits the parts next to it.** It lies loose on the floor; each standoff stands in a liner hole with 2 mm clear all round (Figure 3).

**Check before moving on.** No tears; the floor is covered everywhere except the six holes.

### 3.3 Base plate

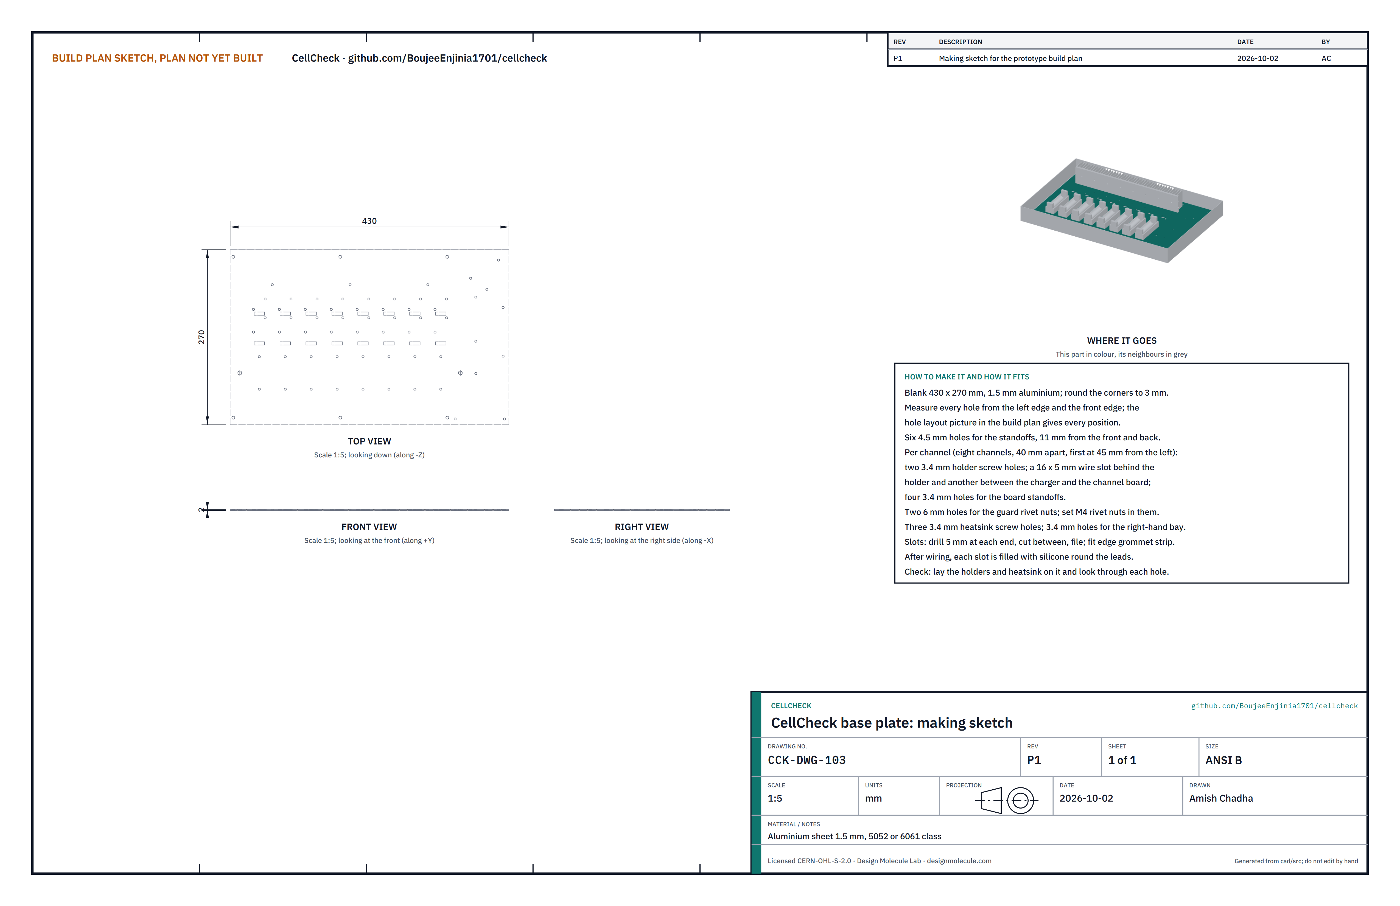
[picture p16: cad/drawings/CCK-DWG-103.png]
Figure 5. Making sketch of the base plate


*Figure 5. Base plate making sketch (CCK-DWG-103).*

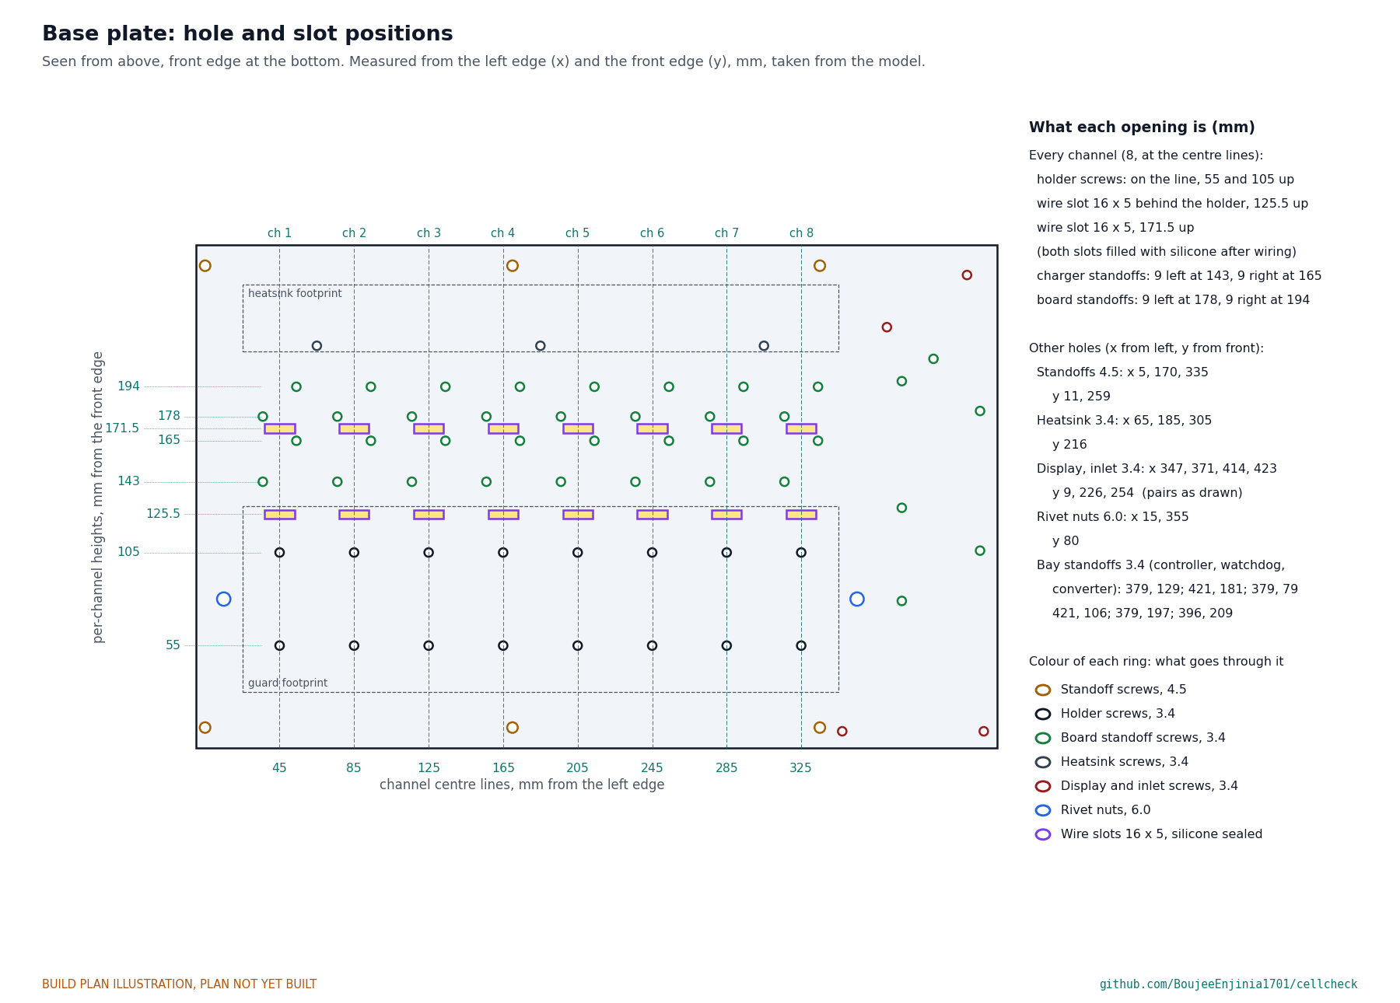
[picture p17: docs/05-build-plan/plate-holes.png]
Figure 6. Hole and slot positions on the base plate


*Figure 6. Every hole and slot, measured from the left edge and the front edge. Each ring's colour says what goes through it; the wire slots, shaded yellow, are filled with silicone after wiring (step 9).*

**What it is and what it is made from.** The flat plate that carries every part inside the tray. Aluminium sheet 1.5 mm thick, 5052 or 6061 class, cut to 430 x 270.

**How to make it.**

1. Cut the blank square to 430 x 270, file the edges and round the corners to about 3 mm.
2. Choose the top face and mark it. Mark the front edge.
3. Scribe the eight channel centre lines from front to back, 40 apart, the first 45 from the left edge (Figure 6).
4. On each channel line mark, measured up from the front edge: holder screw holes at 55 and 105; a wire slot centred at 125.5; a wire slot centred at 171.5; charger standoff holes 9 left of the line at 143 and 9 right at 165; channel board standoff holes 9 left at 178 and 9 right at 194.
5. Mark the other holes from the key of Figure 6: six standoff holes, three heatsink screw holes, two rivet nut holes, and the holes for the controller, watchdog board, converter, display stand and inlet housing.
6. Drill the standoff holes 4.5 mm, the rivet nut holes 6 mm and all the others 3.4 mm.
7. Wire slots, 16 long and 5 wide: drill 5 mm at each end, cut between with a fine saw or nibbler, and file square. Fit edge grommet strip round each slot. After the wiring (step 9) each slot is filled with high-temperature silicone round the leads.
8. Deburr every hole on both faces.
9. Set an M4 blind rivet nut in each 6 mm hole with the hand tool, its thin head on the top face.

**How it fits the parts next to it.** The plate's underside sits on the six standoffs, held by six M4 screws from the top (Figure 3); under it the cell leads run in a 9 mm space above the liner. Every other part stands on its top face.

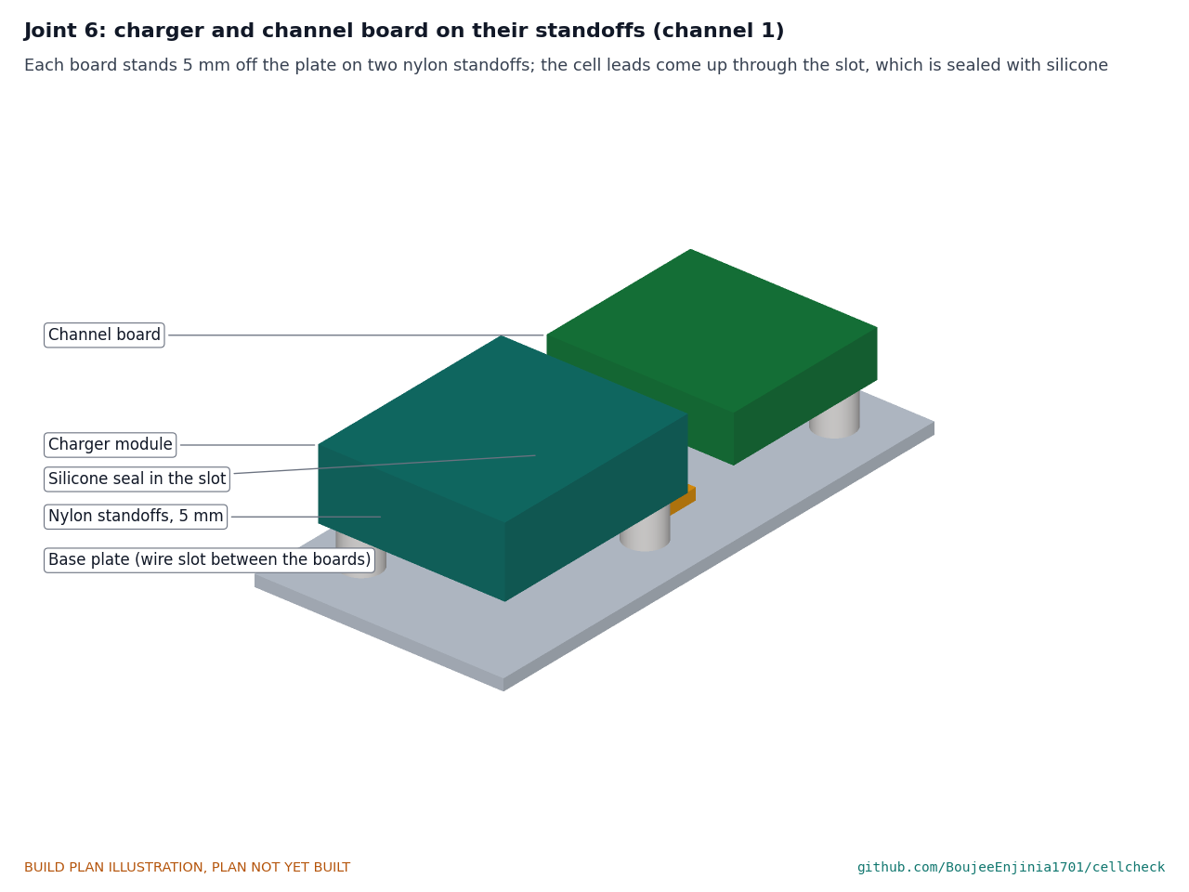
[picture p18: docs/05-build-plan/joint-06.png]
Figure 7. Joint 6: charger and channel board on their standoffs


*Figure 7. Each board stands 5 mm off the plate on two nylon standoffs; the cell leads come up through the slot between the two boards.*

**Check before moving on.** Lay a cell holder, a charger module and the heatsink on the plate and look through each hole: the holes must line up without forcing a screw. Both rivet nuts take an M4 screw.

### 3.4 Heatsink, drilled and tapped

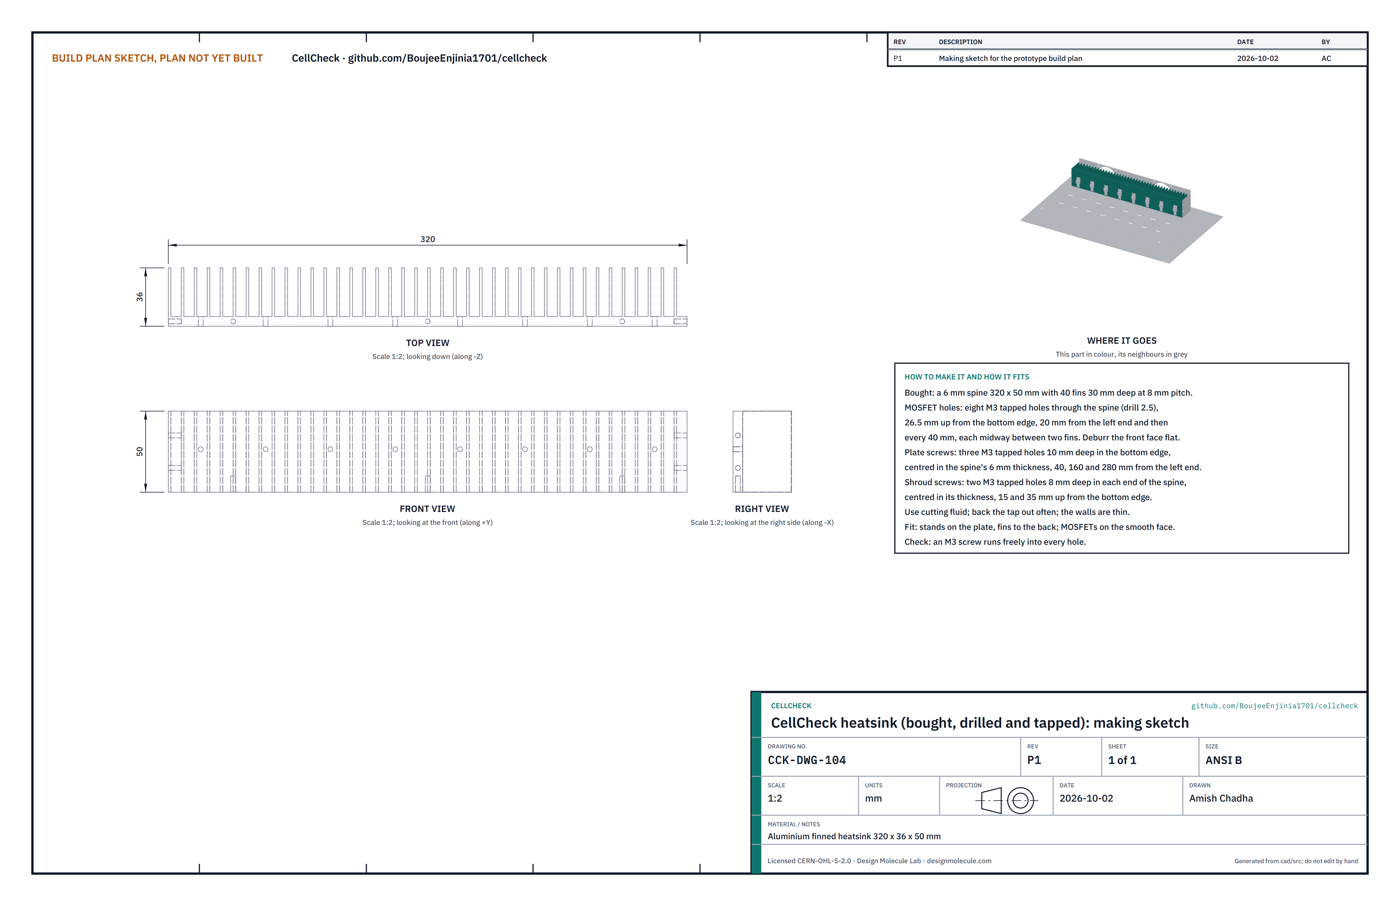
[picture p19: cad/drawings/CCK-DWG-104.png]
Figure 8. Making sketch of the heatsink


*Figure 8. Heatsink drilling sketch (CCK-DWG-104).*

**What it is and what it is made from.** The finned aluminium block that takes the heat from the eight load transistors. Bought: a 6 mm spine 320 long and 50 tall with 40 fins 30 deep at 8 mm pitch, worked with drill and tap.

**How to make it.**

1. Mark the smooth face of the spine (the front). Its bottom edge stands on the plate.
2. Transistor holes: eight on the front face, 26.5 up from the bottom edge, the first 20 from the left end and then every 40. Each must fall midway between two fins; check from the back before drilling. Drill 2.5 mm through the spine and tap M3.
3. Plate screw holes: three in the bottom edge, centred in the 6 mm thickness, 40, 160 and 280 from the left end. Drill 2.5 mm 10 deep and tap M3.
4. Shroud screw holes: two in each end of the spine, centred in its thickness, 15 and 35 up from the bottom edge. Drill 2.5 mm 8 deep and tap M3.
5. Use cutting fluid and back the tap out often; the walls round the bottom and end holes are under 2 mm.
6. Deburr the front face so it is flat for the transistor tabs.

**How it fits the parts next to it.**

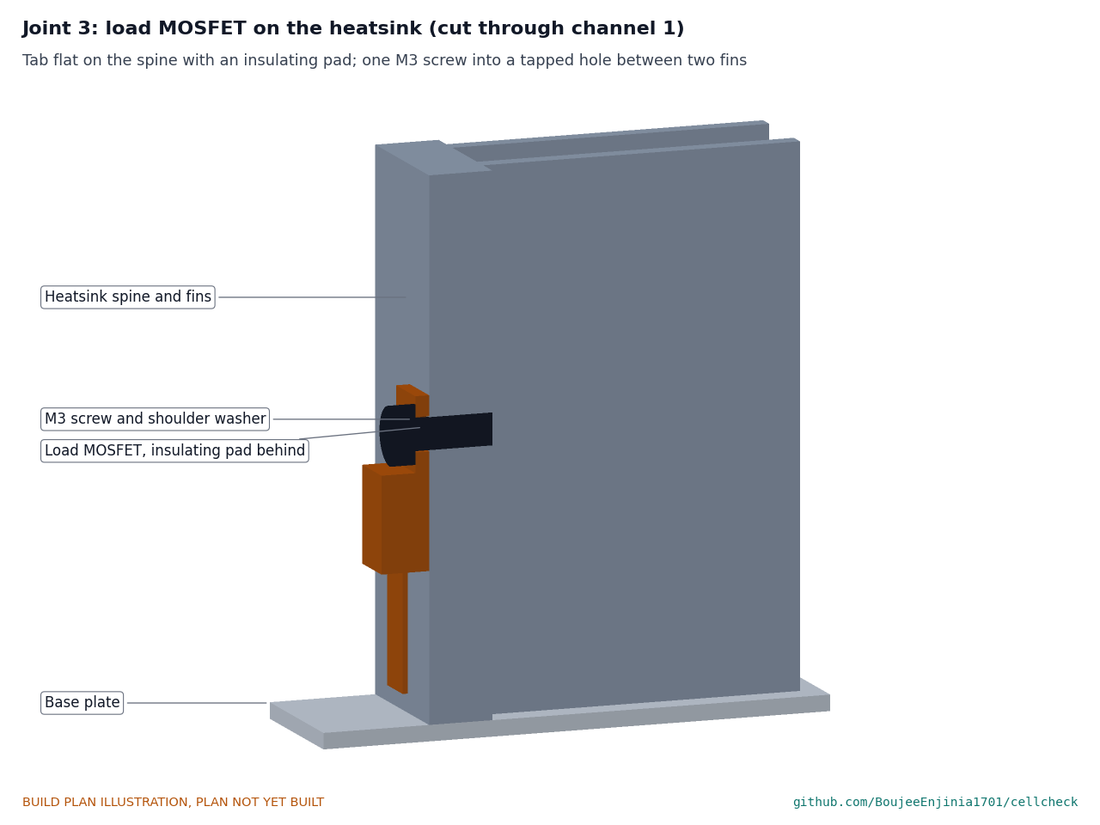
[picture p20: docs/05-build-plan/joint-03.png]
Figure 9. Joint 3: load transistor on the heatsink


*Figure 9. The transistor tab sits flat on the spine with an insulating pad behind it; one M3 screw with a shoulder washer goes into the tapped hole between two fins.*

The heatsink stands on the plate with its fins to the back, held by three M3 screws up from under the plate into its bottom edge. Each load transistor (a TO-220 MOSFET) is clamped to the front face over an insulating pad, so its tab does not connect to the heatsink.

**Check before moving on.** An M3 screw runs in freely by hand in every tapped hole.

### 3.5 Fan shroud

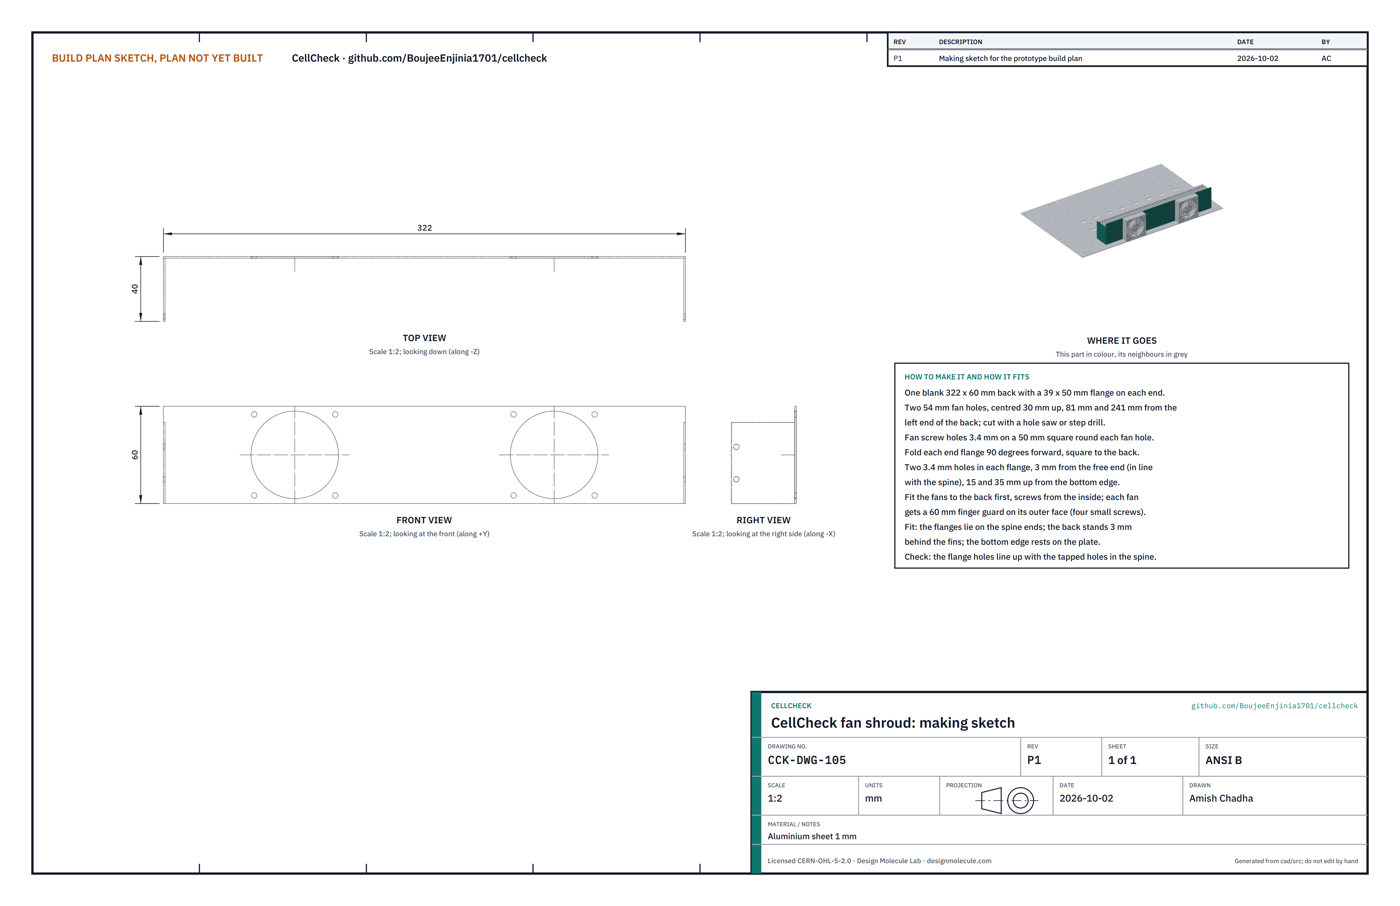
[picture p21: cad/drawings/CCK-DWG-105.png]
Figure 10. Making sketch of the fan shroud


*Figure 10. Fan shroud making sketch (CCK-DWG-105).*

**What it is and what it is made from.** The folded sheet behind the fins that carries the two fans and makes their air go forward through the fins and out of the top. Aluminium sheet 1 mm.

**How to make it.**

1. Mark one blank: a back 322 long and 60 tall, with a flange 39 wide and 50 tall on each end, level with the bottom edge.
2. Cut two 54 mm fan holes, centred 30 up and 81 and 241 from the left end of the back, with a hole saw or step drill.
3. Drill four 3.4 mm fan screw holes on a 50 mm square round each fan hole.
4. Drill two 3.4 mm holes in each flange, 3 from its free end and 15 and 35 up from the bottom edge.
5. Fold each flange 90° forward, square to the back. Deburr everything.
6. Screw each fan to the back with four fan screws put in from the inside, the fan blowing forward through the hole.
7. Fit a 60 mm steel wire finger guard on the outer face of each fan, held by four small self-tapping screws into the fan frame's corner holes.

**How it fits the parts next to it.**

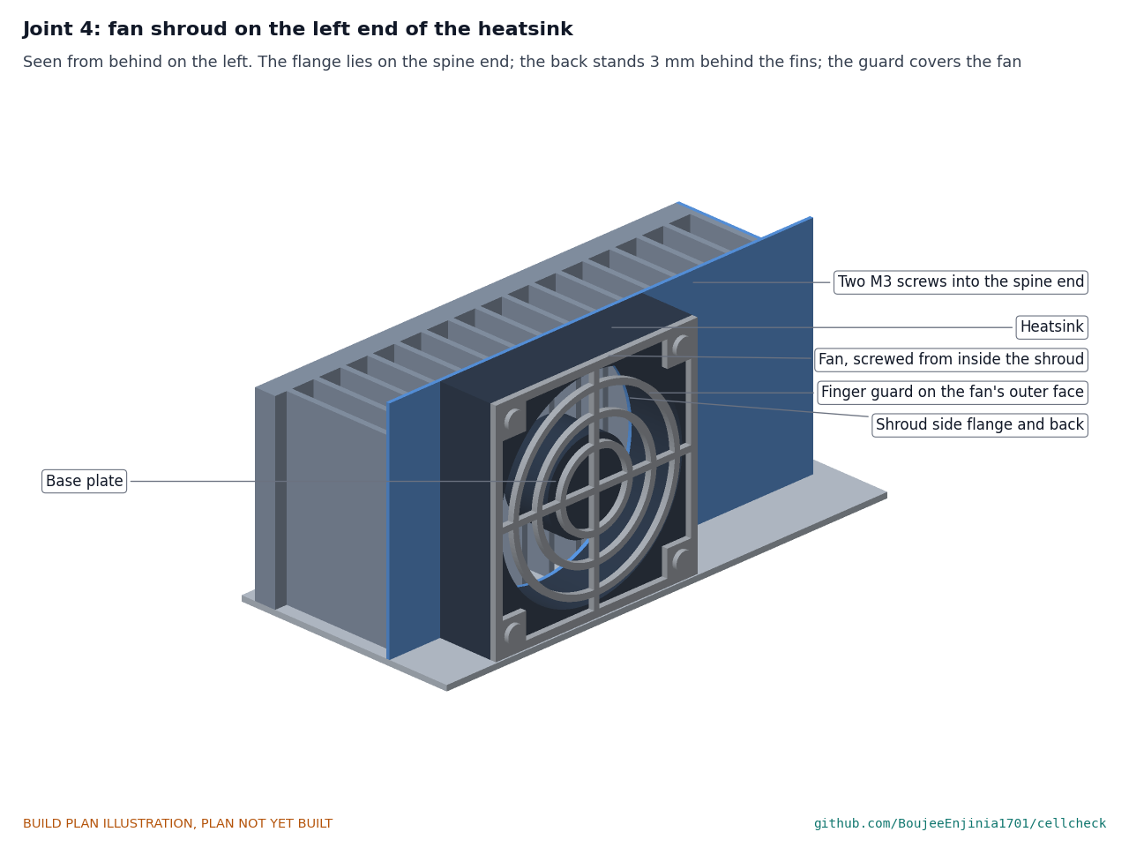
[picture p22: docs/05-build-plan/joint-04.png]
Figure 11. Joint 4: fan shroud on the left end of the heatsink


*Figure 11. The flange lies flat on the end of the spine and is held by two M3 screws; the back stands 3 mm behind the fins; the finger guard covers the fan's outer face.*

The flanges lie on the two ends of the spine, held by two M3 screws each; the back stands 3 mm behind the fins with its bottom edge resting on the plate, and the fans sit 15 mm in front of the tray's back wall, facing the intake slots, and their finger guards stand about 12 mm clear of the wall.

**Check before moving on.** Hold the shroud on the heatsink: the flange holes line up with the tapped holes in the spine ends.

### 3.6 Display stand

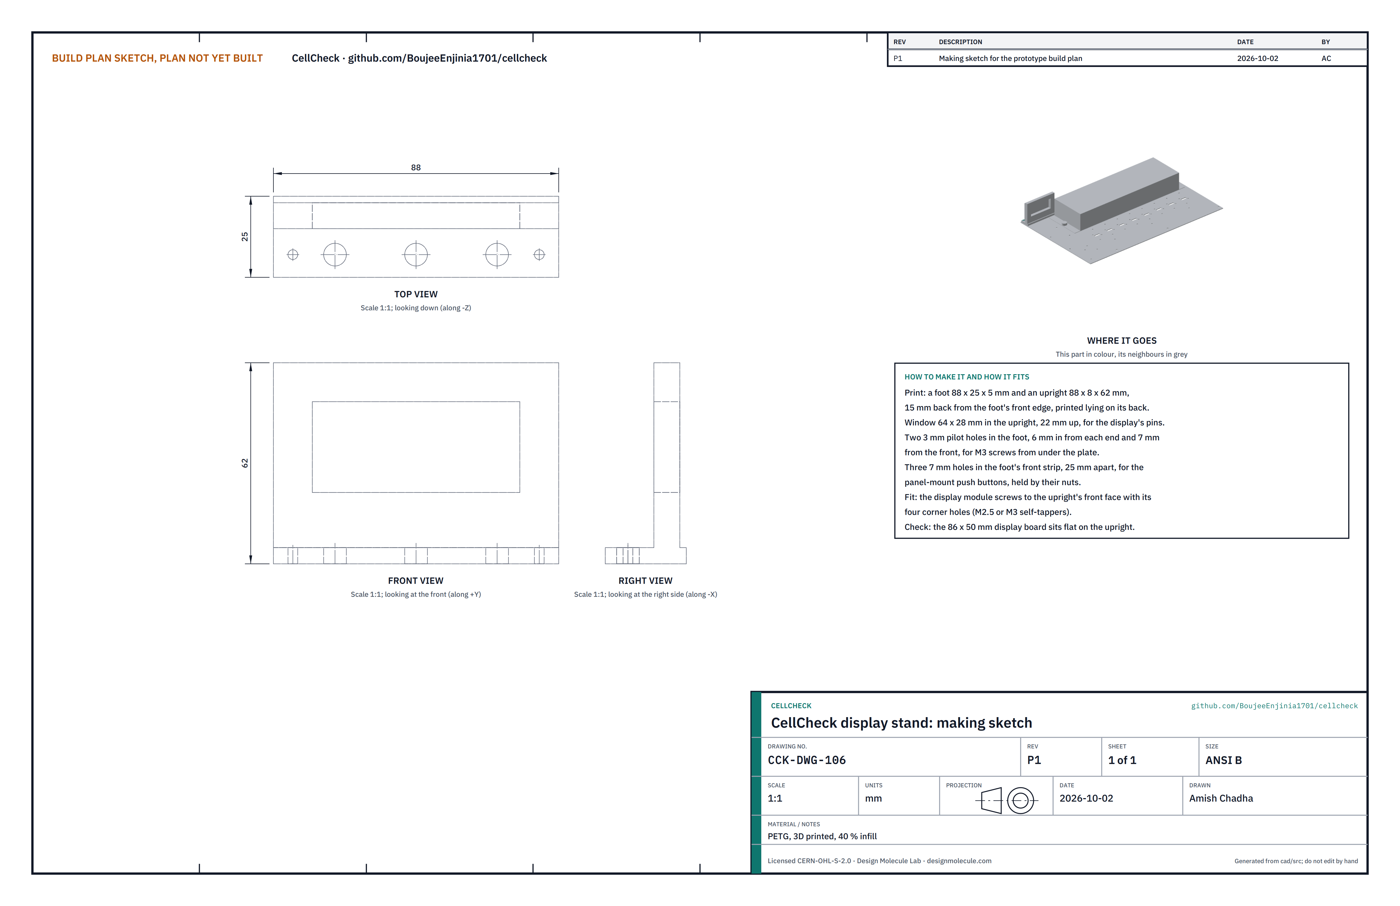
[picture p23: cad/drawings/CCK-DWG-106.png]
Figure 12. Making sketch of the display stand


*Figure 12. Display stand making sketch (CCK-DWG-106).*

**What it is and what it is made from.** A printed stand at the front right that holds the 2.8 in display module upright and the three push buttons in front of it. PETG, 40 % infill.

**How to make it.**

1. Print the stand lying on its back: a foot 88 x 25 x 5 and an upright 88 wide, 8 thick and 62 tall, standing 15 back from the foot's front edge.
2. The upright has a 64 x 28 window, 22 up, for the pins on the back of the display.
3. The foot has two 3 mm pilot holes, 6 in from each end and 7 from the front, and three 7 mm button holes on its front strip, 25 apart.
4. Fit the push buttons in their holes with their nuts, and screw the display module to the upright's front face through its four corner holes with M2.5 or M3 self-tapping screws.

**How it fits the parts next to it.** The foot stands on the plate in front of the guard's right flange, 3 clear of it, held by two M3 screws from under the plate.

**Check before moving on.** The 86 x 50 display board sits flat on the upright and the buttons click.

### 3.7 Inlet housing with jack, fuse holder and switch

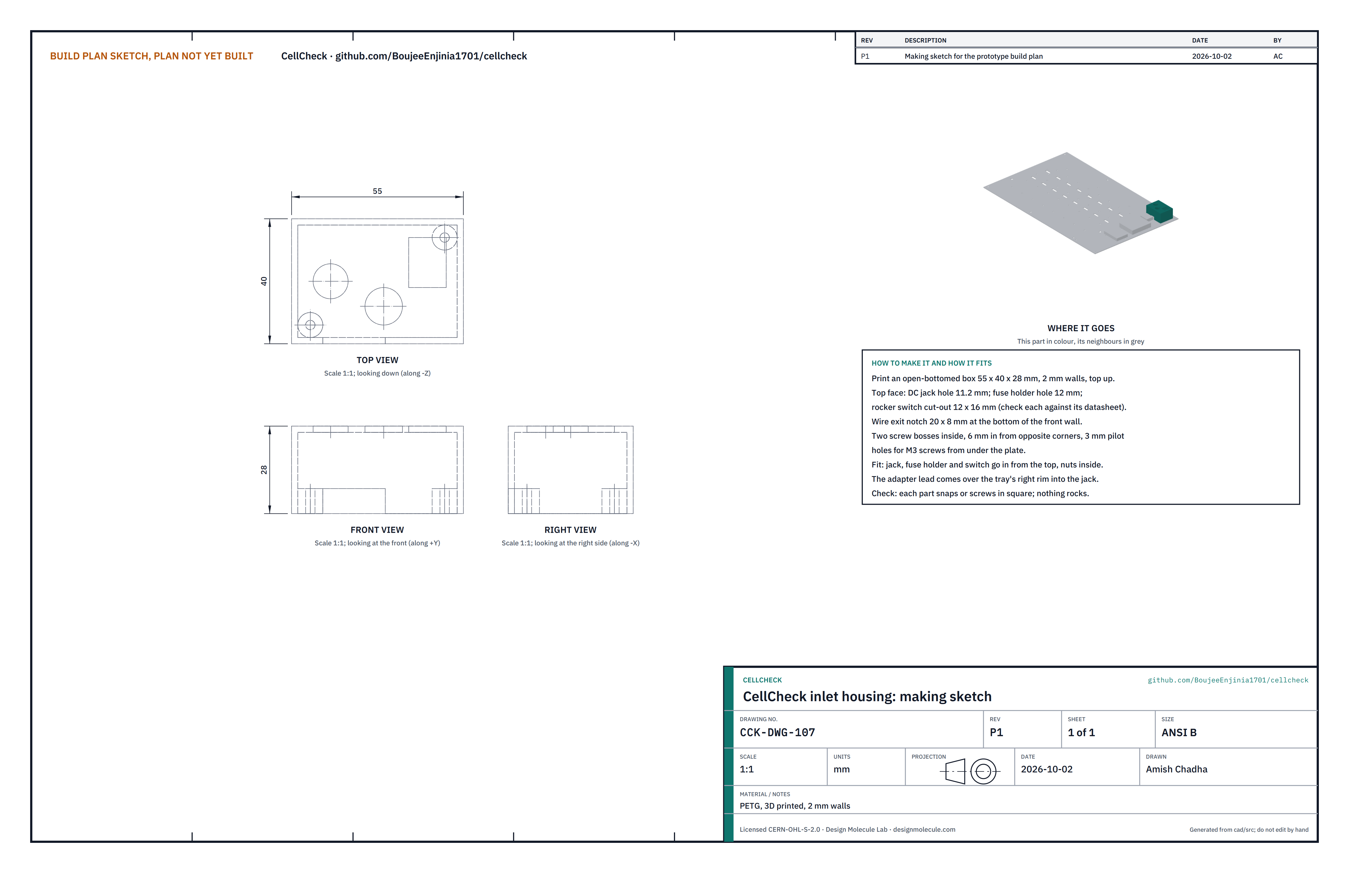
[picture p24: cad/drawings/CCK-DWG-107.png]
Figure 13. Making sketch of the inlet housing


*Figure 13. Inlet housing making sketch (CCK-DWG-107).*

**What it is and what it is made from.** A small printed box at the back right that holds the DC jack, the 6.3 A fuse holder and the rocker switch where the 12 V supply comes in. PETG, 2 mm walls.

**How to make it.**

1. Print an open-bottomed box 55 x 40 x 28 with its top face up.
2. In the top face: an 11.2 mm hole for the jack, a 12 mm hole for the fuse holder and a 12 x 16 cut-out for the switch. Check each size against the part's datasheet before printing.
3. A 20 x 8 notch at the bottom of the front wall for the wires, and two screw bosses inside, 6 in from opposite corners, with 3 mm pilot holes.
4. Fit the jack, fuse holder and switch from the top with their nuts inside, and solder their wires before the housing goes on the plate.

**How it fits the parts next to it.**

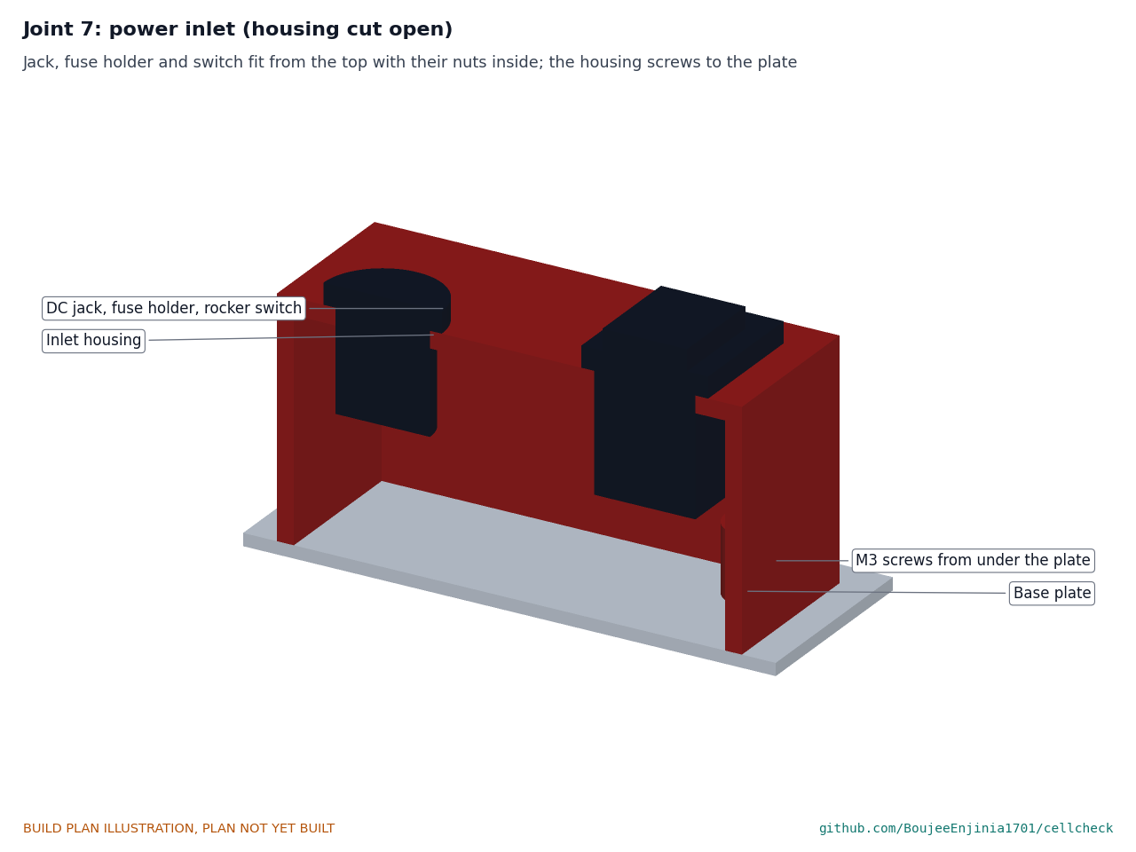
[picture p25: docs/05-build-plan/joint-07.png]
Figure 14. Joint 7: power inlet, cut open


*Figure 14. The jack, fuse holder and switch fit from the top with their nuts inside; the housing screws to the plate from below.*

The housing stands on the plate at the back right, held by two M3 screws from under the plate into its bosses. The adapter's lead comes over the tray's right rim and plugs into the jack from above.

**Check before moving on.** Each part sits square and tight; nothing rocks.

### 3.8 Perforated guard

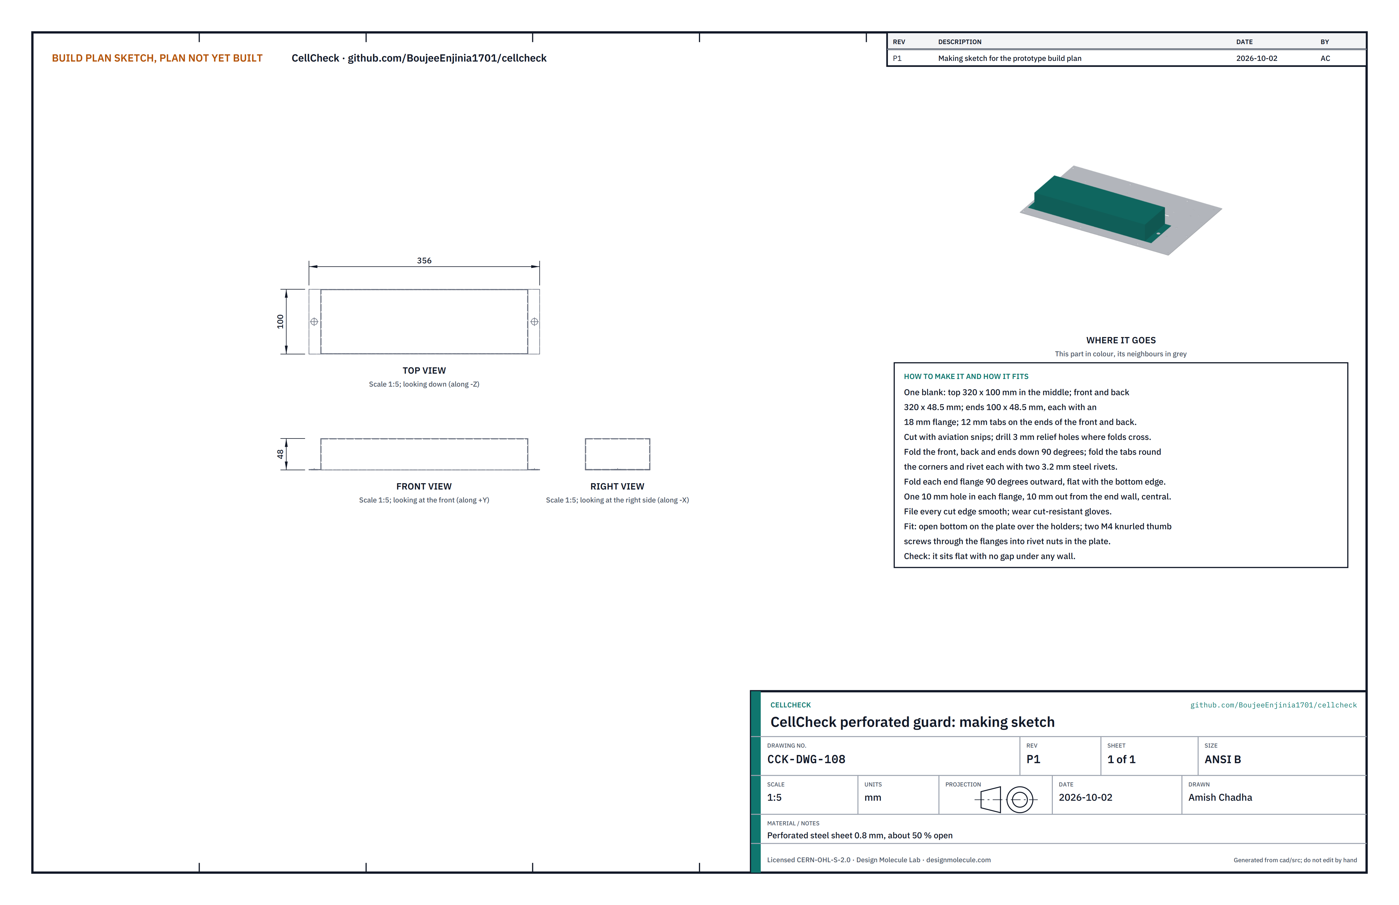
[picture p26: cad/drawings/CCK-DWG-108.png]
Figure 15. Making sketch of the guard


*Figure 15. Guard making sketch (CCK-DWG-108).*

**What it is and what it is made from.** The open-bottomed steel cover over the eight cells. It stops loose debris from a venting cell while letting the cells be seen and cooled, and it lifts off to change cells. Perforated steel sheet 0.8 mm, about 50 % open.

**How to make it.**

1. Mark one blank: a top 320 x 100 in the middle; a front and a back each 320 x 48.5 on the long edges; an end 100 x 48.5 on each short edge, each with an 18 mm flange beyond it; and a 12 mm tab on each end of the front and the back.
2. Cut with aviation snips and drill a 3 mm relief hole wherever two fold lines cross.
3. Fold the front, back and ends down 90°. Fold the tabs round the corners and rivet each with two 3.2 mm steel rivets.
4. Fold each end flange 90° outward, level with the bottom edge.
5. Drill a 10 mm hole in each flange, 10 out from the end wall and midway along it.
6. File every cut edge smooth.

**How it fits the parts next to it.**

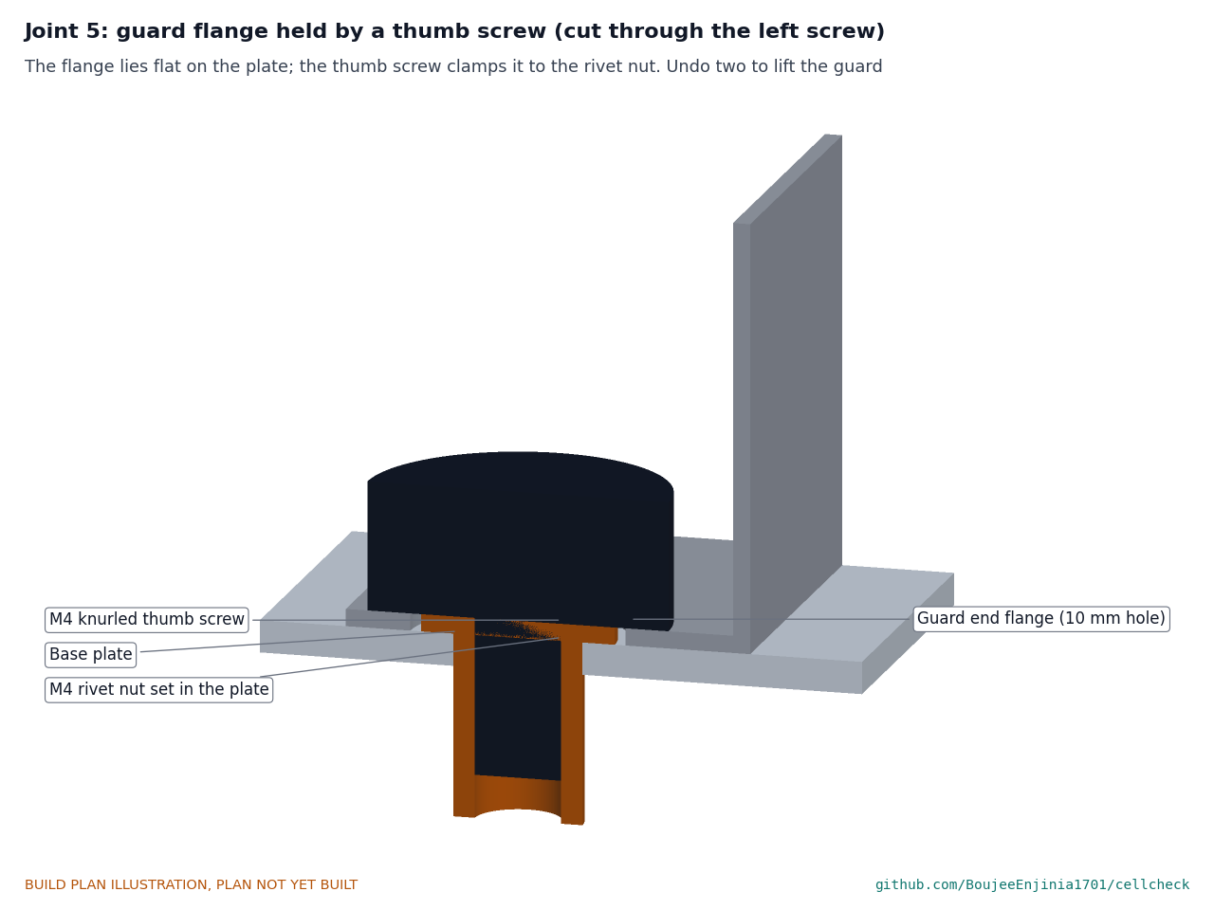
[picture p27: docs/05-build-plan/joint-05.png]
Figure 16. Joint 5: guard flange held by a thumb screw


*Figure 16. The flange lies flat on the plate round the rivet nut; an M4 knurled thumb screw clamps it.*

The open bottom stands on the plate over the holders, 6 or more clear of them on every side and 12 above the thermistor clips. Each flange lies flat on the plate round a rivet nut and is held by one M4 knurled thumb screw with a 14 mm head. To change cells, undo the two thumb screws and lift the guard straight up.

**Check before moving on.** It sits flat on the plate with no gap under any wall.

### 3.9 Thermistor clips (print 8 for 21700 and 8 for 18650)

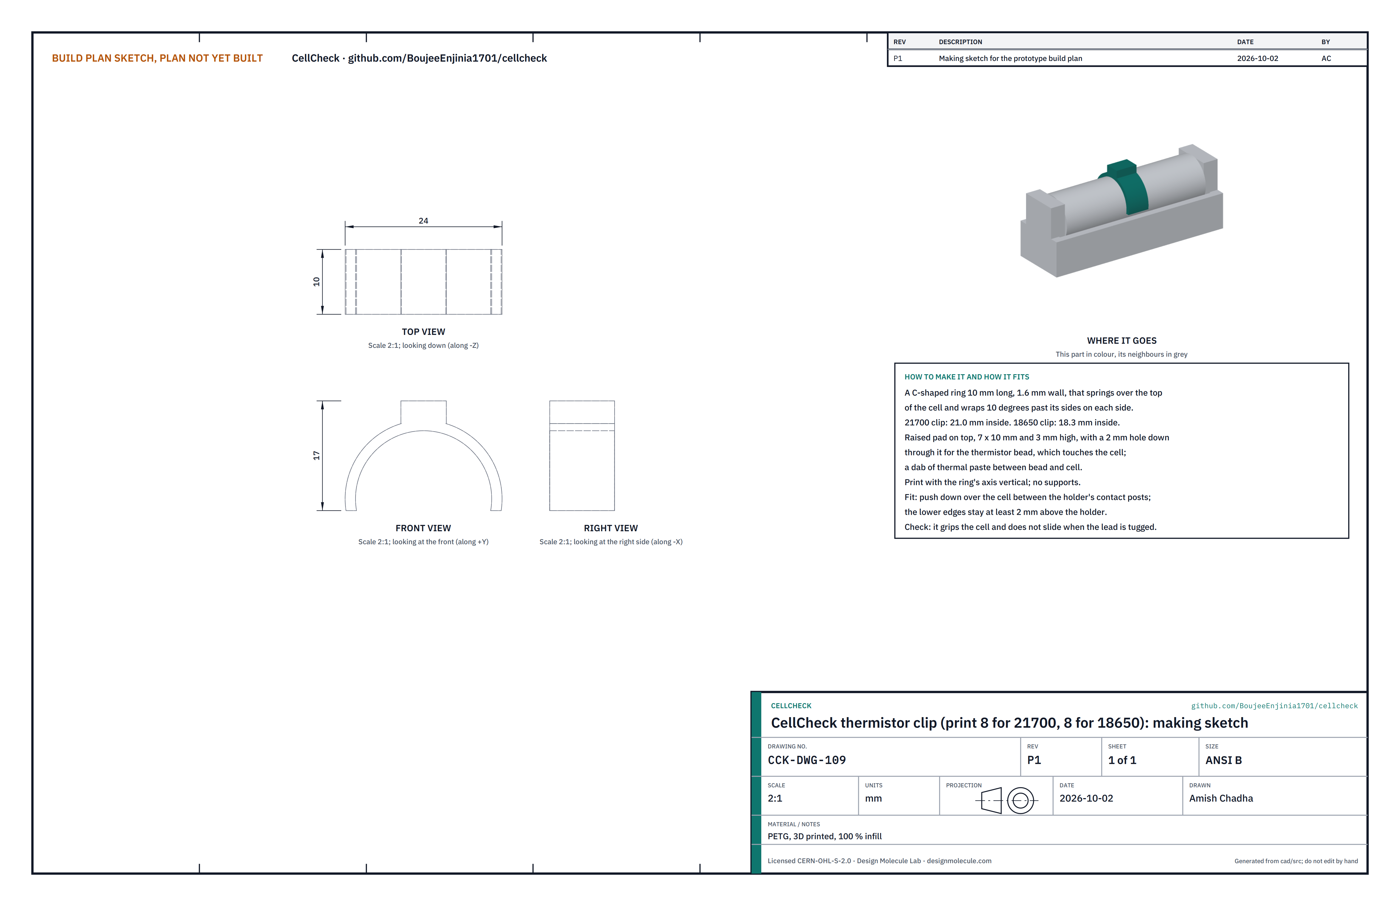
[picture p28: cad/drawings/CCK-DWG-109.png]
Figure 17. Making sketch of the thermistor clip


*Figure 17. Thermistor clip making sketch (CCK-DWG-109).*

**What it is and what it is made from.** A printed spring clip that holds each channel's temperature sensor against its cell. PETG, 100 % infill.

**How to make it.**

1. Print a C-shaped ring 10 long with a 1.6 mm wall, wrapping 10° past the cell's sides on each side: 21.0 inside for 21700 cells and 18.3 inside for 18650 cells. Print with the ring's axis upright, no supports.
2. On top, a raised pad 7 x 10 and 3 high with a 2 mm hole down through it.
3. Push the thermistor bead into the hole until it stands just proud of the inside face, with a dab of thermal paste, and glue its lead to the pad.

**How it fits the parts next to it.**

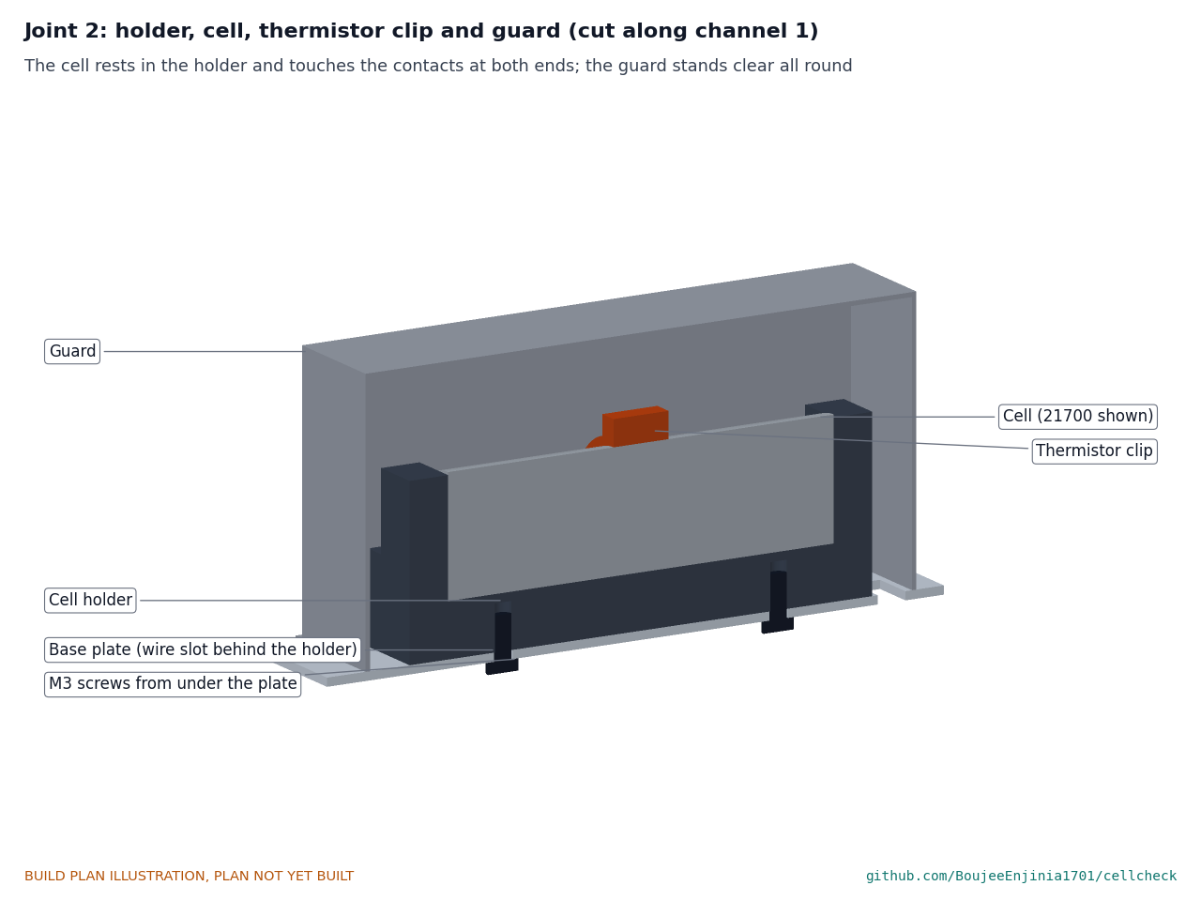
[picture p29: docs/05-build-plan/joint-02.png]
Figure 18. Joint 2: holder, cell, thermistor clip and guard, cut along channel 1


*Figure 18. The cell rests in the holder and touches the contacts at both ends; the clip springs over the middle of the cell; the guard stands clear all round.*

The cell rests in the holder's groove and touches its force and sense contacts at both ends. The clip pushes down over the middle of the cell between the contact posts; its lower edges stay at least 2 above the holder. Its lead runs down into the wire slot behind the holder.

**Check before moving on.** On a spare cell the clip grips and does not slide when its lead is tugged.

### 3.10 Rest rack

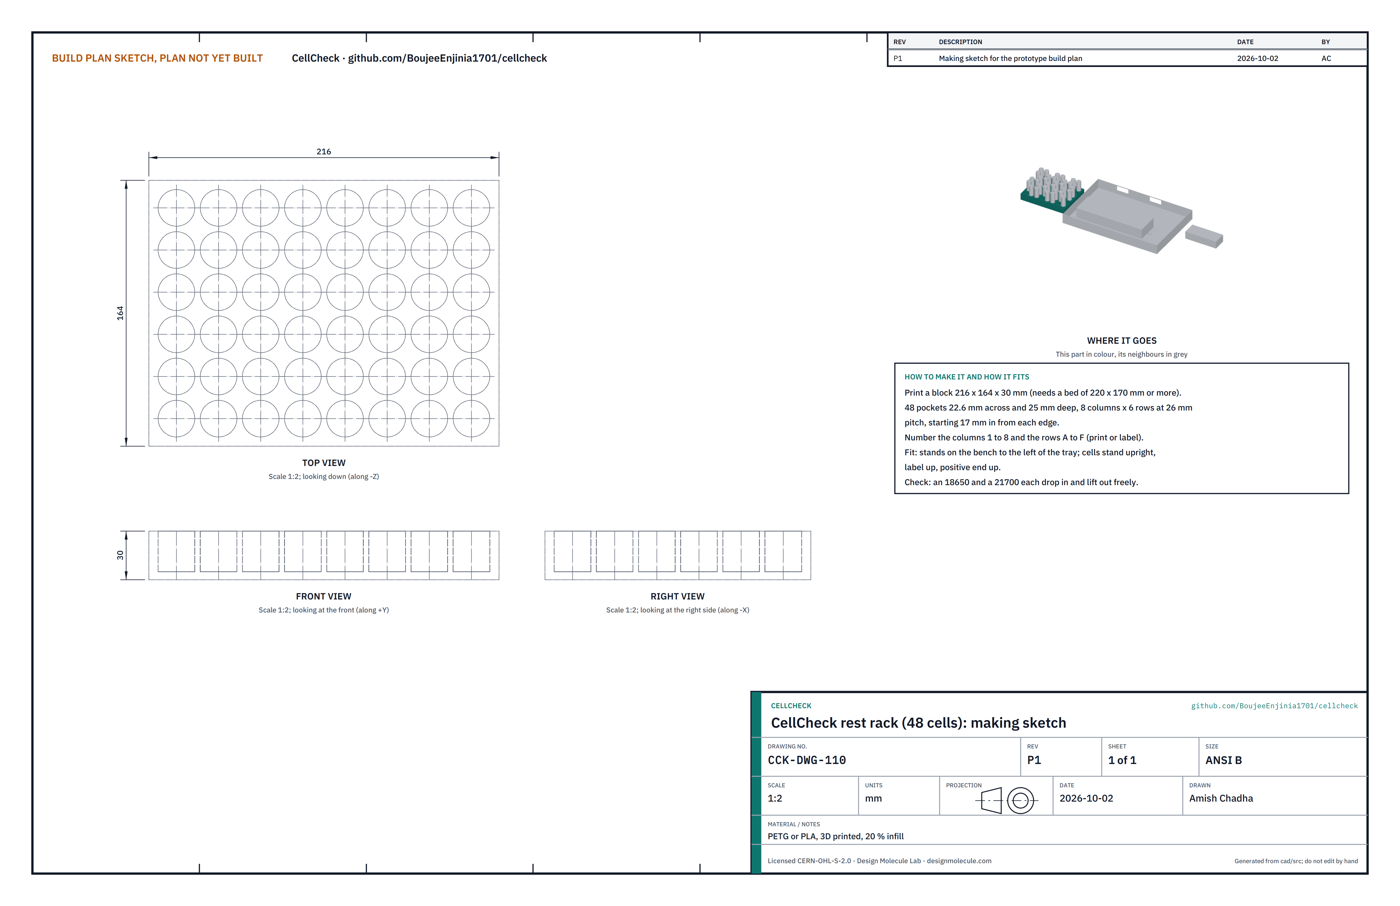
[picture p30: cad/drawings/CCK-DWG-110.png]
Figure 19. Making sketch of the rest rack


*Figure 19. Rest rack making sketch (CCK-DWG-110).*

**What it is and what it is made from.** A printed block that holds 48 cells upright and numbered during their 14-day rest. PETG or PLA, 20 % infill.

**How to make it.**

1. Print a block 216 x 164 x 30 on a bed of at least 220 x 170.
2. 48 pockets 22.6 across and 25 deep, 8 columns by 6 rows at 26 pitch, the first 17 in from each edge.
3. Number the columns 1 to 8 and the rows A to F.

**How it fits the parts next to it.** It stands on the bench to the left of the tray. Cells stand in it upright, label up, positive end up, with no current flowing.

**Check before moving on.** An 18650 and a 21700 each drop in and lift out freely.

### 3.11 Wiring

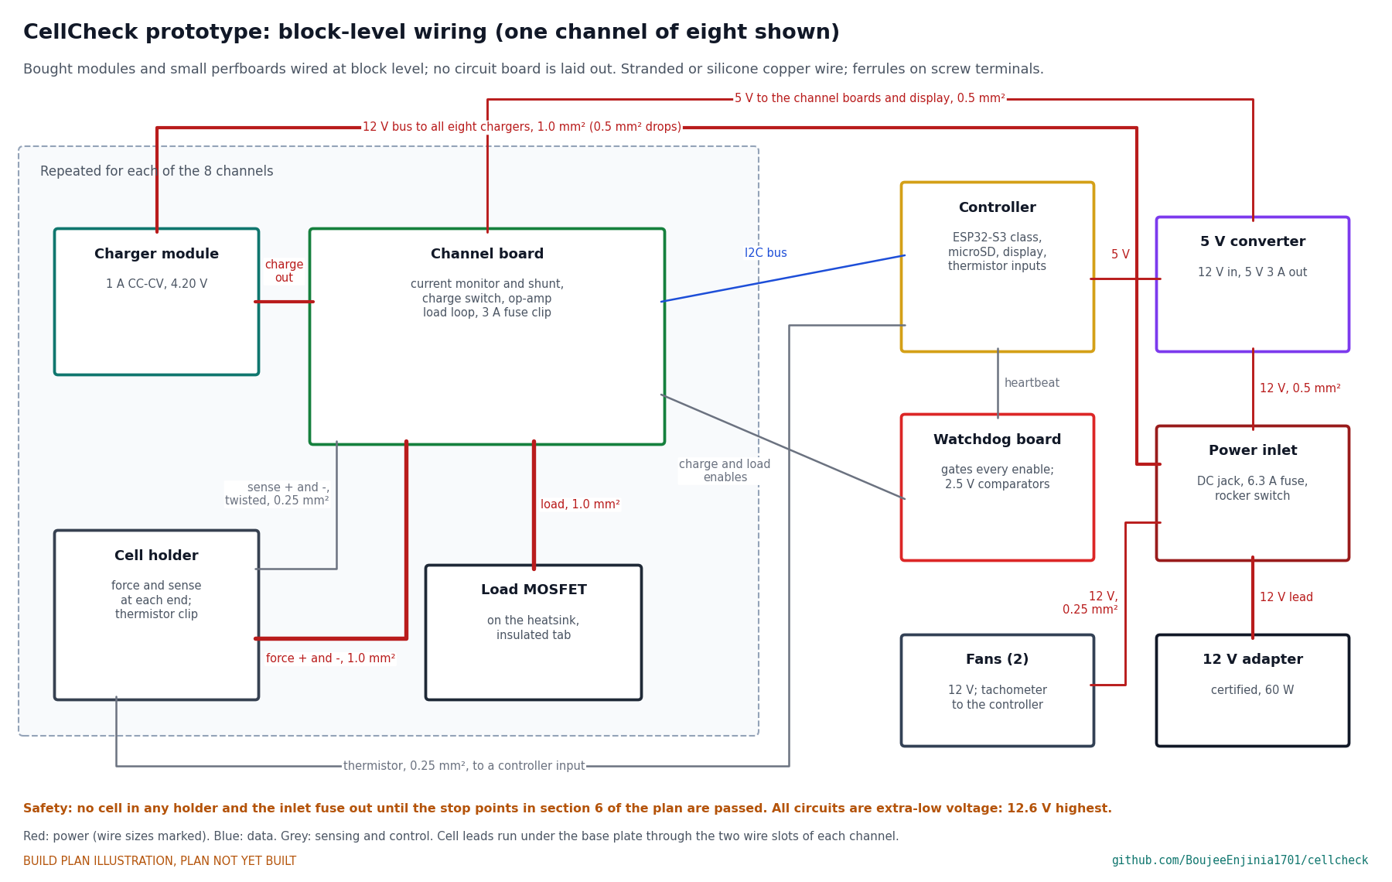
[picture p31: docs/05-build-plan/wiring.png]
Figure 20. Block-level wiring


*Figure 20. Block-level wiring with wire sizes, one channel of eight shown. No circuit board is laid out at this stage; bought modules and small perfboards stand in.*

The channel board in the bill of materials is not a custom board, which would be TRL 4 work. For this prototype, buy modules that meet this specification:

*Table 2. Modules and perfboards.*

| Module | What to buy or make |
| --- | --- |
| Charger | Single-cell lithium-ion constant-current, constant-voltage buck charger, 1 A, 4.20 V within 1 %, 12 V input (TP5100 class), with mounting holes |
| Channel board | A current and voltage monitor breakout (INA226 class) with its shunt changed to 25 mΩ 0.5 %, on a small perfboard that also carries the series charge switch transistor, the op-amp of the load loop, its sense resistor and fuse clips for a 3 A fast fuse; each board with its own bus address |
| Load transistor | Logic-level MOSFET in TO-220 with an insulating pad and shoulder washer |
| Watchdog board | Perfboard with a hardware watchdog timer that removes every charge and load enable if the controller stops, and eight 2.5 V comparators that remove each load's drive |
| Controller | ESP32-S3 class board with a microSD slot |
| 5 V converter | Buck converter, 12 V in, 5 V 3 A out, with mounting holes |

Wire it like this, with silicone or stranded copper wire, soldered or crimped joints, and heat-shrink on every bare joint:

1. Jack to fuse holder to switch to the 12 V bus: 1.0 mm² (18 AWG).
2. 12 V bus to each charger input: 1.0 mm² for the bus, 0.5 mm² (20 AWG) for each drop. 12 V to each fan and to the converter: 0.25 mm² (24 AWG) and 0.5 mm².
3. Converter 5 V output to the controller, display and every channel board: 0.5 mm².
4. Each charger's output to its channel board (charge switch, shunt and fuse in series): 1.0 mm².
5. Channel board to the cell holder, positive and negative force leads: 1.0 mm², down through the slot behind the holder and up through the slot beside the channel board. The positive lead goes through the 3 A fuse on the channel board.
6. Each holder's two sense leads to its channel board: 0.25 mm², twisted, along the same path.
7. Channel board to its load transistor's drain, source and gate: 1.0 mm² for drain and source, 0.25 mm² for the gate.
8. Thermistor leads from each clip, down the same slot, to a controller input: 0.25 mm².
9. Controller to every channel board on one I2C bus; controller heartbeat to the watchdog board; watchdog board to every charge and load enable: 0.25 mm².
10. Fan tachometer leads to the controller: 0.25 mm².

**Check before moving on.** Every wire continues end to end; the inlet fuse is out; no lead is pinched at a slot; every wire is labelled with its channel.

### 3.12 Bought components

Buy to specification, not brand. Line numbers are those of the bill of materials.

- **Cell holders (line 3).** Eight adjustable holders for 18650 and 21700 cells up to 70 mm long, spring contacts with separate force and sense leads at each end, and two M3 fixing holes in the base.
- **Thermistors (line 4).** Eight 10 kΩ 1 % NTC thermistors, B value 3950.
- **Charger modules, channel boards, load transistors (lines 6 to 8), controller (line 11), watchdog board (line 18), 5 V converter (line 21).** As Table 2.
- **Fans (line 10).** Two 60 mm 12 V fans with a tachometer lead and a 50 mm screw pattern, each with a 60 mm finger guard.
- **Display and buttons (line 12).** A 2.8 in SPI display module about 86 x 50 mm with four corner holes, and three panel-mount push buttons for 7 mm holes.
- **Inlet parts (line 13).** Panel-mount DC jack to suit the adapter's plug, panel fuse holder with a 6.3 A fuse, rocker switch for a 12 x 16 cut-out.
- **Adapter (line 14).** A certified 12 V 5 A (60 W) adapter with the safety marks of the country of use. Never a bare or uncertified supply.
- **Wiring (line 16).** Silicone wire as section 3.11, eight 3 A fast fuses, connectors, heat-shrink, edge grommet strip and a tube of high-temperature silicone sealant for the wire slots.
- **Labels (line 17).** Cell ID labels, insulator rings and wraps.
- **Rubber feet (line 19).** Six rubber feet about 20 across and 8 tall with M4 x 8 steel studs.
- **Fixings (line 20).** Stainless: 6 M4 x 12 hex standoffs (line 2); 6 M4 x 8 screws (plate); 16 M3 x 8 screws (holders); 3 M3 x 10 screws (heatsink); 8 M3 x 10 screws with shoulder washers (transistors); 4 M3 x 6 screws (shroud); 8 fan screws; 38 M3 x 8 screws and 38 5 mm nylon standoffs (boards); 4 M3 x 8 screws (display stand and inlet); 2 M4 blind rivet nuts for 0.5 to 3 mm sheet; 2 M4 x 10 knurled thumb screws with 14 mm heads; 16 3.2 mm steel rivets (guard).

## 4. Putting it together

In each picture the parts already fitted are grey and the part being fitted is in colour, with an arrow showing the way it goes in. Build the plate assembly (steps 3 to 9) on the bench, then lower it into the tray.

### Step 1: feet and standoffs onto the tray

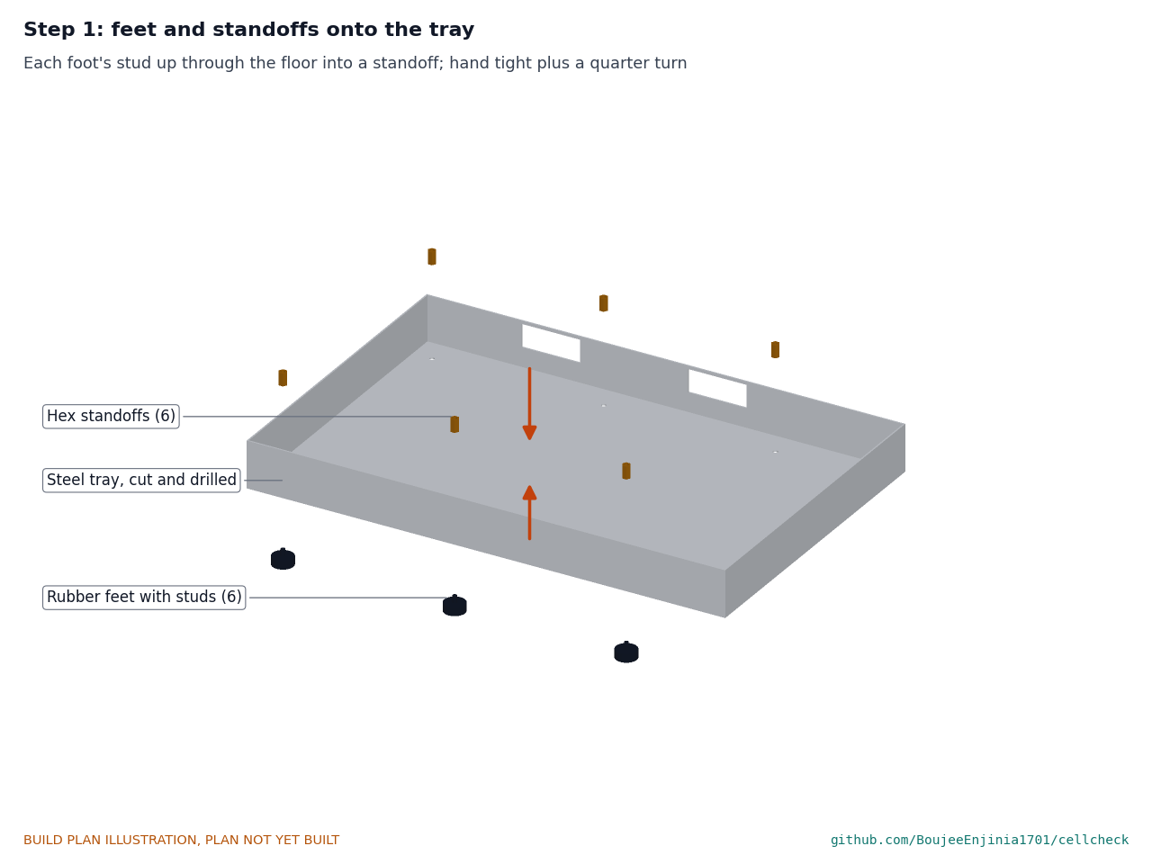
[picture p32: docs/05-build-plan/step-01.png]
Step 1


Put each foot's stud up through its hole in the floor and screw a hex standoff onto it from inside; hand tight plus a quarter turn.

### Step 2: liner into the tray

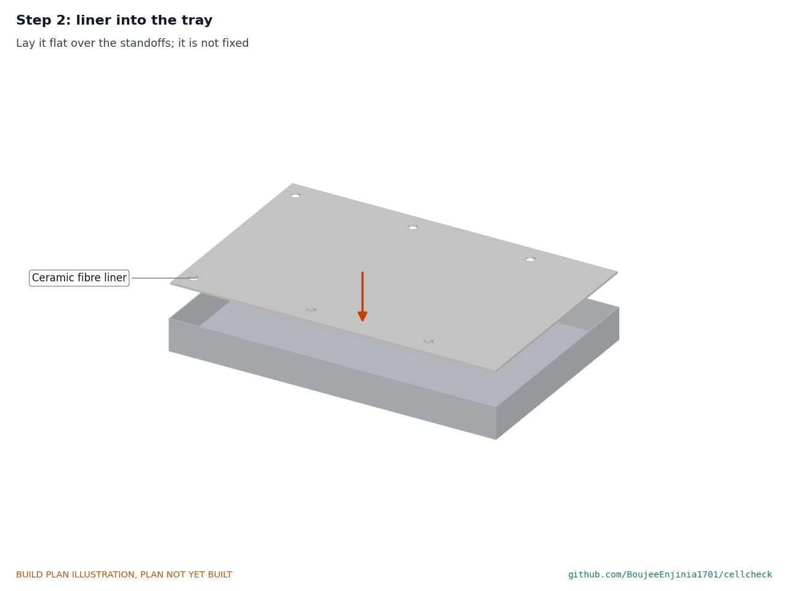
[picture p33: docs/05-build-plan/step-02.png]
Step 2


Lay the liner flat on the floor with a standoff through each of its holes. It is not fixed.

### Step 3: cell holders and rivet nuts onto the base plate

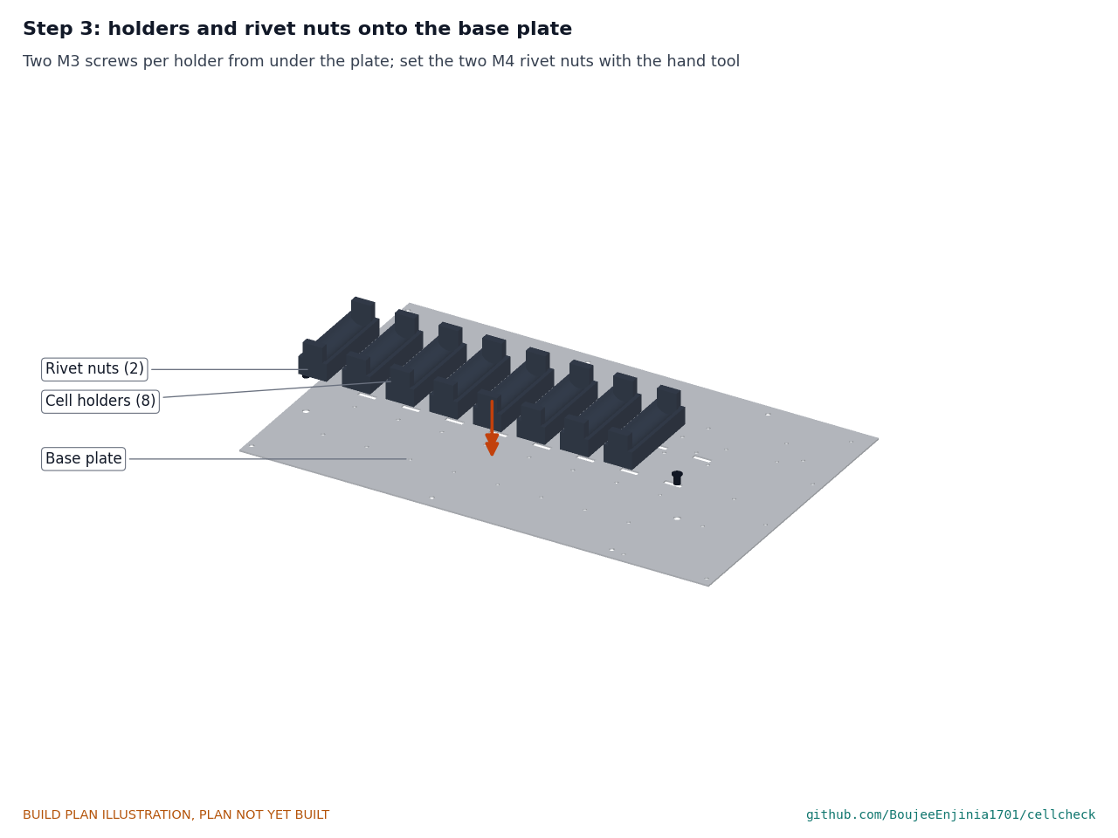
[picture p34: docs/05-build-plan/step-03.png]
Step 3


Each holder on its two screw holes, two M3 screws from under the plate, snug. The rivet nuts are already set (section 3.3).

### Step 4: chargers and channel boards onto the plate

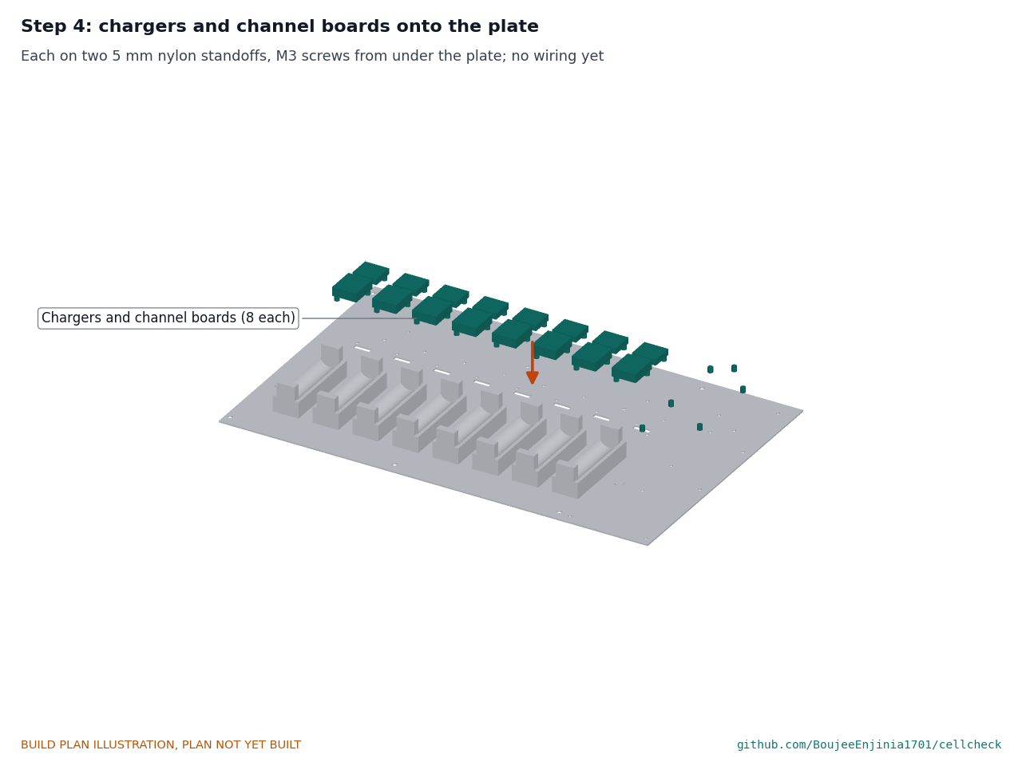
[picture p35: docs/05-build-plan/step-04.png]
Step 4


Each board on two 5 mm nylon standoffs, M3 screws from under the plate. No wiring yet.

### Step 5: load transistors onto the heatsink

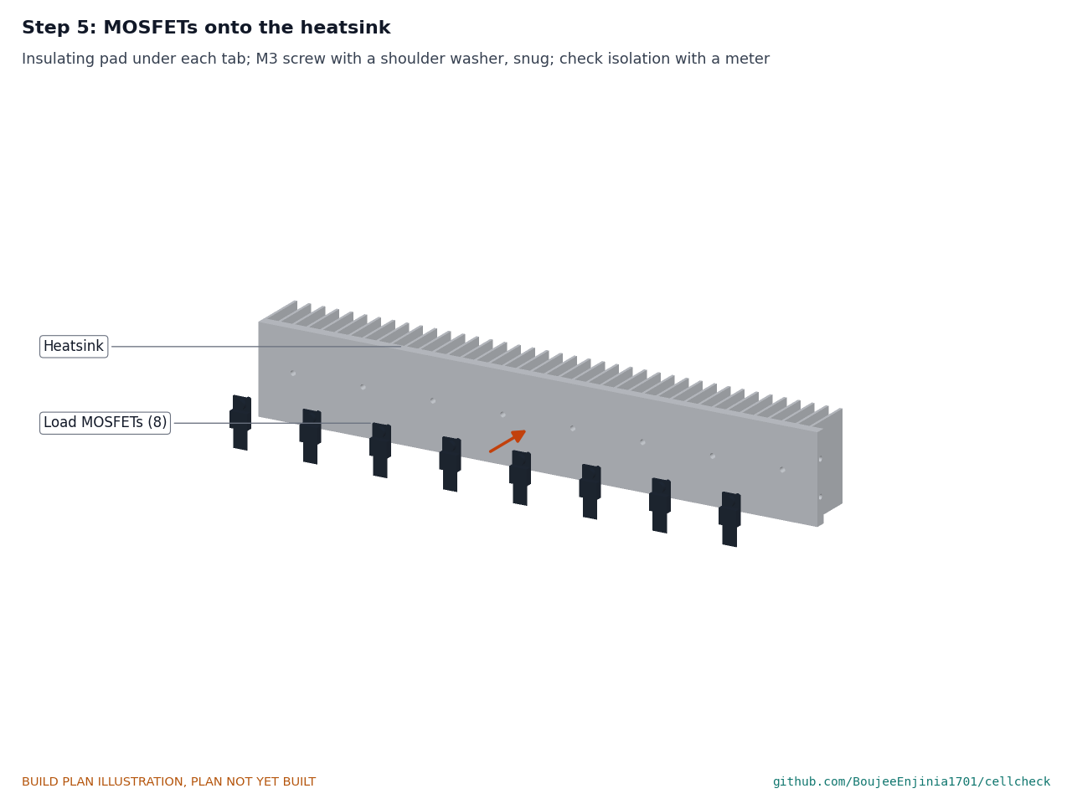
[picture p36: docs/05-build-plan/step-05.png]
Step 5


Insulating pad under each tab, M3 screw with a shoulder washer, snug. **Hold point:** with a meter on its resistance range, every tab reads open to the heatsink.

### Step 6: heatsink onto the plate

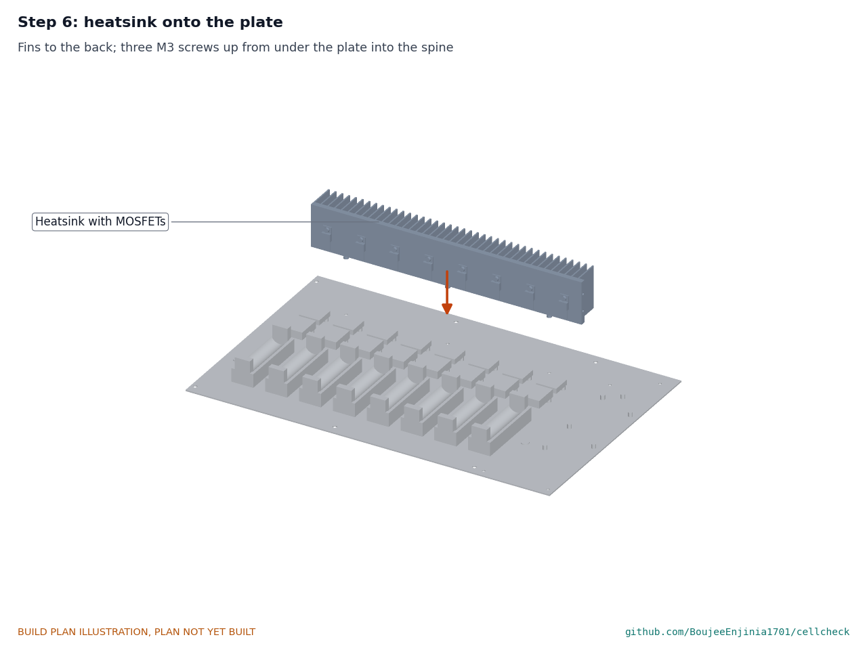
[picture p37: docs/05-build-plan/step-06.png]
Step 6


Fins to the back. Three M3 screws up from under the plate into the spine's bottom edge.

### Step 7: fan shroud and fans onto the heatsink

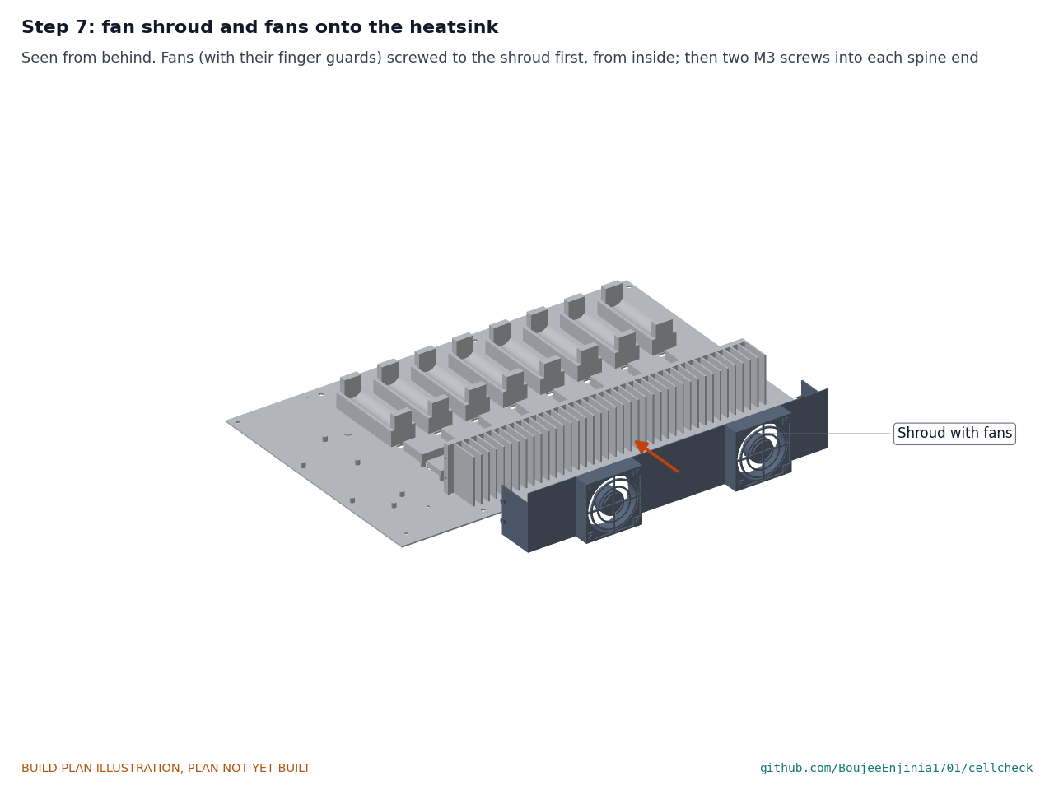
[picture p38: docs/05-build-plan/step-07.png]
Step 7


With the fans (and their finger guards) already screwed to the shroud, slide its flanges over the spine ends and fit two M3 screws each side.

### Step 8: controller, watchdog board, converter, display and inlet

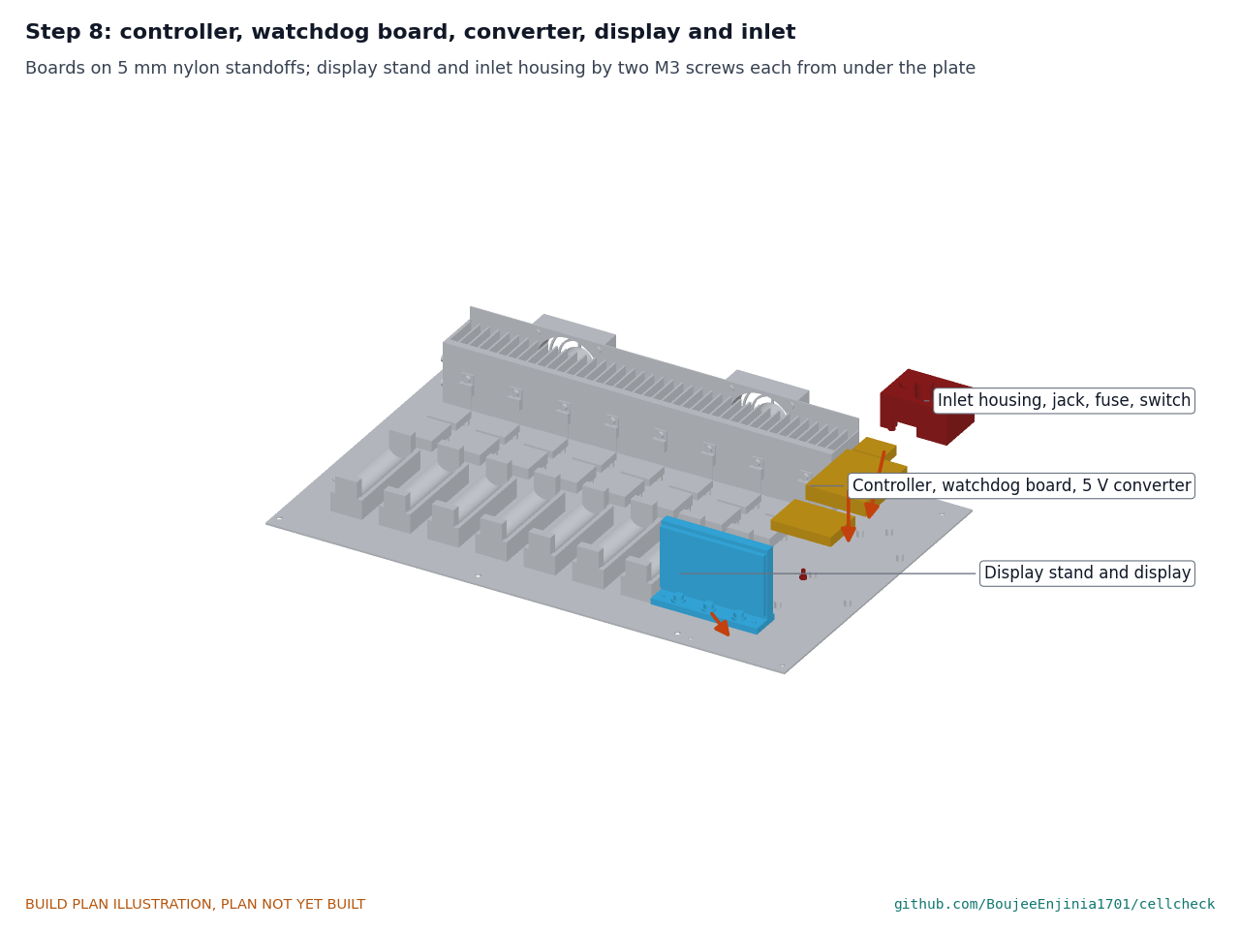
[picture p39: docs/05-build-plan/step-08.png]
Step 8


Controller, watchdog board and converter on 5 mm nylon standoffs; display stand and inlet housing by two M3 screws each from under the plate.

### Step 9: wiring and sealing the wire slots

Step 9, wiring

Wire the plate as section 3.11 and Figure 20, with the inlet fuse out and no cell anywhere near. Run the cell leads down the slot behind each holder, along the underside of the plate and up the slot beside the channel board. **Hold point:** the wiring checks of section 3.11 pass. Then fill each wire slot round its leads with high-temperature silicone, from above and below, and let it cure before step 10; this closes the space under the guard again. The next picture shows the 16 sealed slots.

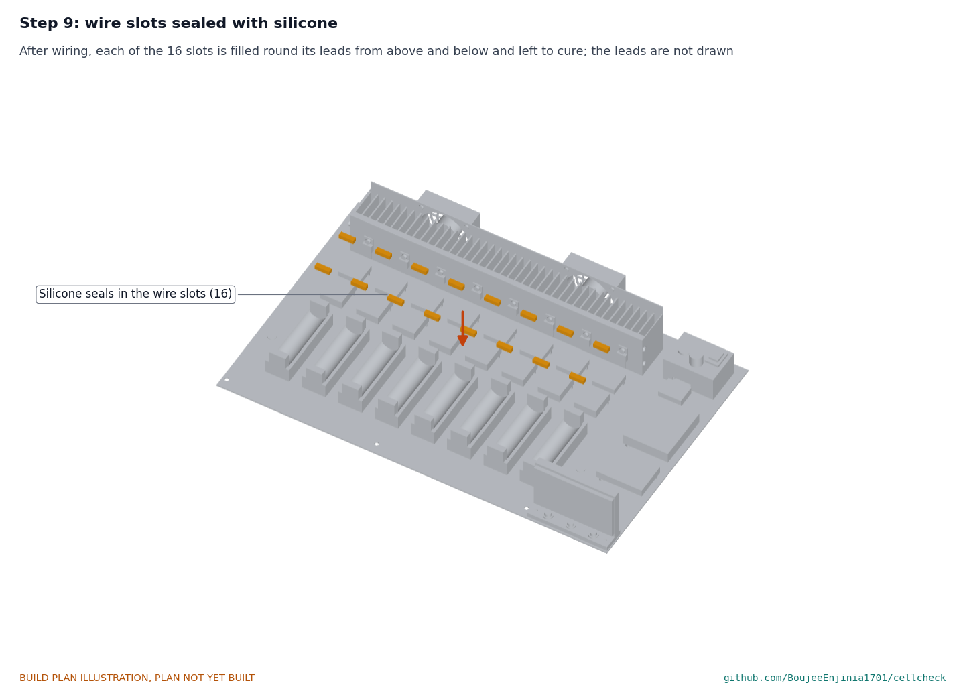
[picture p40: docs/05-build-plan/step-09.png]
Step 9, sealed slots


### Step 10: plate assembly into the tray

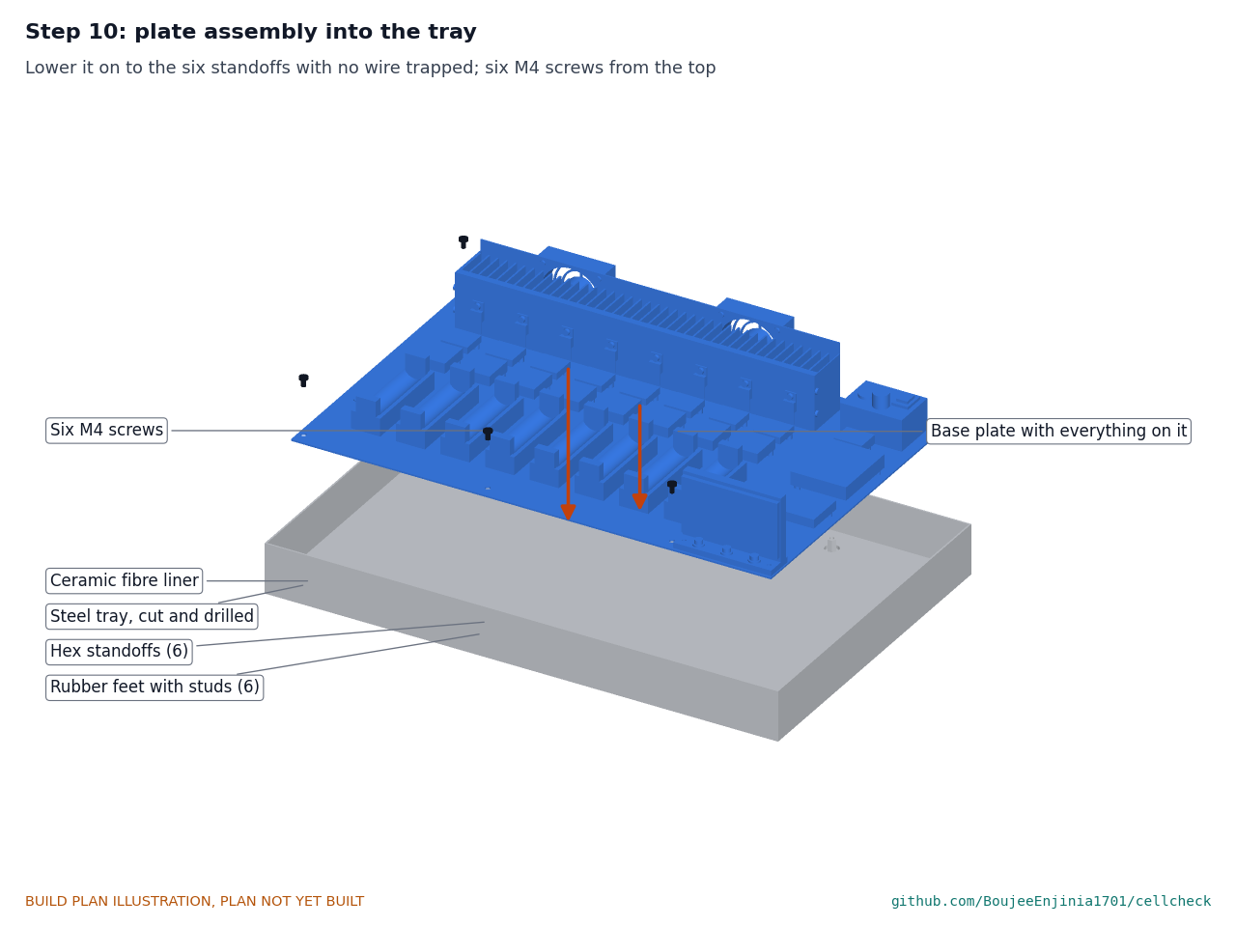
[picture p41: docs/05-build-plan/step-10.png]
Step 10


Lower the plate onto the six standoffs, checking that no lead under it is trapped. Six M4 screws from the top.

### Step 11: guard over the cell holders

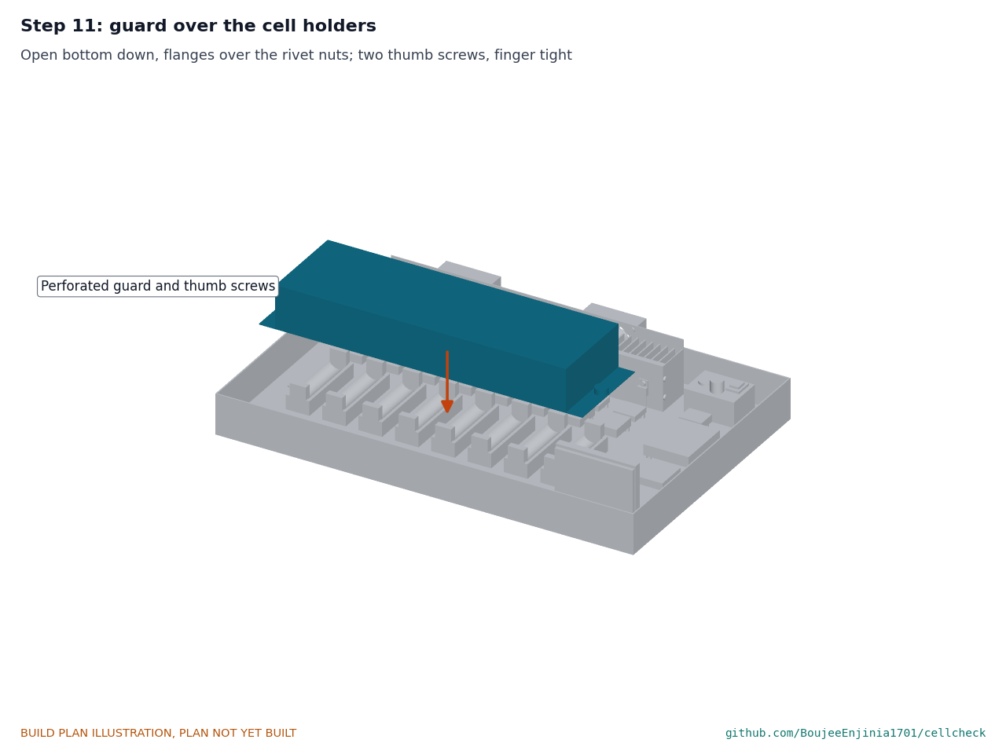
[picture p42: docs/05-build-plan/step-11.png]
Step 11


Open bottom down, flanges round the rivet nuts; two thumb screws, finger tight.

### Step 12: rest rack and adapter on the bench

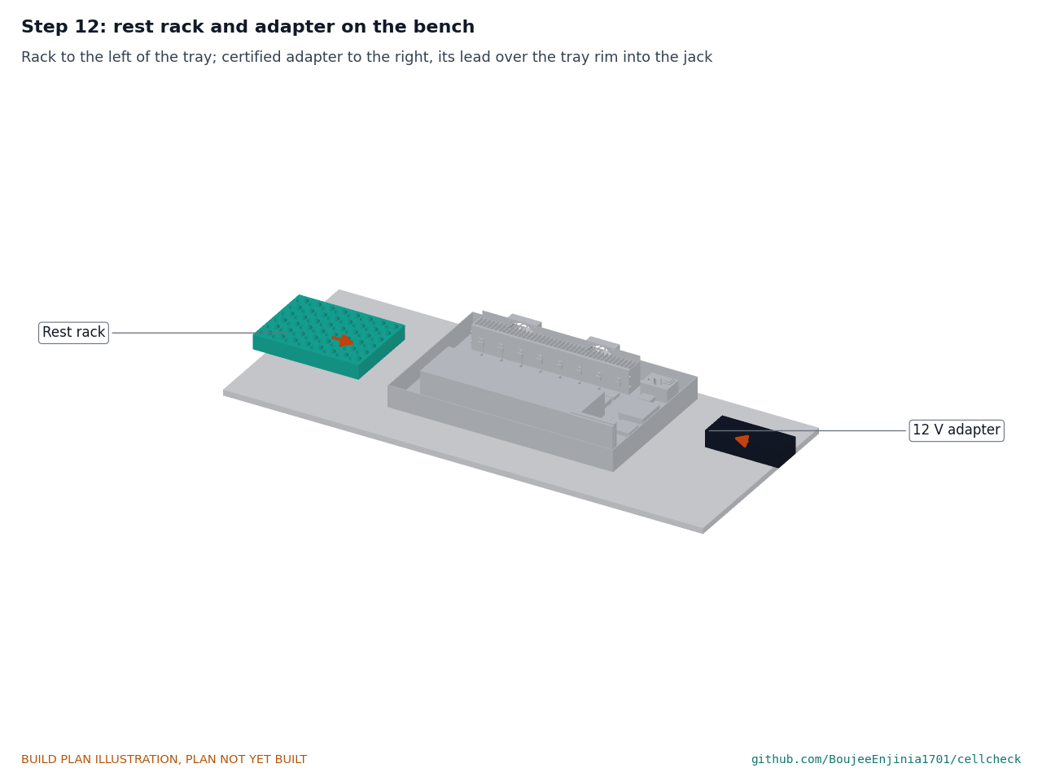
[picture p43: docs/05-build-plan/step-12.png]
Step 12


The rest rack to the left of the tray, the adapter to the right on the bench, its lead over the tray's right rim into the jack. Leave the adapter unplugged from the mains until stop S3.

## 5. First checks

These are the checks a TRL 4 test report would record; this plan only lists them. Requirement numbers are those of CCK-REQ-001.

*Table 3. First checks.*

| Check | Requirement | How | Pass when |
| --- | --- | --- | --- |
| Cells fit | R1 | Put a known-good 18650 and then a 21700 in every holder, guard off, no power | Each seats on both contacts; the clip fits; the guard goes back on without touching a cell or clip |
| Guard seated | R10 | Guard on, thumb screws tight; feeler gauge under every wall | No gap over 0.5 mm anywhere along the walls |
| Supply voltages | R13 | Adapter connected, no cells, inlet fuse in; meter on the 12 V bus and the 5 V rail | 12 V bus at 12.6 V or less; 5 V rail within 5 % |
| Charger voltage | R9, R13 | No cell; meter across each holder's contacts with the charge switch on | 4.20 V within 1 % on every channel |
| Watchdog | R9 | Hold the controller in reset while a channel's charge and load are enabled | Every enable drops within the watchdog time |
| Undervoltage cut | R9 | Bench supply in place of a cell, lowered slowly from 3.0 V with the load enabled | The load drive is removed at 2.5 V, within 0.05 V |
| Voltage reading | R3 | Bench supply at 3.0 and 4.2 V on each channel, against a calibrated meter, then two-point calibration | Each channel within 10 mV after calibration |
| Temperature reading | R7 | Each thermistor beside a reference thermometer at room temperature | Within 2 K |
| Fans and heatsink | R8 | Fans on; tachometer readings at the controller | Both fans read; air comes out of the fin tops |
| Mass and size | R11 | Weigh the unit without the adapter; measure | 5 kg or less (4.94 kg estimated); within 500 x 320 x 120 mm |

## 6. Safety stops

Stop at each point. Carry on only when everything listed is true.

- **S1. Before any cell comes into the workshop.** A non-flammable bench (steel or ceramic tile) with a smoke alarm above it; a Class D or large dry-powder extinguisher or a bucket of dry sand within reach; a lidded metal container of sand for a hot or damaged cell; insulated tools.
- **S2. Before the inlet fuse goes in.** Wiring checks of section 3.11 pass; every transistor tab reads open to the heatsink; with the fuse out, the 12 V bus reads open to the plate and to ground.
- **S3. Before the adapter is plugged into the mains.** The adapter is a certified unit, undamaged, with the right safety marks; no cell is in any holder; the guard is on.
- **S4. Before the first cell goes into a holder.** The charger voltage, watchdog, undervoltage and temperature checks of section 5 pass on every channel.
- **S5. First charge.** One cell that has passed intake (no damage, above 2.0 V), in one channel, guard on, thermistor clip fitted, a person present the whole time. Stop and disconnect if the cell passes 45 °C or rises 8 K above the bench, or reads above 4.25 V.
- **S6. First discharge.** Fans running and read by the controller; hands off the heatsink. Stop if a fan stops or the heatsink passes 70 °C.
- **S7. Before leaving anything unattended.** Only cells in the rest rack, with no current flowing; the grader switched off at the rocker switch and unplugged.

## 7. Tools, skills and workspace

**Tools.** Hacksaw, nibbler or fine-tooth jigsaw for sheet; bench drill or a drill in a stand; drills 2.5 to 12 mm and a step drill; hole saw 54 mm; M3 tap and tap wrench with cutting fluid; blind rivet nut tool for M4; hand rivet tool for 3.2 mm rivets; aviation snips; sheet folder for 1 mm aluminium and 0.8 mm steel up to 330 mm long (or two lengths of hardwood angle clamped in a vice); flat and half-round files; deburring tool; scriber, engineer's square, steel rule and calipers; sharp knife and 12 mm hole punch for the liner; 3D printer with a bed of at least 220 x 170 mm that prints PETG; temperature-controlled soldering iron; wire strippers and crimper; multimeter; bench power supply with an adjustable current limit (0 to 15 V, 0 to 3 A); feeler gauges; scale to 10 kg.

**Skills.** No certified trade is needed. Basic metalwork (marking out, sawing, drilling, tapping, folding thin sheet, setting rivets and rivet nuts), 3D printing, through-hole soldering and crimping, safe use of a bench power supply, and the care with lithium-ion cells set out in section 6. All circuits are extra-low voltage, 12.6 V at most, from a certified adapter; no mains wiring is part of this build.

**Workspace.** A non-flammable bench about 1.2 x 0.6 m for the grader and the rest rack, with the stop S1 equipment; a metalwork corner kept apart from the electronics so chips stay off the boards; a ventilated place for the printer; a well-ventilated or outdoor place to cut ceramic fibre.

**Personal protective equipment.** Safety glasses for cutting, drilling, soldering and every cell test; cut-resistant gloves for sheet work; a dust mask (FFP2 or N95), gloves and long sleeves for ceramic fibre; hearing protection when sawing; no gloves near a turning drill.

## 8. Where the numbers come from

- Model and constructability checks: `cad/src/model.py` (`python cad/src/model.py --check`, 139 checks); STEP and STL exports in `cad/step/` and `cad/stl/`.
- Pictures: `cad/src/build_plan_media.py`, using `.kit/build_views.py`; written to `docs/05-build-plan/` and `cad/drawings/CCK-DWG-101` to `CCK-DWG-110`.
- General arrangement: `cad/drawings/CCK-DWG-001.pdf`, Rev P3.
- Calculations: `docs/04-calcs/01-sizing.md` (CCK-CAL-001 v0.6) and `docs/04-calcs/sizing.py`; size and mass in section 8, cost in section 11, heatsink in section 4, single-fault analysis in section 6.
- Bill of materials: `bom/bom.csv`.
- Decisions: `docs/decisions/0003-design-for-construction.md` (CCK-DDR-003), with CCK-DDR-001 and CCK-DDR-002; decisions made and still open in `docs/06-design-decisions.md` (CCK-DEC-001).
- Requirements: `docs/03-requirements.md` (CCK-REQ-001 v0.8).

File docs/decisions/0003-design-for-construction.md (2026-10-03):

---
doc_id: CCK-DDR-003
title: CellCheck design for construction
project: CellCheck
doc_type: Design decision record
version: "0.5"
status: Draft
date: '2026-10-02'
author: Amish Chadha
license: CERN-OHL-S-2.0
revisions:
- version: "0.1"
  date: '2026-10-01'
  author: Amish Chadha
  change: Changes that make the concept physically buildable, with the reason for each; made under Amish's 2026-09-30 instruction to make the design physically buildable; open for his review
- version: "0.2"
  date: '2026-10-01'
  author: Amish Chadha
  change: Budget treated as a value-engineering target; cost wording only, no number changed
- version: "0.3"
  date: '2026-10-02'
  author: Amish Chadha
  change: Amish accepted A1 and A2 as recommended on 2026-10-02; Tables 1 and 2 still open for his review
- version: "0.4"
  date: '2026-10-02'
  author: Amish Chadha
  change: "Changes P1 to P12 (Table 1) and their knock-on changes (Table 2) accepted by Amish on 2026-10-02"
- version: "0.5"
  date: '2026-10-02'
  author: Amish Chadha
  change: "Consequences updated: finger guards and silicone in the BOM, R12 over the value-engineering target, appearance model brought into line"
---

# 0003: Design for construction

- **Date:** 2026-10-01
- **Status:** accepted. Amish, 2026-10-02: "APPROVED: Design-for-construction changes in 10 repos (CityTwin, CoolShade, PalletPilot, Heliolite, PotholeLog, EarthPress, ReadyKit, CellCheck, CargoMule and ThermaCart)". This covers the changes P1 to P12 in Table 1 and their knock-on changes in Table 2, made under Amish's 2026-09-30 instruction to make the design physically buildable, and is recorded in the design decisions register (CCK-DEC-001). The items in Table 3, which touch the safety case, were accepted as recommended earlier the same day. Amish, 2026-10-02: "i approve your recommendations for all 555 open decisions." A1 and A2 are recorded in the design decisions register (CCK-DEC-001).

## Context

On 2026-09-30 Amish asked for every repo to have an illustrated prototype build plan and wrote: "If you are realising that the design cannot be built as per concept - fix the design assumptions to match and be physically feasible as you draw the illustrations." The CellCheck model of CCK-DDR-001 and CCK-DDR-002 showed what the grader does, and its parts did not overlap, but most of them had no fixing, two had no room for the parts that go in them, and three parts the electronics need were missing. Checking the model with build123d (contacts, overlaps and clearances between every pair of parts) found the problems in Table 1.

The changes keep what CellCheck does: eight channels at the same 40 mm pitch, the same cells, holders, guard size, heatsink, fans, modules, grading method, 12 V input and steel tray. The tray, its liner and the guard keep their materials and thicknesses, so the containment arrangement is unchanged. Every change is in `cad/src/model.py`, which now runs 129 constructability checks (`python cad/src/model.py --check`): parts that must touch do touch, and parts that must stay apart are apart by at least the stated clearance. All 129 pass.

## Decision

*Table 1. Changes made to the model, the BOM and the calculations.*

| # | Problem in the concept | Change made | Why this way |
| --- | --- | --- | --- |
| P1 | The base plate stood on four standoffs resting on the soft ceramic fibre liner, with nothing holding the standoffs or the plate to the tray. | Six rubber feet with M4 studs under the tray (new BOM line 19). Each stud passes up through a 4.5 mm hole in the tray floor into a 12 mm hex standoff standing on the bare steel through a 12 mm hole in the liner; the plate screws down onto the standoffs with six M4 screws. The tray now stands 8 mm off the bench. | One part does two jobs: the foot is also the fixing, so no screw head sits under the tray. The standoffs bear on steel, not on compressible fibre. Lifting the tray off the bench also keeps its hot floor off the bench surface. |
| P2 | The plate was 2 mm aluminium on four standoffs, two of whose screw heads sat under the display stand and the inlet, where they could not be reached. Adding fixings would have taken the mass past the 5 kg limit of R11. | The plate is 1.5 mm aluminium on six standoffs in three columns, 210 mm left, 45 mm left and 120 mm right of centre, 124 mm each side front to back; every screw is reachable from above once the plate is in the tray. | Six supports cut the longest unsupported span to 165 mm, so the thinner plate stays stiff; it saves 0.16 kg and keeps the plate top at the same height, so nothing above it moves. |
| P3 | The cell holders had no fixing, and the cell leads and thermistor leads had no way out from under the closed guard. | Two M3 screws from under the plate into each holder base. Two 16 x 5 mm slots per channel through the plate, edged with grommet strip: one just behind the holder, inside the guard, and one between the charger and the channel board. The leads run under the plate in the 9 mm space above the liner. | The guard stays closed on all four sides and the top, and the leads never cross its edge. |
| P4 | The guard was drawn as a frame of bars standing on the plate with no fixing, and it had to come off at every cell change. | A box folded from one 0.8 mm perforated steel blank, open at the bottom, with corner tabs riveted and an 18 mm flange folded outward at each end. Two M4 blind rivet nuts in the plate and two M4 knurled thumb screws hold the flanges; the guard lifts off after two thumb screws. | Sheet the builder can cut and fold by hand; nothing loose on the bench; no tool needed at a cell change. A rivet nut gives a lasting thread in 1.5 mm aluminium, which is too thin to tap. |
| P5 | The charger modules, channel boards, controller and watchdog board sat directly on the aluminium plate, where their solder joints would short to it, and the controller and watchdog board left only 3 mm beside the right-hand thumb screw. | Every board stands on two 5 mm nylon standoffs with M3 screws from under the plate. The controller and watchdog board move 10 mm to the right. | Insulation from the plate and room for fingers on the thumb screw. |
| P6 | The display stand was 60 mm wide and 55 mm tall, but a 2.8 in display module is about 86 x 50 mm. | A printed stand 88 mm wide with an upright 62 mm tall, at the front right corner of the plate in front of the guard's end flange; the three push buttons sit in 7 mm holes in its foot. | The bought module fits; the stand stays clear of the guard and of every plate screw. The stand's top, 77 mm above the bottom of the tray, is now the highest point; with the feet the unit is 85 mm tall, well inside R11's 120 mm. |
| P7 | The heatsink stood on the plate with no fixing, and the MOSFETs had no clamp to the spine. | Three M3 screws from under the plate into tapped holes in the spine's bottom edge. Each MOSFET is clamped to the spine by one M3 screw with an insulating pad and shoulder washer, into a tapped hole between two fins. | Standard TO-220 mounting; the spine is the only part thick enough to tap. |
| P8 | The fan shroud had no fixing, and its top lip at fin height could not be folded from the same sheet as its 60 mm back. | The shroud is a 1 mm aluminium back with two side flanges folded forward onto the ends of the spine, each held by two M3 screws into tapped holes. The fans screw to the back from the inside before the shroud is fitted. The top lip is dropped. | One folded part, fixed to the heatsink so the air path cannot shift. The calculation note already assumes only half of the fans' free air passes through the fins, so the heatsink result stands. |
| P9 | The thermistor clip was a block resting on top of the cell with nothing holding it. | A printed C-clip, 10 mm long, that springs over the cell and wraps 10 degrees past its sides, with a raised pad that holds the thermistor bead against the cell. One set of eight for 21700 cells and one for 18650. | A clip that holds itself; the bead touches the cell as R7 assumes. |
| P10 | The power inlet was a solid block with its DC jack facing the tray wall 23 mm away, too close for a plug. | An open-bottomed printed housing with the jack, fuse holder and rocker switch on its top face and two screw bosses; the adapter lead comes over the tray's right rim into the jack. | Room for the plug, and no new hole through the tray wall. |
| P11 | Three parts the electronics need had no place: a 5 V supply for the controller, display and channel boards (only 12 V comes in); a home for the op-amp of each load loop and for the series charge switch; and a reachable place for the 3 A channel fuses, which would otherwise have been under the plate. | A 12 V to 5 V buck converter (new BOM line 21) on standoffs in the right-hand bay. BOM line 7 becomes a channel board: the current monitor breakout on a small perfboard carrying the charge switch, the op-amp of the load loop and fuse clips for the 3 A channel fuse. | Parts that the single-fault analysis and the test sequence rely on now exist in the model and the BOM. The fuse can be checked and changed from above. |
| P12 | In the model each cell floated 0.5 mm above its holder groove and 1 mm short of each contact. | The cell rests in the groove and touches the force and sense contacts at both ends. | Matches how a spring holder holds a cell. |

*Table 2. Knock-on changes.*

| Item | Change | Reason |
| --- | --- | --- |
| Mass | 4.91 kg without the adapter (was 4.97 kg): feet, fixings, guard flanges and the converter add about 0.12 kg; the thinner plate takes off 0.16 kg. R11 stays at risk with 0.09 kg of margin. | CCK-CAL-001 v0.3 section 8 |
| Size | 460 x 300 x 85 mm (was 75 mm high): the display stand and the 8 mm feet set the height. | CCK-CAL-001 v0.3 section 8 |
| Cost | Lines 19 (rubber feet, $2.40), 20 (fixings, $4.00) and 21 (5 V converter, $2.00) added: $172.40 estimated, $2.60 under the $175 value-engineering target, so R12 stays within the target. Lines 1 to 5, 7 to 10, 12, 13 and 16 are respecified with the same prices. | CCK-CAL-001 v0.3 section 11 |
| Thermal | Unchanged: the heatsink, fans and fin airflow keep their size and place. | CCK-CAL-001 section 4 |
| Drawings | General arrangement CCK-DWG-001 Rev P2; making sketches CCK-DWG-101 to 110 added. | Follow the model |
| Documents | CCK-CAL-001 v0.3, CCK-PRC-001 v0.5, CCK-REQ-001 v0.5: mass, height and cost updated. No requirement changed status. | Follow the model |

*Table 3. Items that touch the safety case: proposed, then accepted by Amish as recommended on 2026-10-02.*

| # | Question | Options | Recommendation |
| --- | --- | --- | --- |
| A1 | How the guard is held down. It is part of the containment arrangement of R10, and it now lifts off after two thumb screws so that cells can be changed without tools. | (a) two knurled thumb screws, as modelled; (b) two over-centre toggle latches; (c) a hinge along the back edge with one latch at the front. | (a) for the first prototype, and decide for later units after the containment test at TRL 4. A hinge would swing onto the charger row. **Accepted 2026-10-02:** two knurled thumb screws; the TRL 4 containment test is run with the guard held exactly that way, and latches are revisited only if the test or users show the screws being left loose. |
| A2 | The wire slots behind each holder open the space under the guard to the space under the plate. Both are inside the tray, so the tray still contains a venting cell, but hot gas could reach the underside of the electronics. | (a) leave the slots open with grommet strip, as modelled; (b) fill each slot round its leads with high-temperature silicone after wiring. | (b): no new part, about a dollar of sealant, and the guard space is closed again. **Accepted 2026-10-02:** each slot is filled round its leads with high-temperature silicone after wiring. |

## Consequences

- With A1 and A2 accepted, the guard is held by two thumb screws for the first prototype and the TRL 4 containment test is run with it held that way, and each wire slot is sealed round its leads with high-temperature silicone after wiring (build plan CCK-BLD-001, step 9). The silicone is in BOM line 16 and the fan finger guards in line 10 (CCK-DEC-001, items 2 and 9).
- `design_state: constructable` in `project.yaml`. The build plan CCK-BLD-001 shows every component and step in pictures generated from the model (`cad/src/build_plan_media.py`).
- Requirement status after these changes (CCK-CAL-001 v0.3): none not met, three at risk (R5, R6, R11), 13 met on paper, R10 not verifiable at TRL 3. With the finger guards and silicone added on 2026-10-02 (CCK-CAL-001 v0.6) R12 is $2.60 over the value-engineering target ($177.60), so 12 are met.
- The appearance model `cad/src/product_model.py` now follows the constructable design (six feet and standoffs, end-flanged guard with thumb screws, sealed wire slots, lifted boards, finger guards) and its render scenes are exported; the photoreal renders (`media/render-*.png`), `media/card.png` and `media/social-preview.png` are made on Amish's Mac, where Blender is.
- The tray, modules, display and heatsink are chosen at TRL 4; the items in the "to confirm when parts are bought" table of the design decisions register CCK-DEC-001 must be checked then.

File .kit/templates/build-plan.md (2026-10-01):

---
doc_id: PRJ-BLD-001
title: Project prototype build plan
project: Project name
doc_type: Build plan
version: "0.1"
status: Draft
date: YYYY-MM-DD
author: Amish Chadha
license: CERN-OHL-S-2.0
revisions:
  - version: "0.1"
    date: YYYY-MM-DD
    author: Amish Chadha
    change: First build plan; design made constructable
---

# Project prototype build plan

**Plan, not yet built.** How to build the first proof-of-concept prototype, component by component. Building and testing to it is TRL 4 work. Decisions still to be made are kept in the design decisions register (`docs/06-design-decisions.md`), not here.

## 1. What you are building

Every component, pulled apart and numbered in build order

One short paragraph: what the prototype is, how many components, which are made and which are bought, and the main ways they are made.

## 2. What changed to make it buildable

| Component | The concept had | The buildable design has | Why |
| --- | --- | --- | --- |

## 3. Making the components

### 3.1 Component name

Making sketch

**What it is and what it is made from.**

**How to make it.**

1. Mark out ...
2. Cut ...

**How it fits the parts next to it.**

Close-up of the joint

**Check before moving on.**

## 4. Putting it together

### Step 1: ...

Step 1

## 5. First checks

| Check | Requirement | How | Pass when |
| --- | --- | --- | --- |

## 6. Safety stops

## 7. Tools, skills and workspace

## 8. Where the numbers come from

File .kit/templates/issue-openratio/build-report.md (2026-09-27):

---
name: Build report
about: Tell us what happened when you built, printed or tested part of this design
title: "Build report: "
labels: build-report
---

This is a research and educational prototype, not a medical device. It is a TRL 3 concept and is not released for fabrication. If you build any part of it, you do so at your own risk. Reports help everyone.

**What you built** (part, sub-assembly or test)

**Materials, tools and settings**

**What worked**

**What did not work, with photos or measurements if you have them**

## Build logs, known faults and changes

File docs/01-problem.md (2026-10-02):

---
doc_id: CCK-PRB-001
title: CellCheck problem statement
project: CellCheck
doc_type: Problem statement
version: "0.6"
status: Draft
date: '2026-10-02'
author: Amish Chadha
license: CERN-OHL-S-2.0
revisions:
- version: "0.1"
  date: '2026-09-25'
  author: Amish Chadha
  change: Initial scaffold
- version: "0.2"
  date: '2026-09-25'
  author: Amish Chadha
  change: Populate to TRL 2 (problem, prior work, users, context, constraints)
- version: "0.3"
  date: '2026-09-25'
  author: Amish Chadha
  change: Apply CCK-DDR-001 (second-life SwapCell variant, attended operation, budget note); open questions updated
- version: "0.4"
  date: '2026-09-25'
  author: Amish Chadha
  change: Recommendations accepted by Amish (DDR-002)
- version: "0.5"
  date: '2026-10-01'
  author: Amish Chadha
  change: Budget treated as a value-engineering target; cost wording only, no number changed
- version: "0.6"
  date: '2026-10-02'
  author: Amish Chadha
  change: First trial partner decided on 2026-10-02 (CCK-DEC-001, item 3)
---

# CellCheck problem statement

Salvaged lithium-ion cells from laptop, power tool and e-bike packs are cheap and often still usable, but each one is an unknown. Building a pack from untested cells mixes weak, high-resistance and self-discharging cells with good ones, which shortens pack life and raises the risk of a cell overheating. Small repairers and makers need a low-cost, open way to measure every cell and group the good ones into matched sets.

## The problem

Most cells in a discarded pack are not dead. A pack usually leaves service because one parallel group has faded, the pack's electronics have locked out, or the device it powered was retired. Two studies show the scale of the usable remainder:

- IBM Research India measured 32 discarded ThinkPad packs rated at 85 Wh and found a median residual capacity of 73 % of design capacity (mean 64 %), then built lights from the cells that still held a good voltage ([Chandan et al., UrJar, ACM DEV 2014](https://www.dgp.toronto.edu/~mjain/UrJar-DEV-2014.pdf)).
- A German study recovered 1,034 cells from 152 notebook packs and judged about 95.7 % of them free of damage and suitable for further testing, with an average of about 5.3 Wh per cell, roughly half the capacity of a new 18650 cell at the time ([Salinas et al., Journal of Energy Storage, 2019](https://www.sciencedirect.com/science/article/abs/pii/S2352152X18308399)).

The catch is spread. A 2026 study of 92 cells recovered from laptop packs in Colombia found capacities from 0.04 to 2.50 Ah (mean 1.62 Ah, standard deviation 0.53 Ah) and internal resistance up to 418 mΩ, and showed that clustering cells by measured capacity and resistance built a markedly better 24-cell pack than random selection ([Olivero-Ortiz et al., PLOS One, 2026](https://journals.plos.org/plosone/article?id=10.1371%2Fjournal.pone.0353394)). In a series string the weakest cell sets the capacity of the whole pack and is driven hardest at the end of each discharge, so an unmatched pack ages fast and puts its weakest cell under the most stress.

Meanwhile, the default path for these batteries is poor. The world generated 62 million tonnes of e-waste in 2022 and only 22.3 % was documented as collected and recycled; in Africa formal recycling was below 1 % ([UNITAR, Global E-waste Monitor 2024](https://unitar.org/about/news-stories/press/global-e-waste-monitor-2024-electronic-waste-rising-five-times-faster-documented-e-waste-recycling)). Lithium-ion batteries in the waste stream also start fires: the US EPA identified 245 fires at 64 waste facilities from 2013 to 2020 that were caused, or likely caused, by lithium-ion batteries ([US EPA, 2021](https://www.epa.gov/system/files/documents/2021-08/lithium-ion-battery-report-update-7.01_508.pdf)), and UK fire and waste bodies counted more than 1,200 battery fires in bin lorries and waste sites in the year to May 2024, up from about 700 in 2022 ([National Fire Chiefs Council and Material Focus, May 2024](https://nfcc.org.uk/over-1200-battery-fires-in-bin-lorries-and-waste-sites-across-the-uk-in-last-year/)).

What a cell rebuilder can use today falls into three groups:

1. **Single-cell hobby testers.** Open designs such as the [Ultimate Battery Tester](https://github.com/ArminJo/Ultimate-Battery-Tester) (Arduino, capacity and ESR) and the ESP32-based [DIY Smart Multipurpose Battery Tester](https://github.com/opengreenenergy/DIY-Smart-Multipurpose-Battery-Tester) (charge, discharge, capacity and internal resistance) test one or two cells at a time. They measure well but are too slow to sort the dozens of cells a pack needs.
2. **Closed multi-slot chargers and analyzers.** Four-slot consumer charger-analyzers report capacity and a resistance figure, but their methods, accuracy and data export are undocumented, and they do not track self-discharge or produce matched groups.
3. **Laboratory cyclers.** Multi-channel cyclers measure everything to standard methods, such as the two-pulse DC resistance test in IEC 61960 ([summary by Arbin Instruments](https://www.arbin.com/how-to-perform-internal-resistance-measurement-accroding-to-iec-61960-with-arbin.html)), but cost far more than a repair shop or makerspace can spend.

No open, garage-buildable tool covers the whole job: charge, measure capacity, measure resistance with four-wire contacts, record self-discharge after a rest, and turn the results into matched groups with a record for every cell.

## Users and context

| User | Need | Context |
| --- | --- | --- |
| Lab projects | A trusted source of graded cells and a record for each one | Lights and small DC storage packs; a second-life, low-current SwapCell variant for PowerBox (CCK-DDR-001 item 1, decided by Amish, 2026-09-25; needs the SwapCell project's agreement) |
| Repair shops and pack rebuilders | Sort cells from dead packs quickly, reject bad ones, build matched groups | E-bike, laptop and power tool repair; informal repair markets |
| Makerspaces, repair cafés and schools | A safe, documented way to reuse cells and teach battery basics | Supervised benches with basic fire precautions |
| Off-grid energy projects | Low-cost cells for lights, small storage and sensor nodes | Solar home systems, community storage pilots |
| Recyclers and collection points | Separate reusable cells from those that should go to recycling, with a record | Collection and pre-processing sites |

Operating context assumed for the concept: cylindrical 18650 and 21700 lithium-ion cells (LCO, NMC or NCA) and optionally LFP cells of the same sizes, one cell per channel, indoors on a bench at 15 to 35 °C (59 to 95 °F), powered from a certified 12 V DC adapter, with a person present while cells are charging or discharging. Only the self-discharge rest, with no current flowing, may run unattended (CCK-DDR-001 item 2).

## Constraints

- Garage-buildable prototype with a value-engineering target of about $175 USD in parts (`project.yaml`, a hypothetical control target, not a limit), excluding cells. The target was raised from $160 to cover single-fault protection (CCK-DDR-001 item 4, decided by Amish, 2026-09-25).
- Off-the-shelf modules and through-hole or large surface-mount parts only; no custom silicon, no fine-pitch assembly.
- Extra-low voltage only: a certified mains adapter supplies 12 V DC, and nothing inside the unit exceeds 13 V.
- Open hardware (CERN-OHL-S-2.0) and open software (MIT); grading thresholds and results in plain, readable files.
- Research, educational and prototype use. CellCheck is not a certified cell tester, and its grades do not certify a cell or pack as safe.

## Out of scope

- Pack disassembly tools (spot-weld removal and wrapping), covered only as a safety note.
- Pouch, prismatic and button cells; cells larger than 21700.
- Cell recovery by charging deeply discharged cells (below 2.0 V); these are rejected, not revived.
- Building or protecting packs; that is the job of the pack design and its BMS (for example CellGuard for LFP packs).
- Certification testing and any claim that a graded cell meets a safety standard.

## Open questions

- Graded cells in SwapCell packs: CCK-DDR-001 item 1 keeps SwapCell in the pitch and plans a second-life variant. The TRL 3 study (CCK-CAL-001 section 10) finds only a low-current storage pack for PowerBox feasible. Decided by Amish, 2026-09-25: go with recommendation; it needs the SwapCell project's agreement.
- Which partner should supply cells for first trials? Decided by Amish, 2026-10-02 (CCK-DEC-001, item 3): the first candidate to approach, not yet agreed, is a local Repair Café group that already passes laptop batteries to an e-waste or battery collection point, with that collection point as the source of trial cells.
- Unattended operation: charge and discharge attended only, the rest stage may be left (CCK-DDR-001 item 2). Decided by Amish, 2026-09-25: go with recommendation.

> **Safety:** Salvaged lithium-ion cells can hide damage and can overheat, vent and burn during charge or discharge. Any work on them needs a non-flammable surface, a smoke alarm, an extinguisher or sand bucket within reach and a person present while current flows.

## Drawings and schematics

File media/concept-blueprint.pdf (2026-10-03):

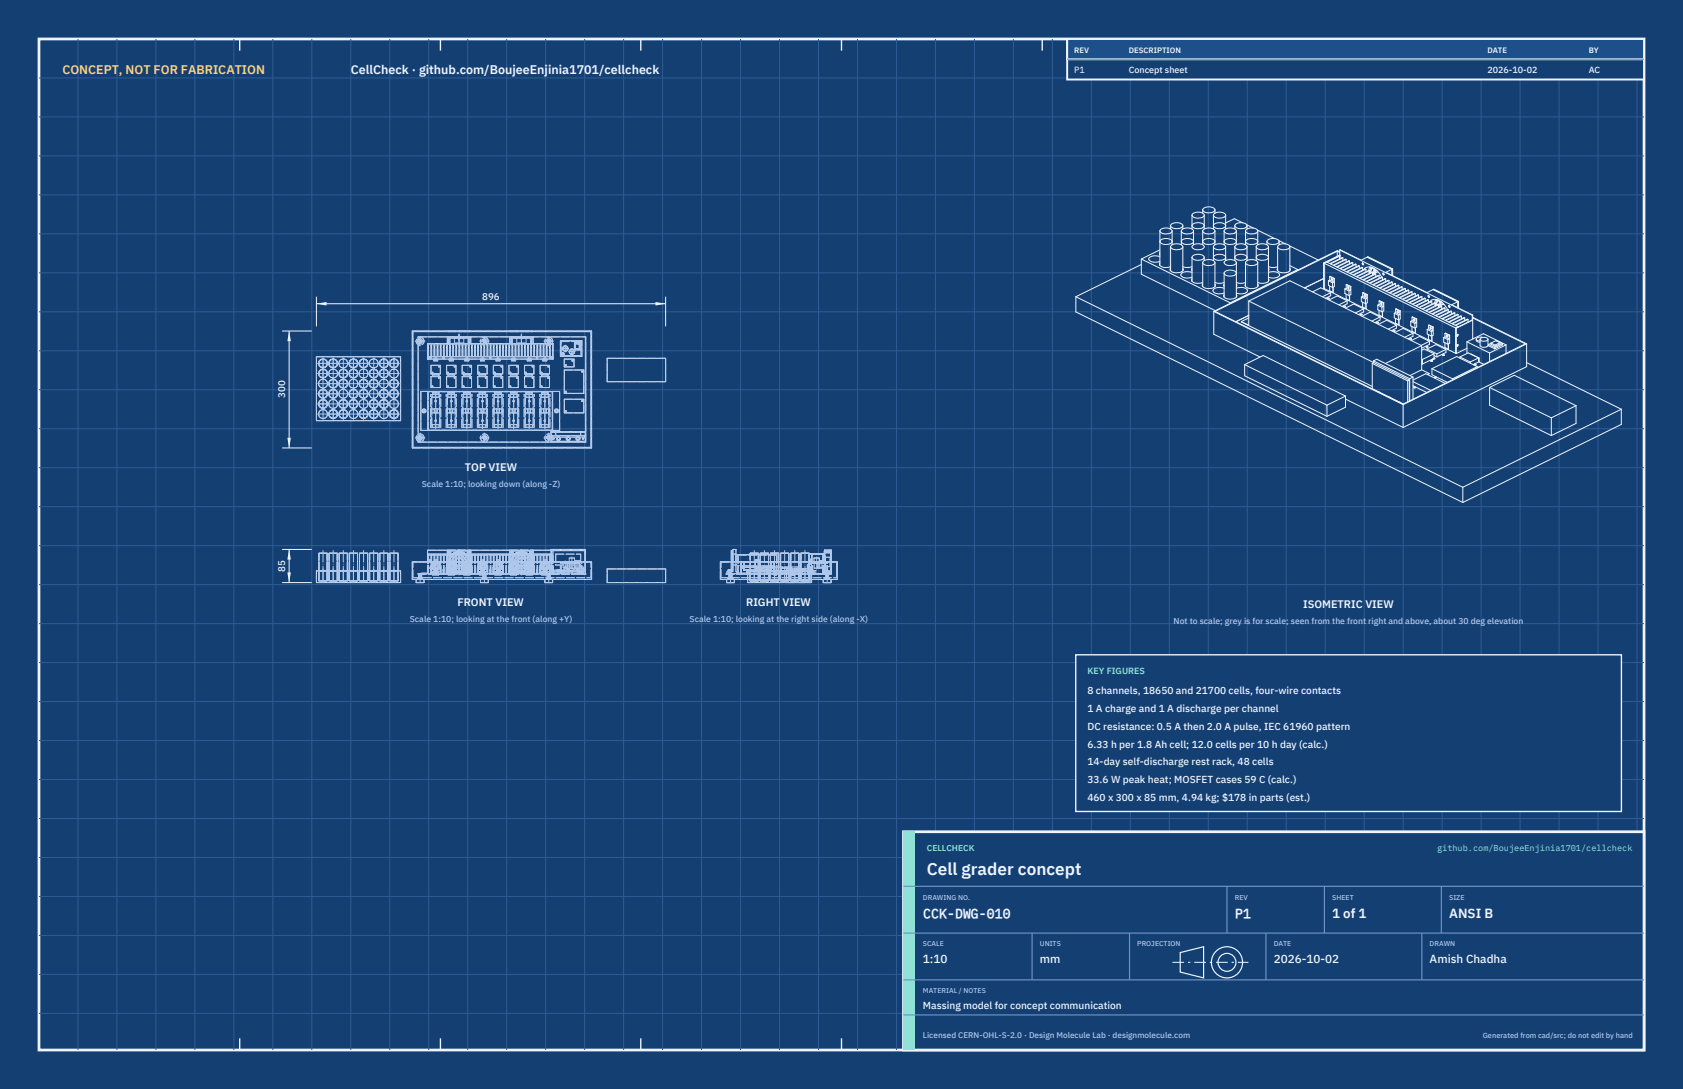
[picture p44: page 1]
CONCEPT, NOT FOR FABRICATION; CellCheck · github.com/BoujeeEnjinia1701/cellcheck; FRONT VIEW; TOP VIEW; RIGHT VIEW; ISOMETRIC VIEW; REV; DESCRIPTION; DATE; Concept sheet; CELLCHECK; github.com/BoujeeEnjinia1701/cellcheck; DRAWING NO. CCK-DWG-010; REV P1; SHEET 1 of 1; SIZE ANSI B; SCALE 1:10; UNITS mm; PROJECTION; DRAWN Amish Chadha; Licensed CERN-OHL-S-2.0 · Design Molecule Lab · designmolecule.com; Generated from cad/src; do not edit by hand

Scale 1:10; looking down (along -Z)

Scale 1:10; looking at the front (along +Y)

Scale 1:10; looking at the right side (along -X)

Not to scale; grey is for scale; seen from the front right and above, about 30 deg elevation

KEY FIGURES
8 channels, 18650 and 21700 cells, four-wire contacts
1 A charge and 1 A discharge per channel
DC resistance: 0.5 A then 2.0 A pulse, IEC 61960 pattern
6.33 h per 1.8 Ah cell; 12.0 cells per 10 h day (calc.)
14-day self-discharge rest rack, 48 cells
33.6 W peak heat; MOSFET cases 59 C (calc.)
460 x 300 x 85 mm, 4.94 kg; $178 in parts (est.)

Cell grader concept

MATERIAL / NOTES
Massing model for concept communication

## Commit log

2026-09-25 Initial scaffold: standard open hardware layout, CERN-OHL-S v2 + MIT licenses
    Claude-Session: https://claude.ai/code/session_01XuhhSU4W6fYhgCfURbrkut
    [bom.csv]
2026-09-25 Populate to TRL 2: problem, requirements, precis, concept media, BOM and README use cases
    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
    [bom.csv]
2026-09-26 Advance to TRL 3: DDR-001, CAL-001 sizing, parametric model with STEP/STL, GA drawing, priced BOM; TRL 4 on hold
    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
    [bom.csv, cellcheck-assembly.step, cellcheck-assembly.stl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]
2026-09-26 Accept all recommendations (DDR-002), switch footer to designmolecule.com, add README write-up with new inspiration point
    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
    [cellcheck-assembly.step, cellcheck-cell-holders.step, cellcheck-heatsink.step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]
2026-09-27 Product appearance model and photoreal renders
    Adds cad/src/product_model.py (appearance model for renders only, all main
    dimensions from model.py) and Blender renders in media/render-*.png,
    captioned with the project, repository and viewing direction. README leads
    with the product render; trl stays 3.
    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
2026-10-01 Image quality pass: legible exploded views, flow diagrams and drawing sheets
    Kit 1.6.1 image layout: the parts list sits in its own column, number bubbles sit on visible parts and never overlap, small parts get a leader, pictures are cropped to the subject, flow labels keep numbers with their units, and sheet captions and the revision table no longer overprint. Concept images, blueprint and general arrangement sheet regenerated; repo-specific labels moved clear of other text and lines.
2026-10-01 Kit 1.7.0: constructable design, illustrated build plan and design decisions register
    The design is now constructable: every part can be made and fits its neighbours, with each change recorded in a Design for construction decision record (made under Amish's 2026-09-30 instruction; ope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
    [bom.csv, cellcheck-assembly.step, cellcheck-assembly.stl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]
2026-10-01 Budget treated as a value-engineering target
    Amish, 2026-10-01: the budget is a hypothetical control target that keeps the design on a value-engineering lens, not a spending limit. Documents now state the value-engineering target and the estima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
2026-10-02 Record Amish's approval of the open-decision recommendations
    Amish approved the recommendation on every open decision in the design decisions register ("i approve your recommendations for all 555 open decisions.", 2026-10-02). Each decision is moved to Decisio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
2026-10-03 Carry approved follow-ups into the design and redo photoreal renders
    Amish approved the follow-up actions from the open-decision sign-off ("APPROVED CHANGES, COMPLETE THESE", 2026-10-02), the design-for-construction change tables in ten repos, the last wave's open dec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
    [bom.csv, cellcheck-assembly.step, cellcheck-assembly.stl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]
2026-10-03 Record Amish's 2026-10-03 decisions; FlatTrike fork and PotPress guard fixes
    Amish, 2026-10-03: "PalletPilot - i accept it"; "FlatTrike - i accept your design recommendation, proceed and execute the solution for fork direction or caster"; "PotPress - move forward with the four guard fixes. I accept the cost."; "GravitySort - i accept your recommendation"; "TIght Margins - i accept the margins"; "Cost over target - i accept all the cost variations and overruns". FlatTrike knuckle forks turned to trail (35 mm trail); PotPress finer mesh, small-hole plates, top beam and crank bracket covers, ISO 13857 desk check now met on paper. Registers, requirements, drawings, pictures, renders and PDFs upd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
